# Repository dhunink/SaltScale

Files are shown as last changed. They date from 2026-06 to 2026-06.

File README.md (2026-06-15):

# SaltScale CadQuery

Parametric CadQuery model for a compact round salt-tank scale for a water softener.

Current mechanical direction: `concept_v5_cartridge_scale`.

Target hardware:
- four 50 kg Kiwi/SparkFun-style load sensors
- round platform for a 290 mm diameter brine/salt tank
- printable quadrant segments, each below 200 x 200 x 200 mm
- removable sensor cartridges with support-free retainers
- side-access electronics bay for ESP32-C3, HX711, battery holder, button, and LED

The physically validated sensor-cartridge baseline is:

```text
cad/src/concept_v5_cartridge_scale.py
cad/exports/concept_v5_cartridge/step/concept_v5_cartridge_assembly.step
cad/exports/concept_v5_cartridge/stl/concept_v5_sensor_cartridge.stl
cad/exports/concept_v5_cartridge/stl/concept_v5_sensor_retainer_clip.stl
```

The older v1-v4 CAD and print-test artifacts are retained for traceability, but
they are no longer the active design. Start with:

```text
docs/project_state_summary.md
docs/concept_v5_cartridge_scale.md
docs/concept_v5_system_architecture.md
docs/archive/concept_v4_legacy_index.md
```

## Build in GitHub Codespaces

Open this repository in Codespaces. The devcontainer installs CadQuery and the small export script.

```bash
python cad/export_concept_v5_cartridge.py
```

Generated files appear in:

```text
cad/exports/
```

## Main parameters

Edit `cad/src/concept_v5_cartridge_scale.py`.

## Design intent

The load path must be:

```text
tank -> upper ring -> load puck -> load sensor -> cartridge -> lower base -> floor
```

Cartridge retainers, cable guides, lift-retention features, and alignment walls
must not bypass the sensor under normal weighing load.

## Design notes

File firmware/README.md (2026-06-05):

# SaltScale Firmware

Firmware is intentionally not implemented yet.

The first firmware task is a bench-only hardware bring-up sketch for:

- Seeed Studio XIAO ESP32C3.
- SparkFun HX711.
- SparkFun Load Sensor Combinator.
- Four 50 kg load sensors.

Initial firmware goal:

- Read raw HX711 values.
- Print raw values over USB serial.
- Avoid Wi-Fi.
- Avoid deep sleep.
- Avoid battery handling.
- Avoid calibration logic.
- Avoid MQTT or product behavior.

See:

- `docs/hardware-bringup-v0.md`

Do not start battery optimization, enclosure electronics, or final calibration until the raw four-sensor bridge is proven on the bench.

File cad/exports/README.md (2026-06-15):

# SaltScale CAD Exports

Generated CAD exports are intentionally kept in the repository so builders can inspect and slice the current design without installing CadQuery first.

## Current Baseline

Active architecture: `concept_v5_cartridge_scale`.

Recommended first STEP to inspect:

```text
cad/exports/concept_v5_cartridge/step/concept_v5_cartridge_assembly.step
```

Validated printable cartridge parts:

```text
cad/exports/concept_v5_cartridge/stl/concept_v5_sensor_cartridge.stl
cad/exports/concept_v5_cartridge/stl/concept_v5_sensor_retainer_clip.stl
```

Current validated details:

- Four-sensor cartridge architecture.
- Measured sensor body: about `34.07 mm` wide and `6.84 mm` thick.
- Raised sensor-cartridge locator walls: `7.1 mm` above the cartridge floor.
- Support-free over-wall cartridge retainer.
- Physical test result: sensor fit is snug with only minimal movement.

Still experimental:

- Upper-ring load puck retention.
- The `0.20 mm` hand-tight keyhole test is the best tested puck fit so far:
  it does not fall out when inverted, but it is still removable by hand and is
  not yet considered a captive/hand-tight final solution.
- `0.35 mm` and `0.50 mm` hand-tight keyhole variants are too loose.
- PETG did not flex enough for the intended side-slide insertion; current tests
  only install by pressing the puck in from above.

## Folder Map

### `concept_v5_cartridge/`

Current baseline exports for the removable sensor cartridge concept.

### `active/`

Legacy active design from the previous v4 architecture. It is retained as prior
art until the full v5 ring replaces it.

Legacy architecture: `concept_v4_integrated_joining`.

Recommended first STEP to inspect:

```text
cad/exports/active/step/concept_v4_one_quadrant_assembly.step
```

Active printable STLs:

```text
cad/exports/active/stl/concept_v4_lower_segment_0.stl
cad/exports/active/stl/concept_v4_upper_segment_0.stl
cad/exports/active/stl/concept_v4_support_grate_bar_x.stl
cad/exports/active/stl/concept_v4_support_grate_bar_y.stl
cad/exports/active/stl/concept_v4_lower_pad.stl
cad/exports/active/stl/concept_v4_upper_pad.stl
cad/exports/active/stl/concept_v4_sensor_quarter_turn_clip.stl
cad/exports/active/stl/concept_v4_sensor_placeholder.stl
cad/exports/active/stl/concept_v4_kiwi_sensor_reference_v1.stl
```

Active v4 includes:

- Four-sensor floating upper/lower architecture.
- Integrated M3 segment joining.
- Top-access upper M3 button-head screws.
- Captured standard M3 nuts.
- No heat-set inserts or dowels by default.
- Support grate clearance at `0.4 mm per side`.
- Round Cup upper-carrier locator retired from active geometry; the upper segment is flat in the sensor area.
- Upper integrated M3 lugs are same-plane with the main upper segment body for flat printing.
- Dimensionally representative `kiwi_sensor_reference_v1` in concept_v4 assemblies.
- Real-sensor stack using `6.84 mm` sensor thickness.
- Removable upper pad with `40 mm` body, `36 mm` upper locating lobe, and `12 mm` contact boss; the pad STL is print-oriented for support-free printing.
- Lower pad revised to `36 mm` rounded-square support.
- Sensor locator revised around the measured `34.07 mm` body with `0.2 mm per side` current test clearance.
- Front sensor locator posts now act as pivots for separate quarter-turn retention clips; clips are anti-lift/handling retention only and are not part of the weighing load path.
- Integrated seam locator clearance validated at `0.3 mm per side`.

### `validated/`

Older validation artifacts that represent accepted v4-era decisions. Some of
these decisions still inform v5, but this folder is not the current print list.

Examples:

```text
cad/exports/validated/stl/test_m3_captured_nut_v1.stl
cad/exports/validated/stl/support_grate_fit_0p4mm_per_side.stl
cad/exports/validated/stl/sensor_station_locator_v3.stl
cad/exports/validated/stl/label_readability_coupon_v1.stl
```

### `experimental/`

Useful v4-era experiments that are not the active default.

Examples:

```text
cad/exports/experimental/stl/concept_v4_upper_lug_recess_block_v1.stl
cad/exports/experimental/stl/concept_v4_integrated_mini_seam_test_v1.stl
cad/exports/experimental/stl/concept_v4_upper_pad_12mm_boss_test_v2.stl
cad/exports/experimental/stl/concept_v4_lower_support_test_v1.stl
cad/exports/experimental/stl/concept_v4_real_sensor_locator_test_v2.stl
cad/exports/experimental/stl/concept_v4_sensor_clip_station_coupon_v2.stl
cad/exports/experimental/stl/printed_lower_seam_wedge_coupon_v2.stl
```

### `rejected/`

Rejected or superseded validation concepts kept for traceability.

Examples:

```text
cad/exports/rejected/stl/concept_v4_upper_pad_sensor_relative_test_v1.stl
cad/exports/rejected/stl/concept_v4_upper_pad_carrier_pocket_test_v1.stl
cad/exports/rejected/stl/concept_v4_upper_pad_pocket_chamfer_square_v1.stl
cad/exports/rejected/stl/concept_v4_upper_pad_pocket_side_entry_v1.stl
cad/exports/rejected/stl/concept_v4_upper_pad_pocket_round_cup_v1.stl
cad/exports/rejected/stl/support_grate_fit_0p6mm_per_side.stl
cad/exports/rejected/stl/support_grate_fit_0p8mm_per_side.stl
```

### `archive/`

Historical exports retained for traceability.

This includes:

- `platform_v1` through `platform_v6`.
- `concept_v1`, `concept_v2`, and `concept_v3` exports.
- Old sensor module exports.
- Old test coupons and duplicate migrated exports.

## Build Behavior

Run:

```text
python3 cad/build.py
```

The build writes future exports into:

```text
cad/exports/active/
cad/exports/validated/
cad/exports/experimental/
cad/exports/rejected/
cad/exports/archive/
```

The old `cad/exports/validation/` folder is superseded by the clearer `validated/`, `experimental/`, and `rejected/` folders.

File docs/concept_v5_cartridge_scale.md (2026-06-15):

# Concept v5 Cartridge Scale

Date: 2026-06-13

Updated: 2026-06-15

## Summary

`concept_v5_cartridge_scale` is a clean-sheet SaltScale concept using the same four Kiwi/SparkFun-style 50 kg sensors, but reorganized around replaceable sensor cartridges, removable load pucks, and a dry outer electronics pod.

The intent is to make the next prototype easier to print, easier to service, and less sensitive to accidental preload around the real sensor body.

## Architecture

- Four-sensor floating upper/lower annular scale.
- Four printed lower segments and four printed upper segments.
- One removable sensor cartridge per quadrant.
- One removable load puck per sensor.
- Outer electronics pod for HX711/MCU/battery/connector packaging.
- No upper-to-lower fasteners.
- Overload stops remain lower-only and sit `1.0 mm` below the upper carrier underside.

## Sensor Cartridge

The cartridge is a separate printable tray:

- Sensor body reference: `34.07 mm` wide, `6.84 mm` thick.
- V2 physical-test corrections:
  - Underside protrusions treated as `4.95 mm` diameter, `1.0 mm` high.
  - Protrusion spacing treated as approximately `18.8 mm` center-to-center.
  - Cartridge relief pockets are widened to `7.0 mm` diameter to absorb measurement and print tolerance.
- V3/final-candidate physical-test corrections:
  - Cartridge footprint reduced to `42 x 39 mm`, close to the compact physical test print.
  - Cartridge side rails reduced to `2.0 mm` above the floor so they do not enter the sensor envelope.
  - Low lateral bumpers locate the sensor with `1.25 mm` nominal clearance instead of squeezing it.
  - Two cable-side posts accept a separate keeper clip.
  - The keeper clip sits `0.65 mm` above the measured sensor top, so it captures lift-out without preload.
- V4 lock-frame correction after physical test:
  - Fragile post-mounted keepers removed.
  - Cartridge footprint increased to `52 x 44 mm` to make room for robust boss supports.
  - Low pocket walls constrain horizontal sensor movement with `0.4 mm` nominal clearance.
  - Retainer is now a broad screw/pin-down frame, not two loose arms.
  - Retainer underside sits `0.35 mm` above the outer metal frame top and bottoms on printed bosses, not on the sensor.
  - Boss holes are `2.8 mm` pilot holes in the cartridge; retainer holes are `3.4 mm` clearance holes.
- V5 clamp correction after lock-frame physical test:
  - Horizontal sensor clearance reduced to `0.15 mm`.
  - Retainer now intentionally overlaps the inactive outer frame by `0.12 mm` for light clamp preload.
  - Boss shoulders lowered with the retainer so the clamp force reaches the sensor frame instead of bottoming plastic-on-plastic.
  - Retainer side/rear/front pads avoid the raised measuring bridge, center button, cable, and glue lump.
- V6 support-free screw-clamp correction:
  - Horizontal sensor clearance reduced further to `0.08 mm` per side.
  - Retainer is one connected flat frame, no disconnected clamp bars.
  - Retainer prints flat without support.
  - Mounting is explicit: two M3 clearance holes through the retainer into `2.8 mm` pilot holes in the cartridge bosses.
  - Long side rails and rear rail are materially connected to both screw eyes.
- V7 fit correction after printed screw-clamp test:
  - Locator clearance is now `0.0 mm` in the model to compensate for measured print fit play.
  - Side and rear locator walls are raised by `1.25 mm`, to `4.25 mm` above the cartridge floor.
  - Cable-side stops stay lower so the cartridge remains support-free and the retainer does not collide with them.
  - Retainer rails are shifted slightly inward and narrowed so they clear the raised walls while still pressing on the inactive outer sensor frame.
  - Bosses now include a `4.2 mm` collar through the retainer hole, protruding `1.25 mm` above the sensor-frame top so the clamp indexes on the boss instead of floating on the sensor.
- V8 cap-retainer correction after snug cartridge test:
  - Sensor cartridge dimensions are left unchanged because the sensor fit is now snug.
  - Retainer is widened into a flat, support-free cap with inner clamp rails and outer wall rails.
  - The raised cartridge walls pass through the gap between those rails instead of colliding with the clamp.
  - Retainer screw eyes are enlarged and tied into the outside rails for a stiffer part.
  - Retainer holes are opened to `5.1 mm`; cartridge boss collars now protrude `2.75 mm` above the sensor-frame top and pass through raised retainer rings.
  - Raised retainer rings add screw-area stiffness and make the boss registration more forgiving in print.
- V9 validated cartridge correction after over-wall physical test:
  - Locator wall height is now `7.1 mm` above the cartridge floor.
  - This is the default cartridge geometry, not a separate test variant.
  - The taller side and rear walls make the real sensor sit snugly with only minimal movement.
  - The over-wall retainer/cap remains support-free and registers around the raised walls.
  - This cartridge/retainer direction is accepted as the baseline for the whole concept.
- Cartridge assembly z: `5.0 mm`, with the sensor top at `16.84 mm`.
- Cable/glue side remains open.
- The sensor is carried by two outboard ledges under the flat perimeter frame, not by the earlier three-bar datum layout.
- The retainer frame is outside the active measuring bridge and avoids the cable/glue lump.
- Side rails slide into matching lower-segment receiver rails.

This should make the sensor serviceable without reprinting or disassembling the whole lower ring.

## Load Pucks

Status after 2026-06-15 PETG keyhole tests:

- The `0.20 mm` hand-tight keyhole variant is the best tested puck retention fit.
- The `0.35 mm` and `0.50 mm` variants are too loose.
- The `0.20 mm` puck does not fall out when the assembly is inverted.
- It is still loose enough to remove by hand without meaningful force, so it is not yet a true hand-tight captive mount.
- PETG does not flex enough for the intended side-slide insertion path; the puck can only be installed reliably by pressing it in from above.
- Therefore the puck interface remains an open design item. Do not treat the side-entry keyhole as validated yet.

Two puck styles are exported:

- `concept_v5_bridge_load_puck`: `12 x 24 mm` rounded bridge boss, intended to match the real raised bridge.
- `concept_v5_round_load_puck`: `12 mm` round boss, retained as a conservative baseline.

Both are standalone printable parts so force-contact tests do not require reprinting the upper segment.

In assembly orientation the bridge puck starts on the sensor top at `z = 16.84 mm`, its main body ends at the upper-carrier underside at `z = 25.0 mm`, and the upper locating lobe enters the support-free socket in the upper segment.

## Electronics Pod

The electronics pod is intentionally outside the salt-ring footprint:

- `78 x 42 x 16 mm` outer envelope.
- Hollow printed box with four cable-entry holes toward the scale.
- Two M3-ish lid screw bosses.

This is still a first-pass packaging envelope, not a sealed enclosure design.

## Exports

Generated files:

```text
cad/exports/concept_v5_cartridge/step/concept_v5_cartridge_assembly.step
cad/exports/concept_v5_cartridge/step/concept_v5_lower_segment_0.step
cad/exports/concept_v5_cartridge/step/concept_v5_upper_segment_0.step
cad/exports/concept_v5_cartridge/step/concept_v5_sensor_cartridge.step
cad/exports/concept_v5_cartridge/step/concept_v5_sensor_retainer_clip.step
cad/exports/concept_v5_cartridge/step/concept_v5_bridge_load_puck.step
cad/exports/concept_v5_cartridge/step/concept_v5_round_load_puck.step
cad/exports/concept_v5_cartridge/step/concept_v5_electronics_pod.step
```

Printable STL counterparts are in:

```text
cad/exports/concept_v5_cartridge/stl/
```

## First Physical Test Order

Print first:

```text
cad/exports/concept_v5_cartridge/stl/concept_v5_sensor_cartridge.stl
cad/exports/concept_v5_cartridge/stl/concept_v5_sensor_retainer_clip.stl
cad/exports/concept_v5_cartridge/stl/concept_v5_bridge_load_puck.stl
cad/exports/concept_v5_cartridge/stl/concept_v5_round_load_puck.stl
```

Check:

- Real sensor drops into the cartridge after normal cleanup.
- Cable/glue side remains free.
- Side and rear walls locate the sensor with minimal horizontal play. The `7.1 mm` wall version has been physically validated.
- Retainer drops over both boss collars and lightly clamps the inactive outer frame.
- Retainer rails do not touch the raised measuring bridge, center button, cable, or glue lump.
- Two screws or printed pins through the retainer holes hold the clamp down into the cartridge bosses.
- Bridge puck contacts the intended raised bridge/button area.
- Round puck remains a usable fallback.

Print second:

```text
cad/exports/concept_v5_cartridge/stl/concept_v5_lower_segment_0.stl
cad/exports/concept_v5_cartridge/stl/concept_v5_upper_segment_0.stl
```

Check cartridge slide-in feel, upper/lower clearance, and overload-stop gap before printing all quadrants.

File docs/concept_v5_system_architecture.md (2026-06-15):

# Concept v5 System Architecture

Date: 2026-06-13

Updated: 2026-06-15

## Design Decision

The puck is part of the upper load path and must be lightly captive in the upper ring. It must not be a loose part between the sensor and upper platform.

The capture feature must not become the normal force path. In normal weighing, force should travel:

```text
upper ring -> puck shoulder/contact -> sensor measuring bridge -> sensor cartridge -> lower ring
```

All other geometry is retention, assembly guidance, overload protection, or transport safety.

The sensor cartridge decision is now stronger than the puck decision: the `7.1 mm` raised-wall cartridge with the over-wall retainer is physically validated and should be treated as the concept-v5 baseline. The puck keyhole/captive concept is still experimental.

## Why The Keyhole Concept Is Suspicious

The first keyhole/T-slot coupon made the puck captive, but it also made the capture geometry look like a sliding fit in the load path. That is risky for a weighing design because sliding contact can add:

- lateral force into the sensor,
- friction and hysteresis,
- sensitivity to print tolerance and surface texture,
- overconstraint between the four sensor stations.

For a low-cost printed scale, a little clearance in non-load-bearing retainers is better than a precise sliding interface that accidentally carries load.

## Reference Principles

Common load-cell and weigh-module design guidance tends to converge on these principles:

- Introduce load as close as possible to the intended measuring axis.
- Avoid side loads, torque, bending moments, and force shunts.
- Use a defined load button, ball/cup, rocker, or similar contact when self-alignment matters.
- Let overload stops and transport retainers be separate from the normal measuring load path.
- Avoid overconstraining a floating platform; constrain only the degrees of freedom needed for safety and repeatability.

Useful reference families:

- Load-cell and weigh-module application guides from manufacturers such as HBK/HBM, Flintec, Interface, Rice Lake, Vishay/VPG, and METTLER TOLEDO.
- Kinematic coupling and exact-constraint design literature for the broader principle of avoiding overconstraint.
- OIML R60 and NIST Handbook 44 as standards context for load cells and weighing devices, though they are not product design tutorials.

## Proposed Mechanical Architecture

### Lower Ring

The lower ring is the fixed base.

- Holds four removable sensor cartridges.
- Carries overload stops.
- Carries wire routing and electronics interfaces.
- Segment joints should use printed sliding/wedge/dovetail features where possible, with minimal metal fasteners.
- It must never directly support the upper ring in normal weighing.

### Sensor Cartridge

The cartridge is a serviceable sensor station.

- Sensor is laterally snug in the printed pocket.
- Sensor is held down by the support-free over-wall retainer.
- The validated locator walls are `7.1 mm` above the cartridge floor.
- The 2026-06-15 print test confirmed that this wall height gives the desired snug sensor fit.
- Sensor bridge, button, glue, cable, and active flexing areas remain free.
- Cartridge and retainer are lower-ring components, not part of the upper load path.

### Captive Puck

The puck is retained by the upper ring but mechanically contacts the sensor.

- Puck lower face contacts the sensor bridge area.
- Puck upper shoulder/contact face carries load from the upper ring.
- Captive head/neck should prevent drop-out without becoming the normal force path.
- 2026-06-15 PETG tests showed that `0.20 mm` radial clearance is the best tested head fit; `0.35 mm` and `0.50 mm` are too loose.
- The `0.20 mm` puck stays in place when inverted but can still be removed by hand without meaningful force.
- The intended side-slide insertion path did not work in PETG; PETG gives too little and the puck installs only by top-down pressing.
- Therefore the puck is not yet a validated captive mount. The next concept should avoid relying on elastic side-slide insertion unless a compliant feature is added.

### Upper Ring

The upper ring is the floating load receptor.

- It carries the captive puck cages.
- It transfers load only through the four pucks.
- It has no normal contact with lower ring, cartridge retainers, or overload stops.
- It can include non-contact lateral guards, but those need measurable clearance.

### Upper/Lower Retention

The upper and lower rings need transport/lift retention, but not a rigid connection.

- Use printed safety clips or captive hooks at the perimeter.
- Retention features should have vertical free play in normal use.
- They should engage only when the scale is lifted, inverted, or overloaded.

### Overload Stops

Overload stops are independent lower-ring features.

- Set the free gap around `0.8-1.2 mm` initially.
- Stops should contact the upper ring before the sensor is permanently damaged.
- Stops should not touch during ordinary weighing.

## Next Test Direction

The next puck print should move away from the current rigid side-slide keyhole and test one of these directions:

- top-down insertion with a separate printed keeper or cover,
- a compliant latch/finger that is not in the load path,
- a two-piece upper-ring insert that captures the puck after placement,
- or a captive-but-serviceable puck that is retained by the final upper/lower assembly rather than by a snap/keyhole alone.

Success criteria:

- Puck cannot fall out when the upper ring is inverted.
- Puck cannot be removed without a deliberate service motion.
- Puck can still self-seat slightly on the sensor.
- Upper ring presses the puck via its load shoulder/contact face, not via the keeper.
- Retention can be printed without support and with minimal metal fasteners.
- No underside supports are required for any printed part.

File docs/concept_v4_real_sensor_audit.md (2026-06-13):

# Concept v4 Real Sensor Audit

Date: 2026-06-11

## Scope

This audit reviews the current `concept_v4` assembly after integrating `kiwi_sensor_reference_v1`.

It does not redesign concept_v4 and does not modify CAD. It evaluates the current geometry against the measured Kiwi/SparkFun-style sensor dimensions and the supplied reference photos.

Measured sensor inputs:

- Sensor body width: `34.07 mm`.
- Sensor body thickness: `6.84 mm`.
- Photos show a rounded outer metal frame, central sprung/load plate, central raised load button/bridge, and cable exiting from one side.

## 1. Actual Stack Geometry

Current CAD values:

| Feature | Current value |
| --- | ---: |
| Kiwi reference metal body | `34.07 x 34.07 x 6.84 mm` |
| Kiwi reference total body including cable visual | `58.07 x 34.07 x 6.84 mm` |
| Lower pad | `44.0 x 44.0 x 2.0 mm` |
| Upper pad | `56.0 mm diameter x 3.0 mm` |
| Round cup inner diameter | `56.9 mm` |
| Round cup outer diameter | `64.9 mm` |
| Round cup wall thickness | `4.0 mm` |
| Round cup height | `4.0 mm` |
| Sensor locator cavity, approximate | `39.0 x 39.0 mm` |

Current vertical stack positions:

| Feature | Z range |
| --- | ---: |
| Lower pad | `8.0..10.0 mm` |
| Kiwi reference sensor | `10.0..16.84 mm` |
| Upper pad | `22.0..25.0 mm` |
| Overload stop top | `21.0 mm` |

Important finding:

- The current stack still uses the old `12.0 mm` sensor-placeholder height for upper-pad placement.
- The real Kiwi reference is `6.84 mm` thick.
- Therefore the current assembly has a `5.16 mm` vertical gap between the top of the Kiwi sensor reference and the bottom of the upper pad.

That means the current assembly is not a physically closed weighing stack with the real sensor. This audit reports the issue but does not change the stack height.

## 2. Contact Analysis

### Upper pad to sensor

Current CAD contact:

- No contact.
- The upper pad bottom is at `z = 22.0 mm`.
- The Kiwi sensor top is at `z = 16.84 mm`.
- Gap: `5.16 mm`.

If the vertical stack were corrected without changing pad diameter, the upper pad would be very broad relative to the real sensor:

- Upper pad diameter: `56.0 mm`.
- Sensor body width: `34.07 mm`.
- Pad surplus over sensor width: `21.93 mm` total.

The photos suggest the intended load-sensitive region is the central raised button/bridge area, not the whole outer frame. A `56 mm` round pad is therefore likely too large for controlled loading. It may contact or overhang areas that should not receive the primary upper load.

Assessment:

- Current state: upper pad does not contact the sensor.
- Size: likely oversized.
- Load path confidence: low until upper contact geometry is redesigned and tested.

### Lower pad to sensor

Current CAD contact:

- The lower pad top is at `z = 10.0 mm`.
- The Kiwi sensor bottom starts at `z = 10.0 mm`.
- So the lower pad contacts the underside of the sensor reference.

Size comparison:

- Lower pad: `44.0 x 44.0 mm`.
- Sensor body: `34.07 x 34.07 mm`.
- Lower pad surplus: `9.93 mm` total, about `4.97 mm` per side.

The lower pad is oversized relative to the measured sensor body, but less dramatically than the upper pad. A broad lower support may be acceptable if the sensor is designed to sit on its outer frame. However, the current pad likely supports more of the sensor footprint than necessary.

Assessment:

- Current state: lower pad contacts the sensor.
- Size: somewhat oversized.
- Load path confidence: medium; verify against real sensor underside behavior.

### Does the load enter the intended sensor region?

Currently, no. Because the upper pad does not touch the sensor, the vertical load path is open in the CAD assembly.

After stack-height correction, the current upper pad diameter would likely be too broad to guarantee that load enters only through the intended central sensor region. The photos show a central raised button/bridge and a distinct outer frame. The upper contact should probably be smaller and centered on the load button/bridge region, but that is a future CAD change, not part of this audit.

## 3. Locator Analysis

Current approximate sensor locator cavity:

- CAD cavity target: `39.0 x 39.0 mm`.
- Measured sensor body: `34.07 x 34.07 mm`.
- Total clearance: `4.93 mm`.
- Clearance per side: `2.465 mm`.

This does not reflect the recently validated `0.3 mm per side` seam-locator philosophy. That validation applies to same-layer segment seam locators, not the sensor station. However, the sensor locator is now much looser than expected for a real sensor-shaped locator.

Current sensor locator implications:

- It will not precisely locate the real sensor.
- It may allow noticeable sensor sliding or rotation before load is applied.
- It may still be serviceable and tolerant, but it is not a controlled fit.
- The cable exit side remains directionally useful, but the sensor body clearance is too large for accurate positioning.

Assessment:

- Current state: serviceable but loose.
- Size: oversized.
- Load-path risk: medium, because sensor drift could affect repeatability or pad alignment.

## 4. Overload Stop Analysis

Current nominal geometry:

- Overload stop top: `z = 21.0 mm`.
- Upper pad bottom: `z = 22.0 mm`.
- Nominal unloaded clearance to the current upper pad: `1.0 mm`.

This is the intended overload travel before engagement in the old stack model.

With the real Kiwi sensor reference inserted, the stack is not closed:

- Kiwi sensor top: `z = 16.84 mm`.
- Overload stop top: `z = 21.0 mm`.
- Upper pad bottom: `z = 22.0 mm`.

Because the upper pad is currently floating `5.16 mm` above the sensor, overload-stop behavior is not physically meaningful until the sensor stack height is corrected. In the current assembly, the upper structure would have to move downward far more than intended before the sensor is even contacted.

Assessment:

- Current nominal stop gap: `1.0 mm` to upper pad.
- Real-sensor stack validity: not valid yet.
- Expected overload behavior: must be re-evaluated after upper pad/contact geometry is corrected.

## 5. Recommendations

### Upper pad

Classification: **CHANGE**

Reasons:

- Does not contact the real sensor in the current stack.
- Diameter is likely too large for the intended central load path.
- It may load the outer frame rather than the central load button/bridge if stack height is corrected without resizing.

Recommended next adjustment:

- Rework upper contact geometry around the real sensor height and central raised load region.
- Use the photos to target the central load button/bridge, not the entire outer frame.

### Lower pad

Classification: **REVIEW**

Reasons:

- It contacts the sensor correctly in Z.
- It is about `9.93 mm` wider than the measured sensor body.
- The broad support may be acceptable if it supports the lower outer frame, but this should be confirmed physically.

Recommended next adjustment:

- Check the real sensor underside and decide whether lower support should remain broad or become shaped to the metal frame.

### Round cup

Classification: **REVIEW**

Reasons:

- The cup is correct for the current `56 mm` upper pad.
- If the upper pad changes, the cup will almost certainly need to change with it.
- The cup itself is not the immediate problem; it is downstream of the upper pad diameter.

Recommended next adjustment:

- Do not change the cup independently.
- Revisit after choosing the corrected upper pad diameter/contact shape.

### Sensor locator

Classification: **CHANGE**

Reasons:

- Current cavity is about `39.0 mm` for a `34.07 mm` sensor body.
- Clearance is about `2.465 mm per side`, which is too loose for reliable positioning.
- It is serviceable, but not a precision locator.

Recommended next adjustment:

- Create a real-sensor locator revision using the `34.07 mm` measured body width.
- Keep enough PETG tolerance and cable clearance, but reduce body clearance substantially.
- Preserve outside removal and avoid any upper-to-lower bypass.

### Overload stops

Classification: **REVIEW**

Reasons:

- The intended nominal stop gap is `1.0 mm` to the current upper pad position.
- The current real-sensor stack has a `5.16 mm` vertical gap, so the overload-stop relationship is invalid until the stack is corrected.

Recommended next adjustment:

- Recalculate overload stop height only after upper pad and sensor contact geometry are corrected.
- Keep the overload stop concept, but do not trust the current stop height with the real sensor.

## What Is Already Correct

- The Kiwi sensor reference is now much closer to the real hardware than the old block placeholder.
- Cable exit direction is represented and remains compatible with outside service access.
- Lower pad and sensor currently meet in Z.
- Upper/lower architecture remains mechanically separate.
- No upper-to-lower load bypass has been introduced by the reference sensor model.
- The Round Cup concept remains mechanically clean, but it is tied to an upper pad that now appears too large.

## What Remains Oversized

- Upper pad: strongly oversized relative to the sensor body and likely load region.
- Sensor locator cavity: clearly oversized relative to the measured sensor body.
- Lower pad: moderately oversized, but may still be acceptable depending on sensor underside support.
- Round cup: oversized only because it follows the current oversized upper pad.

## What Should Be Adjusted Next

Next CAD work should focus on a real-hardware sensor station revision, not on the full ring:

1. Correct the vertical stack for the `6.84 mm` sensor thickness.
2. Redesign the upper pad/contact area around the central load region.
3. Tighten the sensor locator around the `34.07 mm` body while preserving outside removal.
4. Re-evaluate the lower pad support footprint.
5. Recalculate overload stop height after the corrected stack is defined.

Do not print a full concept_v4 segment until these real-sensor stack issues are resolved.

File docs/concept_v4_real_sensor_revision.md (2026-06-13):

# Concept v4 Real Sensor Revision

Date: 2026-06-11

## Summary

This revision updates `concept_v4` around the measured Kiwi/SparkFun-style sensor while preserving the existing SaltScale architecture.

Preserved architecture:

- Four-sensor floating upper/lower platform.
- Upper and lower remain mechanically separate.
- Integrated M3 segment joining remains unchanged.
- No heat-set inserts or metal dowels as default.
- No upper-to-lower fasteners, clips, bridges, or locator features.
- Round Cup upper-carrier geometry is retired; the upper segment remains flat in the sensor area.
- Upper pad is now carrier-located by a `36 mm` upper locating lobe and an open-to-inner-edge upper-carrier socket.
- Upper integrated M3 lugs are same-plane with the main upper segment body for flat printing.

Main real-sensor changes:

- Sensor thickness is now treated as `6.84 mm` instead of the old `12.0 mm` placeholder stack.
- The upper pad now reaches the sensor with a smaller central contact boss.
- The lower pad is reduced to a `36 mm` rounded-square support.
- The sensor locator is tightened around the measured `34.07 mm` sensor body.
- Overload stop height is recalculated for the corrected stack.

## Corrected Stack Height

Measured sensor dimensions used:

| Feature | Value |
| --- | ---: |
| Sensor body width | `34.07 mm` |
| Sensor body thickness | `6.84 mm` |

Corrected stack:

| Feature | Z range |
| --- | ---: |
| Lower pad | `8.00..10.00 mm` |
| Kiwi sensor reference | `10.00..16.84 mm` |
| Upper pad total | `16.84..25.00 mm` |
| Upper pad contact boss | `16.84..22.00 mm` |
| Upper pad 40 mm body and inward key | `22.00..25.00 mm` |
| Upper carrier underside | `25.00 mm` |

The old `5.16 mm` vertical gap is removed. The upper pad now contacts the intended upper load-entry region of the Kiwi reference stack.

## Upper Pad Revision

The previous `56 mm` flat upper pad was oversized as a force-contact surface.

The new active upper pad has two functional zones:

| Zone | Geometry | Purpose |
| --- | --- | --- |
| Upper body | `40 mm` round body, `3 mm` thick | Bears against the flat upper carrier underside and remains easy to handle |
| Lower contact boss | `12 mm` round boss, `5.16 mm` tall | Introduces load into the sensor's central raised button/bridge region |

The Round Cup carrier locator was removed from the active upper segment because it created downward cup/rim geometry that compromised flat, support-free printing. The active validation coupon is one standalone upper pad only:

- `40 mm` upper pad body.
- `36 mm` upper locating lobe for carrier-relative positioning.
- `12 mm` round lower contact boss.
- No upper-carrier cup geometry.

Chosen default: **`12 mm` round boss**.

Rationale:

- Smaller and cleaner than the old `56 mm` flat contact.
- Large enough to print reliably in PETG.
- Small enough to avoid intentionally loading the full outer sensor frame from above.
- Good first default before any more specialized bridge-shaped contact is proven.

## Lower Pad Revision

The previous `44 x 44 mm` lower pad was oversized for the measured `34.07 mm` sensor body.

The new active lower pad is:

- `36 x 36 mm` rounded square.
- `2 mm` thick.
- `4 mm` corner radius.

The lower support coupon compares the current lower support direction against alternatives:

- Current-style `44 mm` square reference.
- `36 mm` rounded-square support.
- `36 mm` frame/ring support with central relief.

Chosen default: **`36 mm` rounded-square support**.

Rationale:

- Close to the measured sensor body size while leaving practical tolerance.
- Simpler and less fragile than the frame/ring support.
- More likely to support the real lower frame evenly than a very small pad.
- Still needs physical confirmation with the real sensor underside.

## Sensor Locator Revision

The old locator cavity was about `39 mm`, giving roughly `2.465 mm per side` clearance around the measured sensor body. That was too loose for a real sensor locator.

The new active sensor locator uses:

- Sensor body reference width: `34.07 mm`.
- Default body clearance: `0.4 mm per side`.
- Approximate target cavity: `34.87 mm`.
- Low v3-style broken locator features.
- Open cable side with relief so the sensor can still be removed outward.

Multi-variant locator testing has been retired. The project now uses one practical default.

Chosen default: **`0.4 mm per side`**.

Rationale:

- The real Kiwi sensor is available for direct fit testing.
- Very loose fits are already known to be undesirable.
- `0.4 mm per side` is the active decision point: tight enough to locate, still PETG-realistic.
- Locator features position the sensor only; they must not carry vertical load.

## Overload Stop Revision

The overload stop height has been recalculated for the corrected real-sensor stack.

Current values:

| Feature | Value |
| --- | ---: |
| Upper carrier underside | `25.00 mm` |
| Overload stop top | `24.00 mm` |
| Nominal unloaded clearance | `1.00 mm` |
| Expected overload travel before engagement | `1.00 mm` |

The stops are lower-base-only features. They should not touch the upper carrier during normal unloaded assembly. Under overload, the floating upper structure can travel about `1 mm` before the stops engage.

## Validation Exports

New compact validation prints:

```text
cad/exports/experimental/stl/concept_v4_upper_pad_12mm_boss_test_v2.stl
cad/exports/experimental/stl/concept_v4_lower_support_test_v1.stl
cad/exports/experimental/stl/concept_v4_real_sensor_locator_test_v2.stl
```

Corresponding STEP files are exported in:

```text
cad/exports/experimental/step/
```

Active updated printable parts include:

```text
cad/exports/active/stl/concept_v4_upper_pad.stl
cad/exports/active/stl/concept_v4_lower_pad.stl
cad/exports/active/stl/concept_v4_lower_segment_0.stl
cad/exports/active/stl/concept_v4_upper_segment_0.stl
cad/exports/active/stl/concept_v4_kiwi_sensor_reference_v1.stl
```

Updated assembly STEP files:

```text
cad/exports/active/step/concept_v4_assembly.step
cad/exports/active/step/concept_v4_exploded_assembly.step
cad/exports/active/step/concept_v4_one_quadrant_assembly.step
```

## Recommended Print Order

Print first as one practical plate:

```text
cad/exports/experimental/stl/concept_v4_real_sensor_locator_test_v2.stl
cad/exports/experimental/stl/concept_v4_upper_pad_12mm_boss_test_v2.stl
```

Reason:

- Upper force introduction is the highest-risk real-sensor geometry.
- The `12 mm` round boss is now the active default; this print validates the single chosen pad rather than comparing alternatives.

Print second:

```text
cad/exports/experimental/stl/concept_v4_real_sensor_locator_test_v2.stl
```

Reason:

- The sensor must remain removable but not rattle around.

Print third:

```text
cad/exports/experimental/stl/concept_v4_lower_support_test_v1.stl
```

Reason:

- Lower support is important, but the current `36 mm` rounded-square default is less risky than the upper load-entry surface.

## Inspection Recommendation

Inspect first:

```text
cad/exports/active/step/concept_v4_one_quadrant_assembly.step
```

Check specifically:

- Upper pad boss contacts the central Kiwi load region.
- Upper pad body bears against the flat upper carrier underside while the `36 mm` upper lobe seats in the open-to-inner-edge socket; no Round Cup geometry remains active.
- Lower pad supports the sensor body without obvious cable/glue conflict.
- Sensor locator remains lower-only and does not touch the upper pad or carrier.
- Overload stops remain clear during normal assembly.

## Remaining Risks

- The exact load sensitivity of the central bridge/button must be tested physically.
- The underside support behavior of the real stamped metal sensor is still partly inferred from photos.
- The active `0.4 mm` sensor-locator clearance has already felt loose in one physical test; the separate `0.2 mm` v3 locator coupon is the next validation print.
- Overload stop behavior should be checked after the upper contact boss and locator are validated.
- PETG creep around the contact boss and pads remains untested.

## Sensor Retention Update

The next concept_v4 validation direction uses `0.2 mm` per-side sensor locator clearance and separate quarter-turn clips on the two front round posts. The clips are retention-only: they prevent accidental lift-out during handling, but they must not preload the Kiwi sensor or carry vertical measuring force. The sensor still rests on the lower pad and is loaded by the upper pad's 12 mm boss.

Print `cad/exports/experimental/stl/concept_v4_sensor_clip_station_coupon_v2.stl` with two copies of `cad/exports/active/stl/concept_v4_sensor_quarter_turn_clip.stl` before printing a full lower segment. Coupon v2 uses a larger cropped base so all fixed pillars and stops grow from solid printed geometry.

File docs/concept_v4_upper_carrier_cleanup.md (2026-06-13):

# Concept v4 Upper Carrier Cleanup

Date: 2026-06-11

## Summary

This cleanup resolves the upper-pad / upper-carrier integration issues in `concept_v4`.

The active design now uses:

- A support-free upper segment with no lower protruding upper seam lugs.
- A removable one-piece upper pad.
- A `40 mm` upper pad body.
- A `12 mm` lower contact boss for the Kiwi sensor load-entry region.
- A `36 mm` upper locating lobe on the pad.
- A matching open-to-inner-edge socket/notch in the upper carrier.

The Round Cup remains rejected as active geometry. There is no underside cup, no through-hole boss, no sensor-relative locator, no fragile tabs, and no separate retainer plug in the active design.

## What Was Removed

The cleanup removes the overlapping upper-pad concepts from the active assembly:

- Round Cup underside cup/rim geometry.
- Circular upper-pad land disk geometry.
- The earlier key-only notch that looked like a locator but did not positively engage the carrier.
- The separate upper-pad retainer plug experiment.
- Any floating disk-like construction bodies near the sensor stack.

No sensor-station, lower-pad, lower-base, support-grate, or integrated M3 seam architecture was redesigned.

## Final Retention Method

The upper pad is located by a drop-in open socket:

1. The upper pad has a `36 mm` upper locating lobe above the `40 mm` pad body.
2. The upper carrier has a matching open-to-inner-edge socket at each sensor station.
3. The socket is larger than the lobe by `0.6 mm per side`.
4. A `22 mm` throat connects the socket to the inner edge.

The lobe drops into the socket when the upper carrier is lowered onto the pad. The socket side walls constrain the pad laterally, so the pad cannot drift sideways during normal handling. The narrowed throat prevents the lobe from sliding out through the inner edge. The pad remains removable by lifting the upper carrier and taking the pad out by hand.

This is carrier-relative retention. It does not depend on the sensor for locating and does not create an upper-to-lower bypass.

## Assembly Explanation

Normal assembly order for one sensor stack:

1. Place the lower pad into the lower sensor station.
2. Place the Kiwi sensor on the lower pad with the cable exiting outward.
3. Place the upper pad on the sensor, with the `12 mm` boss facing downward.
4. Align the pad's `36 mm` upper lobe with the upper carrier's open socket.
5. Lower the upper carrier onto the upper pad.
6. Confirm the lobe is seated in the socket and the `40 mm` pad body bears against the flat underside of the upper carrier.

The measurement load path remains:

```text
upper carrier
-> 40 mm upper pad body/shoulder
-> 12 mm lower contact boss
-> Kiwi sensor central load region
-> lower pad
-> lower base
-> floor
```

The locating lobe is not intended as the primary force-contact surface; it is a lateral positioning feature.

## Why It Is Support-Free

Upper segment:

- The upper integrated M3 lugs are same-plane with the main upper segment body.
- There is no material below the main upper body plane.
- The pad locator is an open-to-inner-edge socket, not a blind underside pocket.
- The socket and throat are through-cuts, so they do not create hidden bridges.

Upper pad:

- The active STL is exported in print orientation with the upper locating lobe on the bed.
- The `40 mm` body overhangs the `36 mm` lobe by about `2 mm per side`, which is intended to print as a short support-free PETG shoulder.
- The `12 mm` contact boss prints upward.

## Why It Is Mechanically Robust

The socket avoids thin fragile tabs. The estimated material around the risky areas is:

| Feature | Value |
| --- | ---: |
| Socket diameter | `37.2 mm` |
| Throat width | `22.0 mm` |
| Throat-to-socket shoulder per side | `7.6 mm` |
| Outer radial web beyond socket | `23.4 mm` |

The socket is open to the inner edge, so there is no isolated thin wall at the inside of the ring. The outer radial web remains broad, and the M3 nut pockets are not near the pad socket.

If physical testing shows the pad is too loose, adjust socket clearance first. The load path should remain unchanged.

## Verification

CAD checks after cleanup:

| Check | Result |
| --- | ---: |
| Upper segment material below main body plane | `0.0 mm^3` |
| Upper pad vs upper segment overlap | `0.0 mm^3` |
| Upper/lower segment overlap | `0.0 mm^3` |
| Support grate vs upper segment overlap | `0.0 mm^3` |
| Support grate vs lower segment overlap | `0.0 mm^3` |
| Sensor top / upper pad bottom | `16.84 mm / 16.84 mm` |

Printable envelopes:

| Part | Approximate print envelope |
| --- | ---: |
| Upper segment 0 | `178.99 x 158.11 x 14.00 mm` |
| Upper pad | `40.00 x 40.00 x 11.16 mm` |

## Next Inspection

Inspect these files first:

```text
cad/exports/active/stl/concept_v4_upper_segment_0.stl
cad/exports/active/stl/concept_v4_upper_pad.stl
cad/exports/active/step/concept_v4_one_quadrant_assembly.step
```

Physical validation should confirm:

- The upper segment lies flat in PrusaSlicer.
- The upper pad prints without supports.
- The pad drops into the carrier socket by hand.
- The pad cannot slide out through the inner-edge throat during normal handling.
- The `12 mm` boss still lands on the intended Kiwi sensor load-entry region.

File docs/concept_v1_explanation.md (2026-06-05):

# Concept v1 Explanation

Date: 2026-06-04

## Purpose

`concept_v1` is a clean-sheet mechanical demonstrator for SaltScale. It does not continue from `platform_v6` and does not reuse previous CAD geometry.

The model demonstrates a four-sensor floating annular scale:

- Lower annular base segments sit on the floor.
- Upper annular carrier segments float above the lower base.
- Four load sensors sit between the two structures.
- Local guide rails constrain lateral movement without carrying vertical load.
- Overload stops protect sensors after about 1 mm of travel.
- A segmented centering lip helps place a 290 mm salt container but is part of the floating upper carrier only.

Generated source:

- `cad/src/concept_v1.py`

Generated exports:

- `cad/exports/step/concept_v1.step`
- `cad/exports/stl/concept_v1.stl`

## Load path

Normal load path:

```text
salt container
-> floating upper annular carrier
-> upper contact pad
-> load sensor
-> lower contact pad
-> lower annular base
-> floor
```

The lower base and upper carrier are separate structures. During normal operation, the only intended vertical load transfer between them is through the four sensor stacks.

The local guide rails are lower-base features. They sit beside each sensor station and are open on the outer radial side for service. They should prevent sensor shear and gross lateral motion, but their tops remain below the upper carrier/contact pad path so they are not normal-load supports.

The overload stops are intentional bypasses. They rise from the lower base and stop about 1 mm below the upper contact pad. If the upper carrier deflects too far, the upper pad contacts the stops and protects the sensor. Readings during stop contact should be considered invalid.

## Assembly sequence

Recommended prototype assembly sequence:

1. Print four lower base segments and four upper carrier segments.
2. Join the lower segments into a lower annular base.
3. Place lower contact pads into the four sensor stations.
4. Place one load sensor on each lower contact pad.
5. Place upper contact pads on the sensors.
6. Join the upper carrier segments separately.
7. Lower the upper carrier onto the four upper contact pads.
8. Confirm that guide rails do not touch the upper carrier or upper pads in the unloaded state.
9. Confirm about 1 mm overload-stop clearance.
10. Place the empty salt container, tare, then calibrate with a known mass.

The exported `concept_v1.stl` is a combined assembly visualization, not a final print plate. Production exports should later split fixed base parts, floating top parts, pads, and sensor placeholders into separate STL files.

## Sensor strategy

The recommended sensor strategy is four low-cost bathroom-scale style 50 kg sensors wired as a combined bridge into one HX711.

Why four sensors:

- Four support points give stable support to a round salt container.
- The summed reading is less sensitive to off-center salt distribution than a central PETG transfer structure.
- Commodity sensors are cheap and easy to replace.
- One HX711 can read the combined bridge, keeping electronics and firmware simple.
- Calibration can start with tare plus one known weight.

Why not one central loadcell:

- A good central single-point loadcell costs more.
- It requires exact vendor-specific mounting geometry.
- It asks the printed PETG structure to move all off-center load into one central sensor.
- It makes the first mechanical validation more expensive and less hobby-friendly.

Why not two or three sensors:

- Two sensors need a third support or hinge that risks bypassing the sensors.
- Three sensors are mechanically stable, but common low-cost bathroom-scale bridge wiring is naturally four-sensor.

## Why this concept is better than platform_v6

`platform_v6` should not be used as the basis for future CAD. It mixed useful four-sensor intent with unclear printable/serviceable geometry.

`concept_v1` improves on it in the following ways:

- It starts from a clean upper/lower separation.
- It makes the floating upper carrier explicit.
- It makes the lower floor reference explicit.
- It avoids a fused sensor-module assembly as the core model.
- It removes central-loadcell parameter inheritance.
- It uses an annular carrier instead of a heavy full disk.
- It keeps sensors near the container perimeter where they are mechanically useful.
- It leaves the center open for lower material use, inspection, and later wiring.
- It makes guide features lateral-only in intent.
- It treats overload stops as intentional, measurable bypasses.

The concept is also more honest: it does not pretend to be final. It is a mechanical architecture demonstrator that should be validated by printing one sensor station or one quarter stack before full-platform work.

## CAD dimensions

Assembled model envelope:

- 320.0 x 320.0 x 34.0 mm

Main printable segment envelopes from the current parametric model:

- Lower base segment: about 159.2 x 159.2 x 6.0 mm
- Upper carrier segment: about 153.0 x 153.0 x 12.0 mm

These fit within the Prusa MK4 200 x 200 x 200 mm constraint.

## Critical limitations

- The sensor placeholder is still generic: 38 x 38 x 12 mm.
- The contact pads are represented as simple rectangular pads; real metal pad geometry should be validated.
- No segment seam hardware is finalized.
- No electronics bay is included.
- No cable routing is included.
- No water/salt corrosion protection is included yet.
- The annular top support must be checked against the actual salt container bottom. If the container bottom is too flexible, add removable cross-spokes or a thin support disk only after testing.

## Recommended next validation

Print one lower sensor-station quadrant and one matching upper carrier quadrant. Install one real sensor and pads. Test:

- Sensor insertion/removal.
- Upper carrier seating.
- Guide clearance.
- Overload-stop gap.
- Repeatability under 5 kg, 10 kg, and 20 kg test loads.
- Off-center load response within that quadrant.

Only after that should the design move toward complete segmented exports or electronics packaging.

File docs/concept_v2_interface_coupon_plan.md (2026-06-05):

# Concept v2 Interface Coupon Plan

Date: 2026-06-05

## Summary

`concept_v2_interface_coupons.py` adds small print-first coupons for the critical mechanical interfaces in `concept_v2`.

These coupons do not replace the full platform CAD. They are intended to validate the risky interfaces before printing full lower or upper ring segments.

Generated coupon exports:

| Coupon | Approximate envelope |
| --- | ---: |
| `sensor_station_coupon_v2` | 179.0 x 132.0 x 21.0 mm |
| `upper_lower_stack_coupon_v1` | 195.0 x 157.0 x 21.0 mm |
| `lower_seam_coupon_v1` | 84.0 x 120.0 x 8.0 mm |
| `upper_seam_coupon_v1` | 84.0 x 120.0 x 8.0 mm |
| `support_grate_fit_coupon_v1` | 160.0 x 52.0 x 8.0 mm |
| `centering_lip_coupon_v1` | 31.7 x 74.5 x 14.0 mm |

All coupons fit within the Prusa MK4 200 x 200 x 200 mm print envelope.

## General print notes

- Print in PETG.
- Use the same nozzle, layer height, perimeters, and hole compensation intended for the prototype.
- Print the coupons flat in their exported orientation.
- Multi-body STL files are intentional print kits. Keep the bodies separated on the bed; do not merge them into a single fused part.
- Deburr holes, pockets, guide edges, and pad contact faces before measurement.
- Record slicer material and print time estimates before printing full segments.

## 1. sensor_station_coupon_v2

Export files:

- `cad/exports/stl/sensor_station_coupon_v2.stl`
- `cad/exports/step/sensor_station_coupon_v2.step`

What it tests:

- Current fixed sensor station geometry.
- Dummy 38 x 38 x 12 mm sensor fit.
- Guide rail clearance.
- Lower pad seating on solid base material.
- Upper pad handling.
- Overload stop clearance.
- Open-side service access.

How to print it:

- Print flat in the exported orientation.
- No supports should be required.
- Print the included dummy sensor and pad pieces in the same job or separate them in the slicer if preferred.

Hardware or dummy parts needed:

- Included printed dummy sensor.
- Included printed lower pad.
- Included printed upper pad.
- Calipers.
- Paper strips or feeler gauges.

What to measure:

- Dummy sensor sliding clearance between guide rails.
- Dummy sensor removal path through the open outer side.
- Lower pad flatness and seating.
- Upper pad fit without binding on guides or stops.
- Vertical clearance from upper pad/upper carrier reference to overload stop tops.

Pass/fail criteria:

- Dummy sensor inserts and removes by hand without prying.
- Lower pad sits flat on solid base.
- Upper pad can be placed and removed without scraping guide walls.
- Guide walls start on solid printed base with no unsupported bottom bridges.
- Overload stops are not contacted in the nominal dummy stack.

Likely CAD change if it fails:

- Increase guide clearance.
- Move guide rails or overload stops outward.
- Add a non-trapping pad locator.
- Change overload stop height or make stop clearance adjustable.

## 2. upper_lower_stack_coupon_v1

Export files:

- `cad/exports/stl/upper_lower_stack_coupon_v1.stl`
- `cad/exports/step/upper_lower_stack_coupon_v1.step`

What it tests:

- Local upper-to-lower stack behavior.
- Floating upper carrier patch sitting on upper pad, dummy sensor, lower pad, and lower base.
- Clearance between upper carrier and lower guide/stops.
- Confirmation that no unintended upper-to-lower contact occurs outside the sensor stack.

How to print it:

- Print flat in the exported orientation.
- No supports should be required.
- Assemble the separate pieces after printing: lower station, lower pad, dummy sensor, upper pad, upper carrier patch.

Hardware or dummy parts needed:

- Included printed dummy sensor and pads.
- Included printed upper carrier patch.
- Paper strips or feeler gauges.
- Small household test weights if doing a light compression check.

What to measure:

- Clearance between upper carrier patch and guide walls.
- Clearance between upper carrier patch and overload stops.
- Whether paper strips slide freely around all non-load-path features.
- Whether the upper patch rocks on the dummy stack.

Pass/fail criteria:

- Upper patch contacts only the upper pad in the nominal stack.
- Paper strips show no normal contact at guide rails, stops, or lower-base features.
- Dummy stack remains removable after the upper patch is lifted.
- No upper-to-lower screw, dowel, or printed feature is needed to hold the stack together.

Likely CAD change if it fails:

- Increase vertical clearance around guides.
- Reduce upper carrier patch overhang near station features.
- Adjust pad size or station position.
- Lower overload stops or increase nominal stack height control.

## 3. lower_seam_coupon_v1

Export files:

- `cad/exports/stl/lower_seam_coupon_v1.stl`
- `cad/exports/step/lower_seam_coupon_v1.step`

What it tests:

- Two shortened lower-ring segment edges.
- Top-side M3 heat-set insert pockets.
- 4 mm dowel sockets.
- Separate lower seam bridge plate.
- Lower-to-lower joining without touching the upper structure.

How to print it:

- Print flat with insert pockets facing up.
- No supports should be required.
- Leave the bridge plate separate from the two segment-edge blocks.

Hardware or dummy parts needed:

- M3 heat-set inserts, if available.
- M3 screws matching the insert depth.
- 4 mm metal dowel, drill shank, or printed dowel stand-in.
- Soldering iron for insert installation.
- Calipers.

What to measure:

- Insert pocket diameter and depth after printing.
- Dowel socket diameter and depth after printing.
- Insert installation effort and whether bosses split.
- Bridge plate hole alignment.
- Seam gap and block alignment after installing bridge and dowel.

Pass/fail criteria:

- Inserts install straight without splitting the PETG.
- Screws engage inserts without bottoming out.
- Dowel is a controlled slip fit, not a forced press fit.
- Bridge plate clamps both segment edges without visible bending.
- Joined blocks remain flat on the table.

Likely CAD change if it fails:

- Adjust insert pocket diameter/depth.
- Increase boss diameter.
- Increase dowel socket clearance.
- Increase bridge plate thickness or width.
- Move seam hardware away from edges.

## 4. upper_seam_coupon_v1

Export files:

- `cad/exports/stl/upper_seam_coupon_v1.stl`
- `cad/exports/step/upper_seam_coupon_v1.step`

What it tests:

- Two shortened upper-ring segment underside edges.
- Underside M3 heat-set insert pockets.
- 4 mm dowel sockets.
- Separate upper seam bridge plate.
- Upper-to-upper joining without any lower-base connection.

How to print it:

- Print flat with the underside pocket face upward.
- Treat the upward-facing pocket face as the underside of the real upper carrier.
- No supports should be required.

Hardware or dummy parts needed:

- M3 heat-set inserts, if available.
- M3 screws.
- 4 mm metal dowel, drill shank, or printed dowel stand-in.
- Soldering iron for insert installation.
- Calipers.

What to measure:

- Insert pocket access from the underside face.
- Insert seating depth and straightness.
- Dowel socket fit.
- Bridge plate screw access.
- Whether the bridge plate can be removed and reinstalled repeatedly.

Pass/fail criteria:

- Inserts can be installed from the underside face without damaging the coupon.
- Bridge plate attaches and detaches cleanly.
- Dowel alignment is repeatable.
- The coupon validates an upper-only joint; no lower-base part is needed.

Likely CAD change if it fails:

- Revise underside insert pocket access.
- Change bridge plate screw layout.
- Increase local material around insert pockets.
- Add chamfers or lead-ins to dowel sockets.

## 5. support_grate_fit_coupon_v1

Export files:

- `cad/exports/stl/support_grate_fit_coupon_v1.stl`
- `cad/exports/step/support_grate_fit_coupon_v1.step`

What it tests:

- A small upper-carrier section with a removable support-grate channel.
- A representative support-grate arm tab.
- Whether a top-side removable grate interface can locate cleanly while remaining serviceable.

How to print it:

- Print flat in the exported orientation.
- No supports should be required because the channel is open from the top and one side.
- Insert the grate tab by hand after printing.

Hardware or dummy parts needed:

- Included printed grate tab.
- Calipers.
- Actual salt container, if available.

What to measure:

- Grate tab sliding clearance.
- Whether the tab seats flat in the channel.
- Whether the tab rattles, jams, or rocks.
- Whether the channel would trap salt debris.
- Whether the interface is easy to remove by hand.

Pass/fail criteria:

- Grate tab inserts and removes by hand.
- Grate tab sits flush enough that the container cannot catch on an edge.
- Interface remains upper-only and does not imply any lower-base contact.
- Channel does not create an obvious salt trap that cannot be cleaned.

Likely CAD change if it fails:

- Increase channel clearance.
- Change grate arm width or thickness.
- Add a lead-in chamfer.
- Replace the channel with a simpler loose/removable grate feature.
- Add debris relief before integrating this interface into the full upper carrier.

## 6. centering_lip_coupon_v1

Export files:

- `cad/exports/stl/centering_lip_coupon_v1.stl`
- `cad/exports/step/centering_lip_coupon_v1.step`

What it tests:

- Curved section of the 300 mm centering lip.
- Upper carrier/lip print quality.
- Contact feel against the real salt container wall.
- Whether the lip height and wall thickness are practical in PETG.

How to print it:

- Print flat in the exported orientation.
- No supports should be required.
- Use the same perimeter settings intended for the upper carrier.

Hardware or dummy parts needed:

- Actual salt container, if available.
- Calipers.
- Paper strips for contact checks.

What to measure:

- Lip thickness after printing.
- Lip height after printing.
- Curved inner face quality.
- Clearance against the container wall.
- Whether the lip scuffs, jams, or leaves too much play.

Pass/fail criteria:

- Lip prints cleanly without supports.
- Inner curved face contacts or clears the real container as intended.
- Container can be lifted away without snagging.
- Lip is stiff enough for handling and not sharp enough to scrape the container.

Likely CAD change if it fails:

- Increase inner diameter clearance.
- Reduce lip height.
- Add a chamfer or roundover.
- Increase wall thickness if PETG feels fragile.
- Replace continuous lip with shorter centering tabs.

## Recommended print order

1. `sensor_station_coupon_v2`
2. `upper_lower_stack_coupon_v1`
3. `lower_seam_coupon_v1`
4. `upper_seam_coupon_v1`
5. `support_grate_fit_coupon_v1`
6. `centering_lip_coupon_v1`

First print:

```text
sensor_station_coupon_v2
```

Reason:

The sensor station is still the highest-risk local interface. If dummy sensor fit, guide clearance, pad seating, or overload stop clearance is wrong, full lower segments and full quadrants should not be printed yet.

## Do not validate with full ring segments yet

Do not print full `concept_v2` lower or upper ring segments until these coupons have answered the local interface questions. A full segment print should come only after:

- Dummy sensor insertion/removal passes.
- Upper-to-lower stack clearance passes.
- Seam hardware geometry is plausible.
- Support grate and centering lip assumptions are checked against the real container.

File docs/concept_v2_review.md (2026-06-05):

# Concept v2 Review

Date: 2026-06-04

## Summary

`concept_v2` converts `concept_v1` from an architecture demonstrator into a realistic mechanical prototype candidate.

It keeps the preferred architecture:

- Four Kiwi/SparkFun style 50 kg sensors.
- One floating upper carrier.
- One separate lower floor base.
- Four replaceable sensor stations.
- No upper-to-lower fasteners.
- No electronics packaging yet.

It rejects one optimistic part of `concept_v1`: the fully open annular carrier. A pure annulus is clean and low-material, but it assumes the salt container bottom is stiff enough to span the center opening. That is not safe for a general domestic salt container. `concept_v2` adds a removable upper-only support grate. The grate supports uncertain container bottoms while remaining part of the floating upper structure, so it does not bypass the sensors.

CAD source:

- `cad/src/concept_v2.py`

Requested exports:

- `cad/exports/step/concept_v2_assembly.step`
- `cad/exports/stl/concept_v2_lower_segment_0.stl`
- `cad/exports/stl/concept_v2_upper_segment_0.stl`
- `cad/exports/stl/concept_v2_sensor_station.stl`

## Architecture

Normal load path:

```text
salt container
-> removable upper support grate and/or upper annular carrier
-> upper contact pad
-> 50 kg load sensor
-> lower contact pad
-> lower annular base
-> floor
```

`concept_v2` uses the same four-sensor measurement principle as `concept_v1`, but it adds the mechanical features needed for a real prototype:

- Four lower annular base segments.
- Four floating upper annular carrier segments.
- Four replaceable sensor stacks at 45, 135, 225, and 315 degrees.
- A removable upper support grate for center-bottom support.
- Lower-only seam bridge plates.
- Upper-only seam bridge plates.
- M3 heat-set insert pockets.
- 4 mm dowel sockets for alignment.
- Local overload stops.
- Open-sided sensor guide rails.

## Sensor realism

The model assumes a representative 38 x 38 x 12 mm sensor envelope. That matches the repository's current placeholder for Kiwi/SparkFun style 50 kg sensors, but it is not a vendor-verified final dimension.

Each sensor station includes:

- A lower contact pad.
- A sensor placeholder with an outward cable-exit tab.
- An upper contact pad.
- Tangential guide rails.
- An inner radial stop.
- An open outer side for removal.
- Four local overload stops.

The sensor is not screwed, glued, or trapped in the printed base. It is located laterally by the guide rails and vertically by the contact pad stack. In normal use, the upper carrier compresses the stack. For service, removing the upper carrier segment exposes the upper pad and sensor.

## Segment joining

### Lower ring

The lower ring segments include top-side M3 heat-set insert pockets and 4 mm dowel sockets near the radial seams. Separate lower seam bridge plates sit on the lower base only. These plates join lower-to-lower segments and never touch the upper carrier.

Purpose:

- Keep lower segments aligned on the floor.
- Resist seam spreading during handling.
- Avoid any upper-to-lower load bypass.

### Upper ring

The upper ring segments include underside M3 heat-set insert pockets and 4 mm dowel sockets. Separate upper seam bridge plates attach only to the underside of the floating upper carrier.

Purpose:

- Keep upper carrier segments aligned.
- Make the upper carrier removable as an assembly or by segment.
- Avoid hardware on the top surface where the container sits.
- Avoid any connection to the lower base.

### Dowel strategy

4 mm metal dowels are modeled as sockets, not permanent trapped pins. They should be used for alignment and repeatability, not as the primary structural clamp. M3 fasteners and bridge plates provide the clamp.

## Annular support review

`concept_v1` used an open annular upper carrier. That is attractive because it saves filament and keeps the load path visible.

For `concept_v2`, the open annulus is judged insufficient as the default prototype. The unknown is the salt container bottom. Many domestic containers have molded bottoms, feet, ribs, or flexible central regions. A 20-35 kg salt load can make an unsupported center sag, rock, or settle unevenly.

Decision: add a removable upper-only support grate.

The grate:

- Is part of the floating upper system.
- Is not connected to the lower base.
- Prints flat.
- Fits within the Prusa MK4 envelope.
- Can be removed for inspection or revised after testing.
- Supports the container center without changing the sensor architecture.

This is deliberately conservative. If physical testing proves the container bottom is rigid and only loads the perimeter, the grate can be omitted later.

## Load path review

The primary load path is clear:

- Upper parts carry load to upper pads.
- Upper pads load sensors.
- Sensors load lower pads.
- Lower pads load lower base.

Designed bypasses:

- Local overload stops engage only after approximately 1 mm of upper-pad travel.

Rejected bypasses:

- No M3 screw bridges from upper to lower.
- No dowels from upper to lower.
- No shared wall between upper and lower.
- No electronics bay ribs touching both structures.

The seam bridge plates are same-layer only: lower-to-lower or upper-to-upper.

## Printability

Measured from the current CAD:

- Full assembly envelope: about 320.0 x 320.0 x 39.0 mm.
- `concept_v2_lower_segment_0`: about 159.1 x 159.1 x 21.0 mm.
- `concept_v2_upper_segment_0`: about 153.1 x 153.1 x 14.0 mm.
- `concept_v2_sensor_station`: about 96.0 x 96.0 x 21.0 mm.
- Removable support grate: about 178.0 x 178.0 x 4.0 mm.

All listed parts fit within the Prusa MK4 200 x 200 x 200 mm envelope.

PETG-friendly choices:

- Flat lower and upper segments.
- No intentionally trapped support cavities.
- Thick guide rails.
- Simple vertical insert pockets.
- Simple cylindrical dowel sockets.
- Support grate prints flat.

Known printability caveat:

- The lower segment includes guide rails and overload stops rising from the base. These are support-free when printed flat, but their dimensional accuracy must be checked because they define sensor clearance and overload behavior.

## Why this is better than concept_v1

`concept_v1` proved the architecture. `concept_v2` adds the minimum real-world assembly features:

- Separate upper and lower segment joining.
- Heat-set insert locations.
- Dowel alignment.
- A real serviceable sensor station.
- An explicit answer to the flexible-container-bottom problem.
- A printable sensor-station coupon.

It remains simple. It avoids electronics. It does not chase cosmetic CAD.

## Why this is still not final

`concept_v2` is a prototype candidate, not release CAD.

Still missing:

- Exact purchased sensor dimensions.
- Exact metal contact pad choice.
- Screw lengths and insert part numbers.
- Dowel tolerance validation.
- Wiring strain relief.
- Salt/water protection.
- Full segmented production export set.
- Physical calibration data.

## Recommendation

Proceed to physical validation with `concept_v2_sensor_station.stl` first. Do not print the full four-segment assembly until one station proves sensor fit, pad seating, overload clearance, and repeatability.

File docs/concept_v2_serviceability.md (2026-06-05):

# Concept v2 Serviceability

Date: 2026-06-04

## Serviceability goal

A single failed sensor must be replaceable without reprinting the platform and without disassembling the lower base.

`concept_v2` supports that goal by keeping sensors accessible from above after removing the local floating upper carrier segment. The sensor is guided, not trapped.

## Replaceable parts

Per sensor station:

- 50 kg load sensor.
- Lower contact pad.
- Upper contact pad.
- Sensor wiring/connector, if used.

Shared parts:

- Upper carrier segment.
- Lower base segment.
- Upper seam bridge plates.
- Lower seam bridge plates.
- Removable support grate.

## Normal assembly sequence

1. Print and clean all lower base segments.
2. Install M3 heat-set inserts into the lower segment top-side pockets.
3. Assemble the lower ring using lower seam bridge plates, M3 screws, and 4 mm dowels.
4. Place lower contact pads into the four sensor stations.
5. Place one sensor in each station with its cable exiting outward.
6. Place upper contact pads on the sensors.
7. Print and clean all upper carrier segments.
8. Install M3 heat-set inserts into the upper segment underside pockets.
9. Assemble the upper carrier using underside upper seam bridge plates, M3 screws, and 4 mm dowels.
10. Attach or place the removable upper support grate on the floating upper carrier.
11. Lower the upper carrier assembly onto the four upper pads.
12. Confirm that the upper carrier contacts only the upper pads in normal unloaded condition.
13. Confirm overload stop clearance.
14. Install the salt container and calibrate.

## Single sensor replacement procedure

1. Remove the salt container.
2. Power down the electronics.
3. Remove the removable upper support grate if it blocks access to the target upper segment screws.
4. Loosen or remove the two upper seam bridge plates adjacent to the target upper segment.
5. Lift off the target upper carrier segment.
6. Remove the upper contact pad from the failed sensor.
7. Disconnect the failed sensor wiring.
8. Slide or lift the failed sensor out through the open outer side of the station.
9. Inspect the lower contact pad and pocket for salt debris or wear.
10. Replace the lower contact pad if worn or corroded.
11. Insert the replacement sensor with its cable exiting outward.
12. Reinstall the upper contact pad.
13. Reinstall the upper carrier segment.
14. Reinstall the upper seam bridge plates and dowels.
15. Reinstall the support grate.
16. Reconnect wiring.
17. Power on, tare, and recalibrate.

The lower base ring can remain assembled throughout this procedure.

## Why sensors are not trapped

The station uses:

- Two tangential guide rails.
- One inner radial stop.
- An open outer side.
- Removable upper pad.
- Removable upper carrier.

There is no printed cap over the sensor and no upper-to-lower fastener crossing the station. The sensor is held in place by gravity, lateral guides, and normal compression when the upper carrier is installed.

## Maintenance checks

At each sensor replacement or annual inspection:

- Check that guide rails are not worn or salt-crusted.
- Check that the lower contact pad is flat and clean.
- Check that the upper contact pad is flat and clean.
- Check that the overload stops are not polished or compressed from normal use.
- Check that dowels still slip into sockets without forcing.
- Check that M3 inserts are not loose.
- Check sensor wiring strain relief.

## Failure modes addressed

- Failed sensor: removable after lifting one upper segment.
- Worn contact pad: replaceable without reprinting ring segments.
- Loose upper seam: service upper-only seam plates.
- Loose lower seam: service lower-only seam plates without disturbing sensors.
- Damaged support grate: removable and replaceable as an upper-only part.

## Failure modes not fully addressed yet

- Cable strain relief is not finalized.
- Waterproofing is not designed.
- Salt dust sealing is not designed.
- Connector style is not selected.
- Long-term PETG creep around insert pockets is untested.

## Serviceability recommendation

Use connectors or a small terminal block for each sensor during the prototype phase. Direct soldering is cheaper, but it makes single-sensor replacement much worse and works against the serviceability goal.

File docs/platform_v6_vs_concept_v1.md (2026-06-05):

# Platform v6 vs Concept v1

Date: 2026-06-04

## Summary

`platform_v6` and `concept_v1` both point toward a four-sensor SaltScale, but they are not equivalent designs.

`platform_v6` is an exploratory segmented lower-platform model that embeds `sensor_module_v3` assemblies into each quadrant. It improves over earlier CAD by adding dowel holes and blind M3 pockets, but it does not cleanly model a floating upper carrier, and its exported segment appears to fuse serviceable sensor parts into one printable body.

`concept_v1` is a clean-sheet architecture demonstrator: separate lower annular base, separate floating upper annular carrier, four open sensor stations, lateral guide features, pads, and overload stops. It is less complete as a production printable part set, but the load path and maintenance model are much clearer.

Overall winner: `concept_v1`.

## Category winners

| Category | Winner |
| --- | --- |
| Printability | `concept_v1` |
| Serviceability | `concept_v1` |
| Load path clarity | `concept_v1` |
| Calibration complexity | `concept_v1` |
| Expected accuracy | `concept_v1` |
| Expected PETG creep behavior | `concept_v1` |
| Assembly complexity | `concept_v1` |
| Hardware cost | Tie, slight edge to `concept_v1` |
| Long-term maintainability | `concept_v1` |

## Printability

### platform_v6

Strengths:

- Each segment fits the Prusa MK4 envelope; prior checks measured about 171.8 x 171.8 x 42.0 mm.
- It is exported as four large quadrant segments, which is a familiar print workflow.
- Dowel holes and blind M3 pockets are already represented.

Weaknesses:

- The segment is a fused CAD compound containing the sensor module assembly, including pads and sensor placeholder.
- Internal pocket surfaces in a fused STL may not represent the actual serviceable printed parts.
- Automatic global filleting can fail silently or create hard-to-debug export differences.
- It is not obvious what should actually be printed versus what is assembly visualization.

### concept_v1

Strengths:

- Main segments are smaller: lower segments are about 159.2 x 159.2 x 6.0 mm; upper segments are about 153.0 x 153.0 x 12.0 mm.
- Annular geometry uses less material than a fuller platform.
- Upper and lower structures are naturally printable as separate flat parts.
- The model separates architecture roles even though final print exports still need to be split.

Weaknesses:

- It has more printable bodies once converted into a real part set.
- Seam hardware is not finalized.
- The current STL is an assembly demonstrator, not a final print plate.

Winner: `concept_v1`.

Reason: both fit the printer, but `concept_v1` has simpler, flatter, smaller structural parts and a clearer route to printable part separation.

## Serviceability

### platform_v6

Strengths:

- The intended v6 docs describe removable sensors and pads.
- Sensor stations are located one per segment, which is a good service concept.

Weaknesses:

- The actual `platform_v6_segment()` unions the entire `sensor_module_v3` assembly into each segment.
- A fused STL with placeholder sensor and pads contradicts sensor replacement.
- The model does not clearly define how the upper load-bearing platform is removed or separated.
- A real failed sensor replacement procedure is ambiguous.

### concept_v1

Strengths:

- The upper carrier and lower base are separate by design.
- Sensor stations are open on the outer radial side.
- Sensors, pads, lower base, upper carrier, guide features, and overload stops have distinct roles.
- Service sequence is straightforward: remove container, lift upper carrier, replace pad/sensor, recalibrate.

Weaknesses:

- Final retention features for pads and sensors are not yet designed.
- Repeated disassembly will need durable seam hardware.

Winner: `concept_v1`.

Reason: `platform_v6` talks about serviceability; `concept_v1` actually expresses it in the architecture.

## Load path clarity

### platform_v6

Strengths:

- It uses the `sensor_module_v3` idea, which has a good local pad -> sensor -> pad load path.
- It includes overload-stop concepts and avoids through-depth M3 holes in the lower plate.

Weaknesses:

- It does not clearly model the floating top/load-entry structure.
- Ribs rise high in the model, but their relationship to a future top plate is undefined.
- It still uses central-loadcell-derived parameters for rib clearance.
- The sensor module is inserted as a full assembly, blurring which bodies are real load path parts and which are placeholders.

### concept_v1

Strengths:

- The normal load path is explicit: container -> floating upper carrier -> upper pad -> sensor -> lower pad -> lower base -> floor.
- Upper and lower structures are separated.
- Guide rails are lateral features, not normal-load supports.
- Overload stops are intentional bypasses with a defined clearance target.

Weaknesses:

- The model still needs physical validation of guide and stop clearances.

Winner: `concept_v1`.

Reason: `concept_v1` makes the vertical load path legible at platform scale, not just at the local sensor module.

## Calibration complexity

### platform_v6

Strengths:

- If implemented as a normal four-sensor bridge, electronics could be simple: one HX711 and one summed reading.

Weaknesses:

- Because the upper load path is incomplete/unclear, calibration behavior is hard to predict.
- Accidental load bypass or fused printed contact geometry could produce nonlinear readings.
- Segment-to-segment stiffness variation may matter if load enters through unclear ribs or pads.

### concept_v1

Strengths:

- Four sensors can still be summed into one HX711 reading.
- The floating top architecture reduces ambiguity about what is being calibrated.
- Tare plus one known mass should be enough for first functional fill-level readings.
- Off-center validation is straightforward: place the same weight at several angular positions.

Weaknesses:

- Four cheap sensors still need correct bridge wiring.
- It will not be a precision scale without multi-position validation.

Winner: `concept_v1`.

Reason: same basic electronics, fewer mechanical unknowns.

## Expected accuracy

### platform_v6

Strengths:

- Four sensor placement at quadrant centers is directionally good.
- Local module stops and pads could be accurate if separated and printed correctly.

Weaknesses:

- Current CAD does not define the true container-to-sensor load entry.
- Fused placeholders make the exported geometry poor evidence for real contact behavior.
- The platform may have unmodeled bypasses once a top structure is added.
- Accuracy will be sensitive to how someone interprets and modifies the incomplete model.

### concept_v1

Strengths:

- The top carrier floats explicitly on the four sensor stacks.
- Sensor radius is near the perimeter, which should help with eccentric salt loads.
- The annular upper carrier reduces central-span load-transfer ambiguity.
- The design invites simple off-center testing and correction.

Weaknesses:

- The annular support may not suit every salt container bottom; a flexible container bottom could need cross-spokes or a thin top support.
- Contact pads need metal or validated printed surfaces for stable repeatability.

Winner: `concept_v1`.

Reason: expected accuracy is governed more by load-path control than by CAD detail count. `concept_v1` controls the load path better.

## Expected PETG creep behavior

### platform_v6

Strengths:

- It has a lot of printed material and ribs, so it may be stiff in the short term.
- Sensor modules are locally supported.

Weaknesses:

- More printed material in unclear load-bearing positions can create long-term drift paths.
- Printed pads and fused contact surfaces are suspect under constant 20-35 kg loading.
- If ribs or guide walls accidentally share vertical load, PETG creep could change calibration over time.

### concept_v1

Strengths:

- The intended compressive load path is short and localized through pads and sensors.
- The annular top reduces large central PETG spans.
- It naturally encourages metal contact pads at the sensor interfaces.
- Creep-prone printed features are easier to classify as either structural support, guide, or overload stop.

Weaknesses:

- The upper annular carrier still needs enough thickness and contact area to avoid local sag.
- PETG seams and pad pockets need physical validation.

Winner: `concept_v1`.

Reason: less ambiguous PETG in the measuring path means lower creep risk.

## Assembly complexity

### platform_v6

Strengths:

- Fewer apparent printed segment parts.
- Dowels and M3 pockets are already sketched.

Weaknesses:

- Apparent simplicity is misleading if sensors and pads are fused into the print.
- The real assembly sequence for a working scale is underdefined.
- It is unclear how to install real sensors after printing the segment.
- It is unclear how upper and lower load-bearing structures are assembled without bypassing sensors.

### concept_v1

Strengths:

- More parts, but each part has a clear role.
- Assembly is conceptually simple: lower ring, pads, sensors, upper pads, upper ring.
- Sensor access is not an afterthought.
- Upper-to-lower fasteners are avoided.

Weaknesses:

- Eight main ring segments plus pads and sensors is more handling than four fused segments.
- Final seam hardware still needs design.

Winner: `concept_v1`.

Reason: `concept_v1` has more pieces but less confusion. For hobby assembly, understandable beats nominally fewer parts.

## Hardware cost

### platform_v6

Expected hardware:

- Four low-cost 50 kg sensors.
- HX711.
- ESP32-C3.
- Dowel pins.
- M3 screws.
- Contact pads or washers if implemented serviceably.

### concept_v1

Expected hardware:

- Four low-cost 50 kg sensors.
- HX711.
- ESP32-C3.
- Sensor contact pads or washers.
- Seam hardware for upper ring and lower ring.
- Possible dowels or keys later.

Winner: Tie, slight edge to `concept_v1`.

Reason: sensor/electronics cost is essentially the same. `concept_v1` may use less filament because it is annular, but it may need more ring-joining hardware. Net cost difference is small.

## Long-term maintainability

### platform_v6

Strengths:

- It has more local development history and supporting docs.
- It includes some practical seam/alignment ideas.

Weaknesses:

- It inherits stale central-loadcell parameter assumptions.
- It depends on `sensor_module_v3` as an inserted assembly rather than a clean platform-level design.
- It is easy for future agents to misunderstand what is printable, what is placeholder, and what is validated.
- Fixing it requires untangling prior CAD decisions.

### concept_v1

Strengths:

- Clean source with local parameters for the concept.
- Separate upper/lower architecture is easier to reason about.
- Maintainers can evolve sensor station details without preserving obsolete platform geometry.
- The model is honest about being a concept and not a production print package.

Weaknesses:

- It is newer and has less accumulated testing.
- It needs follow-up work to become a complete printable part set.

Winner: `concept_v1`.

Reason: maintainability starts with clear architecture. `platform_v6` carries too much ambiguity and historical baggage.

## Overall recommendation

Use `concept_v1` as the basis for the next mechanical design phase. Do not continue `platform_v6`.

The best next step is not to polish either full platform. Instead, derive a small physical validation coupon from `concept_v1`: one lower sensor station, one matching upper carrier section, one real sensor, and real contact pads. Validate fit, serviceability, overload clearance, repeatability, and off-center response.

Only after that should the project create production-style split STL exports, seam hardware, electronics mounting, or firmware.

## Critical caution

`concept_v1` wins the architecture comparison, but it is not finished product CAD. It is a cleaner foundation. The current exports demonstrate the mechanical idea; they should not be treated as final printable release files.

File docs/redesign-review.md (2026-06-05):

# SaltScale Redesign Review

Date: 2026-06-04

## Summary

SaltScale should be redesigned as a four-sensor floating annular scale:

- Four low-cost bathroom-scale style 50 kg load sensors.
- One HX711 reading the four sensors as a combined bridge, like a bathroom scale.
- A floating upper annular carrier that supports the salt container.
- A separate lower annular base that sits on the floor.
- Four removable sensor stations between upper and lower structures.
- No electronics bay, battery compartment, firmware assumptions, or central loadcell geometry in the first mechanical concept.

This is not a continuation of `platform_v6`. The previous CAD should be treated as exploratory evidence only. The new design keeps the useful high-level idea of distributed low-cost sensing, but discards the previous geometry, fused module exports, central-loadcell leftovers, and unclear upper/lower plate relationship.

The reason to choose four sensors is not that prior work chose four sensors. It is the best fit for the product goals: low cost, stable support for a large round container, forgiving off-center loading, one-HX711 electronics, and simple two-point calibration.

## Evaluation of current repository concepts

### Central single-point loadcell concepts

The early repository direction used a true central single-point loadcell. That is attractive electrically because one four-wire bridge loadcell connects directly to one HX711. It is also mechanically clean in abstract form: top platform -> loadcell -> lower base.

For SaltScale, it is not the best first open-source architecture:

- A good single-point loadcell for a 290 mm container is more expensive than commodity bathroom-scale sensors.
- The printed structure must deliver all off-center loads into the central loadcell without side loading it.
- A large PETG platform can introduce compliance and creep that changes calibration under eccentric loading.
- Loadcell mounting geometry becomes vendor-specific very early.
- The design becomes less hobby-friendly if exact metal loadcell dimensions, screw torque, or machined contact interfaces matter.

Verdict: discard for the first open-source target. It may be a premium alternate architecture later.

### Four-sensor exploratory concepts

The later repository work moved toward four 50 kg bathroom-scale style sensors. That direction is mechanically and economically stronger for this application:

- The scale naturally supports the container at multiple points.
- The load is shared around the perimeter, reducing demands on any single PETG span.
- The electrical bridge can still be read by one HX711.
- A one-weight calibration is plausible because the sum of four sensors is the useful measurement.
- Cheap replacement sensors are available from hobby suppliers and marketplace vendors.

The problem is not the four-sensor idea. The problem is the previous implementation. `platform_v6` appears to union serviceable sensor parts into one body, does not clearly implement a floating top carrier, and still inherits stale central-loadcell parameter ideas. It is useful as a warning, not as a base.

Verdict: keep the distributed sensing principle, discard the geometry.

### Two-sensor or three-sensor alternatives

Two sensors are tempting because they reduce hardware count, but they create worse mechanical constraints. A two-point support needs a third non-measuring support, flexure, hinge, or sliding constraint. That support either bypasses the sensors or makes readings sensitive to tank placement.

Three sensors provide a stable plane with fewer sensors than four, but common low-cost half-bridge bathroom-scale wiring is naturally four-sensor. Three-sensor wiring either needs different full-bridge load cells, multiple ADC channels, or more calibration complexity.

Verdict: discard for the main design.

## What should be kept

- Keep the 320 mm class outer envelope for a 290 mm container.
- Keep Prusa MK4/PETG segmentation as a hard manufacturing constraint.
- Keep the 300 mm-ish centering clearance idea, but implement it as a non-load-bearing side guide on the floating top carrier.
- Keep the low-cost four-sensor direction.
- Keep the concept of local overload stops with about 1 mm normal clearance.
- Keep the principle that sensors are replaceable and not trapped.
- Keep one HX711 as the default electronics path.
- Keep mechanical validation before electronics or firmware.

## What should be discarded

- Discard `platform_v6` geometry.
- Discard `sensor_module_v3` geometry as a final module shape, even though its load-path lesson is useful.
- Discard all central single-point loadcell assumptions for the default architecture.
- Discard fused STL exports that include placeholder sensors or service parts as one solid.
- Discard any upper-to-lower fastening scheme.
- Discard electronics bays and battery doors until the mechanical scale is physically validated.
- Discard full solid disks unless testing proves the container needs center support.

## Recommended final architecture

Use a four-sensor annular floating platform.

Parts:

- Four printable lower annular base segments.
- Four printable upper annular carrier segments.
- Four sensor stations at 45, 135, 225, and 315 degrees.
- Four low-cost 50 kg load sensors.
- Four lower contact pads and four upper contact pads, preferably metal washers/plates or printed placeholders during validation.
- Four sets of local overload stops.
- Optional M3 seam hardware only within the upper ring or within the lower ring. No hardware should connect upper to lower.

Normal stack:

```text
salt container
-> floating upper annular carrier
-> upper contact pad
-> load sensor
-> lower contact pad
-> lower annular base
-> floor
```

The recommended first CAD concept is an annular ring rather than a full disk. It supports the outer region of the salt container, saves material, reduces print time, and makes the load path visible. A center support can be added later only if a real salt container bottom proves too flexible.

## Mechanical design rationale

The salt container is large, slow-moving, and normally static. It does not need a precision lab scale mechanism. It needs a repeatable, low-cost, robust support that survives utility-closet conditions and gives useful fill-level measurements.

An annular floating top ring is a better first structure than a solid platform:

- It uses less PETG.
- It fits naturally into four quarter segments.
- It keeps sensors close to the perimeter, where container loads are most likely to land.
- It avoids a large central printed span that can creep under 20-35 kg.
- It leaves the center open for inspection and later wiring routes.

The lower ring should be a separate floor reference. It should locate sensor stations and resist lateral motion, but it should never be tied to the upper ring except through sensors and overload stops.

Sensor stations should be open or removable from above/outside. A sensor should not be installed by trapping it between permanent printed features. In the first physical prototype, the sensor should be replaceable with hand tools after the container is removed.

## Load path rationale

The primary load path must pass through the sensors during normal use. Every upper-to-lower feature must be classified:

- Sensor stack: normal load path.
- Guide walls or guide pins: lateral alignment only, with vertical clearance.
- Overload stops: intentional bypass only after about 1 mm of upper-carrier travel.
- Segment screws: join upper-to-upper or lower-to-lower only, never upper-to-lower.
- Centering lip: side guidance only, not vertical support.

Four sensors improve eccentric-load behavior. Salt may settle unevenly, and users may not place the container perfectly. With four support points, the summed bridge output is less sensitive to where the load lands than a two-sensor or central PETG transfer structure.

## Serviceability rationale

Serviceability should be designed around replacement of the cheapest failure-prone parts:

- Load sensors.
- Contact pads.
- Fasteners.
- Battery/electronics later.

The sensor station should allow this sequence:

1. Remove the salt container.
2. Lift or remove the affected upper ring segment.
3. Remove the upper contact pad.
4. Slide or lift out the sensor.
5. Replace the sensor and pad.
6. Reassemble and recalibrate.

No sensor should be bonded permanently into the structure. Adhesive can be used for optional pad retention, but not as the primary service strategy.

## Cost estimate

Prices are volatile, so these are rough June 2026 maker-scale estimates, not a purchasing lock. Supplier spot checks used:

- SparkFun generic 50 kg load sensor: about USD 6.25 each at retail: https://www.sparkfun.com/products/10245
- SparkFun HX711 board: about USD 11.50 at retail: https://www.sparkfun.com/sparkfun-load-cell-amplifier-hx711.html
- Seeed Studio XIAO ESP32-C3: about USD 4.99: https://www.seeedstudio.com/seeed-xiao-esp32c3-p-5431.html
- General PETG filament range: roughly USD 15-40 per kg depending on supplier and quality.

Estimated prototype cost, excluding shipping and batteries:

| Item | Conservative maker retail | Low-cost marketplace path |
| --- | ---: | ---: |
| 4x 50 kg load sensors | USD 25 | USD 6-16 |
| HX711 module | USD 12 | USD 1-4 |
| ESP32-C3 board | USD 5-8 | USD 3-6 |
| PETG, 300-600 g | USD 5-24 | USD 5-15 |
| Fasteners, pads, wire | USD 6-15 | USD 4-10 |
| Total | USD 48-79 | USD 19-47 |

The four-sensor architecture is still cheaper than a quality single-point loadcell design when the mechanical mounting risk and vendor-specific hardware are included.

## Risk analysis

### Highest risks

- Sensor package variation: cheap sensors vary in shape, wiring, and contact geometry. Mitigation: keep the sensor station parametric and validate against the purchased sensor before finalizing.
- PETG creep: long-term load can relax printed contact features. Mitigation: use metal contact pads, broad compression surfaces, and avoid printed flexures as measuring elements.
- Off-center calibration error: four sensors reduce this but do not eliminate it. Mitigation: test with weights at several positions on the container footprint.
- Moisture/corrosion: utility closets and brine tanks are not friendly environments. Mitigation: keep sensors away from liquid paths, add drainage gaps, and use corrosion-resistant pads/fasteners.

### Medium risks

- Wiring four half-bridge sensors incorrectly can produce unstable readings. Mitigation: document the bridge wiring and use a known bathroom-scale wiring pattern.
- The annular top may not support every container bottom shape. Mitigation: validate with the actual container; add removable cross-spokes or a thin top disk only if needed.
- Segment seams can introduce uneven support if assembled poorly. Mitigation: use dowels or simple seam keys within the upper ring and lower ring separately.
- Overload stops can become accidental normal-load bypasses if printed too tall. Mitigation: measure stop gaps and keep them adjustable in CAD.

### Lower risks

- Build volume: four 90-degree annular segments fit comfortably under 200 x 200 x 200 mm.
- Firmware complexity: one HX711 and summed sensor output keeps firmware simple once mechanics are stable.

## Recommendation

Proceed with `concept_v1`: a clean-sheet four-sensor annular floating platform. Build it as a mechanical demonstrator only. The next physical validation should be a single sensor station and one quarter of the annular upper/lower stack, not a complete product print.

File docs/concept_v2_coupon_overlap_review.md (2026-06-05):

# Concept v2 Coupon Overlap Review

Date: 2026-06-05

## Summary

The reported `UPPER PAD` and `SENSOR DUMMY` overlap was caused by the printable coupon layout, not by the `concept_v2` architecture.

The overlap existed in the labeled multi-body print-kit coupon:

- `sensor_station_coupon_v2`

The same layout issue also existed in:

- `upper_lower_stack_coupon_v1`

It did not exist in the actual `concept_v2` assembled load stack.

## What caused the overlap

The coupon exports place separate printable bodies on one print plate. In the previous layout, the `UPPER PAD` body was placed too close to the `SENSOR DUMMY`.

Previous `sensor_station_coupon_v2` layout:

```text
SENSOR DUMMY center: (52, 8)
UPPER PAD center:    (52, 48)
```

The sensor dummy is about `38 x 38 mm`, plus a cable-exit tab. The upper pad is `56 x 56 mm`.

That means:

- Sensor dummy Y range was about `-11..27 mm`.
- Upper pad Y range was about `20..76 mm`.
- The bodies overlapped by about `7 mm` in Y.
- Because both bodies were exported flat on the build plate, their Z ranges also overlapped.

This created real overlapping STL volume in the print-kit export.

## Was concept_v2 itself affected?

No.

In `concept_v2.py`, the real assembly stack is vertical:

```text
lower pad:   z 8..10 mm
sensor:      z 10..22 mm
upper pad:   z 22..25 mm
```

Those parts touch at the intended interfaces but do not overlap in volume.

The unlabeled `concept_v2_sensor_station` export is also not the source of the pad/sensor overlap. It is the station base coupon only. The overlap was in the labeled validation kit that includes the dummy pad and sensor pieces.

## Which body should move

The `UPPER PAD` should move.

Reason:

- The sensor dummy position is useful as a reference for the dummy sensor and cable-exit shape.
- The lower pad already had adequate clearance from the dummy sensor.
- Moving the upper pad is only a print-plate layout change.
- It does not change pad size, sensor dummy size, station geometry, clearances, or load path.
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

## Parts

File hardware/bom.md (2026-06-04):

# SaltScale v1 hardware shortlist

## Frozen direction

- MCU: Seeed Studio XIAO ESP32C3
- ADC: SparkFun Load Cell Amplifier HX711
- Loadcell: true 50 kg single-point loadcell, recommended first target: Henk Maas LA360-C-50kg
- Power: 3x AA lithium cells in side-access holder; final holder still to be selected by physical size and connector
- UI: 1 momentary pushbutton + 1 low-current LED

## Notes

Do not use the cheap SparkFun/Kiwi/TinyTronics 50 kg bathroom-scale load sensor as the primary mechanical target for this round platform. It is a 3-wire half-bridge style sensor normally used in sets, not the clean single-point platform loadcell wanted for SaltScale v1.

The CadQuery model currently assumes placeholder dimensions for the Henk Maas LA360-C-50kg. Verify the datasheet before final print.

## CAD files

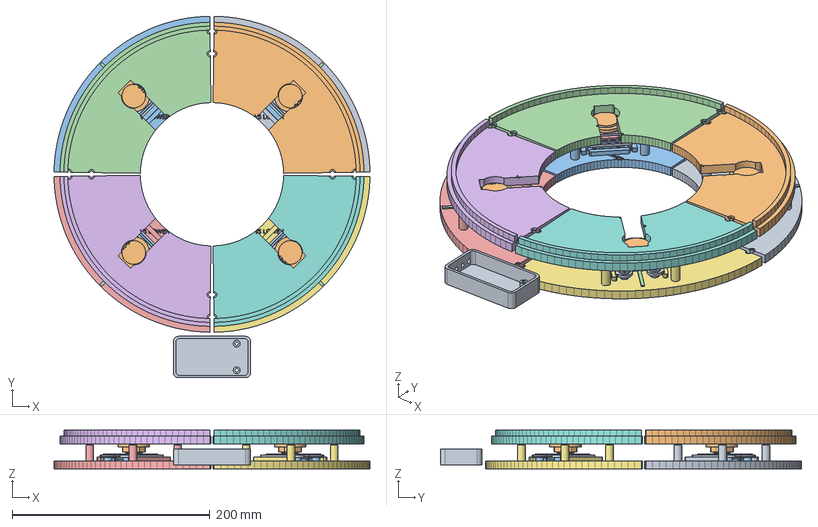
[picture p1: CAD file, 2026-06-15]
cad/exports/concept_v5_cartridge/step/concept_v5_cartridge_assembly.step
320.0 x 366.0 x 39.0 mm
lower_segment_0_part
upper_segment_0_part
sensor_cartridge_0_part
kiwi_sensor_0_part
sensor_retainer_clip_0_part
bridge_load_puck_0_part
lower_segment_1_part
upper_segment_1_part
sensor_cartridge_1_part
kiwi_sensor_1_part
sensor_retainer_clip_1_part
bridge_load_puck_1_part
lower_segment_2_part
upper_segment_2_part
sensor_cartridge_2_part
kiwi_sensor_2_part
sensor_retainer_clip_2_part
bridge_load_puck_2_part
lower_segment_3_part
upper_segment_3_part
sensor_cartridge_3_part
kiwi_sensor_3_part
sensor_retainer_clip_3_part
bridge_load_puck_3_part
dry_outer_electronics_pod_part

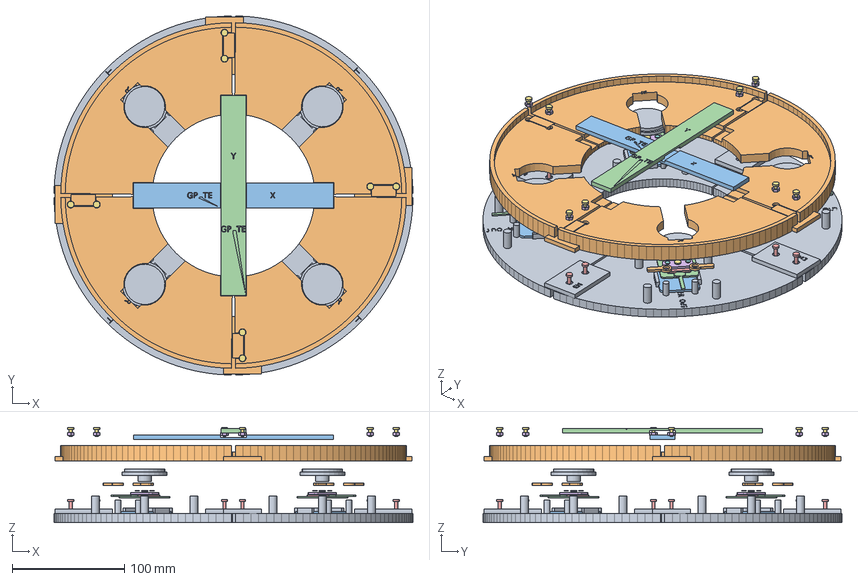
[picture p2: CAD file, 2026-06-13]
cad/exports/active/step/concept_v4_exploded_assembly.step
320.0 x 320.0 x 85.0 mm
lower_segment_0_part
upper_segment_0_raised_part
lower_segment_1_part
upper_segment_1_raised_part
lower_segment_2_part
upper_segment_2_raised_part
lower_segment_3_part
upper_segment_3_raised_part
sensor_0_lower_pad_part
sensor_0_kiwi_reference_v1_part
sensor_0_upper_pad_part
sensor_0_front_clip_top_open_open_raised_part
sensor_0_front_clip_bottom_open_open_raised_part
sensor_1_lower_pad_part
sensor_1_kiwi_reference_v1_part
sensor_1_upper_pad_part
sensor_1_front_clip_top_open_open_raised_part
sensor_1_front_clip_bottom_open_open_raised_part
sensor_2_lower_pad_part
sensor_2_kiwi_reference_v1_part
sensor_2_upper_pad_part
sensor_2_front_clip_top_open_open_raised_part
sensor_2_front_clip_bottom_open_open_raised_part
sensor_3_lower_pad_part
sensor_3_kiwi_reference_v1_part
sensor_3_upper_pad_part
sensor_3_front_clip_top_open_open_raised_part
sensor_3_front_clip_bottom_open_open_raised_part
support_grate_bar_x_raised_part
support_grate_bar_y_raised_part
lower_m3_button_bolt_0_0_raised_part
lower_captured_m3_nut_0_0_raised_part
lower_m3_button_bolt_0_1_raised_part
lower_captured_m3_nut_0_1_raised_part
lower_m3_button_bolt_1_0_raised_part
lower_captured_m3_nut_1_0_raised_part
lower_m3_button_bolt_1_1_raised_part
lower_captured_m3_nut_1_1_raised_part
lower_m3_button_bolt_2_0_raised_part
lower_captured_m3_nut_2_0_raised_part
lower_m3_button_bolt_2_1_raised_part
lower_captured_m3_nut_2_1_raised_part
lower_m3_button_bolt_3_0_raised_part
lower_captured_m3_nut_3_0_raised_part
lower_m3_button_bolt_3_1_raised_part
lower_captured_m3_nut_3_1_raised_part
upper_m3_button_bolt_0_0_raised_part
upper_captured_m3_nut_0_0_raised_part
upper_m3_button_bolt_0_1_raised_part
upper_captured_m3_nut_0_1_raised_part
upper_m3_button_bolt_1_0_raised_part
upper_captured_m3_nut_1_0_raised_part
upper_m3_button_bolt_1_1_raised_part
upper_captured_m3_nut_1_1_raised_part
upper_m3_button_bolt_2_0_raised_part
upper_captured_m3_nut_2_0_raised_part
upper_m3_button_bolt_2_1_raised_part
upper_captured_m3_nut_2_1_raised_part
upper_m3_button_bolt_3_0_raised_part
upper_captured_m3_nut_3_0_raised_part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

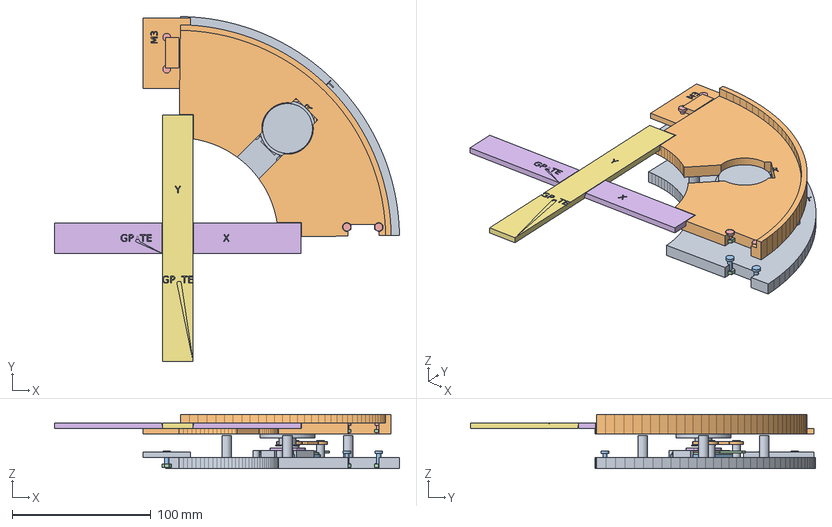
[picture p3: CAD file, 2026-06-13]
cad/exports/active/step/concept_v4_one_quadrant_assembly.step
249.0 x 249.0 x 39.0 mm
lower_segment_0_integrated_lugs_part
upper_segment_0_integrated_lugs_part
sensor_0_lower_pad_part
sensor_0_kiwi_reference_v1_part
sensor_0_upper_pad_part
sensor_0_front_clip_top_closed_part
sensor_0_front_clip_bottom_closed_part
lower_m3_button_bolt_0_0_part
lower_captured_m3_nut_0_0_part
lower_m3_button_bolt_0_1_part
lower_captured_m3_nut_0_1_part
lower_m3_button_bolt_3_0_part
lower_captured_m3_nut_3_0_part
lower_m3_button_bolt_3_1_part
lower_captured_m3_nut_3_1_part
upper_m3_button_bolt_0_0_part
upper_captured_m3_nut_0_0_part
upper_m3_button_bolt_0_1_part
upper_captured_m3_nut_0_1_part
upper_m3_button_bolt_3_0_part
upper_captured_m3_nut_3_0_part
upper_m3_button_bolt_3_1_part
upper_captured_m3_nut_3_1_part
support_grate_bar_x_part
support_grate_bar_y_part

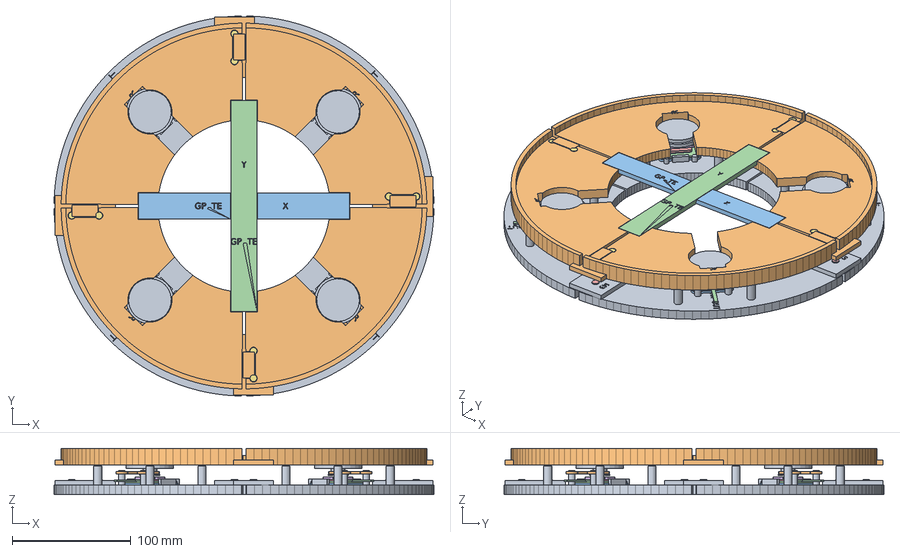
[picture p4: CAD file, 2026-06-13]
cad/exports/active/step/concept_v4_assembly.step
320.0 x 320.0 x 39.0 mm
lower_segment_0_part
lower_segment_1_part
lower_segment_2_part
lower_segment_3_part
upper_segment_0_part
upper_segment_1_part
upper_segment_2_part
upper_segment_3_part
sensor_0_lower_pad_part
sensor_0_kiwi_reference_v1_part
sensor_0_upper_pad_part
sensor_0_front_clip_top_closed_part
sensor_0_front_clip_bottom_closed_part
sensor_1_lower_pad_part
sensor_1_kiwi_reference_v1_part
sensor_1_upper_pad_part
sensor_1_front_clip_top_closed_part
sensor_1_front_clip_bottom_closed_part
sensor_2_lower_pad_part
sensor_2_kiwi_reference_v1_part
sensor_2_upper_pad_part
sensor_2_front_clip_top_closed_part
sensor_2_front_clip_bottom_closed_part
sensor_3_lower_pad_part
sensor_3_kiwi_reference_v1_part
sensor_3_upper_pad_part
sensor_3_front_clip_top_closed_part
sensor_3_front_clip_bottom_closed_part
support_grate_bar_x_part
support_grate_bar_y_part
lower_m3_button_bolt_0_0_part
lower_captured_m3_nut_0_0_part
lower_m3_button_bolt_0_1_part
lower_captured_m3_nut_0_1_part
lower_m3_button_bolt_1_0_part
lower_captured_m3_nut_1_0_part
lower_m3_button_bolt_1_1_part
lower_captured_m3_nut_1_1_part
lower_m3_button_bolt_2_0_part
lower_captured_m3_nut_2_0_part
lower_m3_button_bolt_2_1_part
lower_captured_m3_nut_2_1_part
lower_m3_button_bolt_3_0_part
lower_captured_m3_nut_3_0_part
lower_m3_button_bolt_3_1_part
lower_captured_m3_nut_3_1_part
upper_m3_button_bolt_0_0_part
upper_captured_m3_nut_0_0_part
upper_m3_button_bolt_0_1_part
upper_captured_m3_nut_0_1_part
upper_m3_button_bolt_1_0_part
upper_captured_m3_nut_1_0_part
upper_m3_button_bolt_1_1_part
upper_captured_m3_nut_1_1_part
upper_m3_button_bolt_2_0_part
upper_captured_m3_nut_2_0_part
upper_m3_button_bolt_2_1_part
upper_captured_m3_nut_2_1_part
upper_m3_button_bolt_3_0_part
upper_captured_m3_nut_3_0_part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

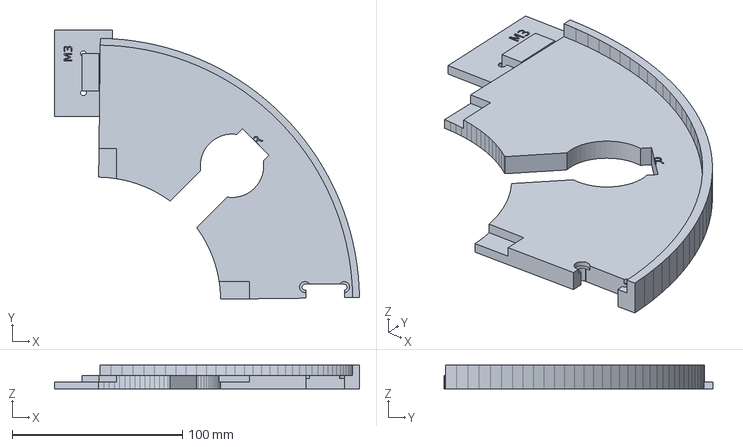
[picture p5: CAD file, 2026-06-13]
cad/exports/active/step/concept_v4_upper_segment_0.step
179.0 x 158.1 x 14.0 mm

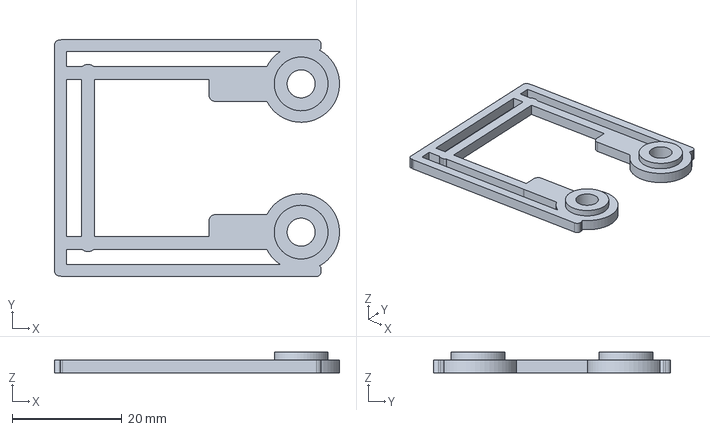
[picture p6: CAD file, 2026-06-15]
cad/exports/concept_v5_cartridge/step/concept_v5_sensor_retainer_clip.step
51.9 x 43.2 x 3.80 mm

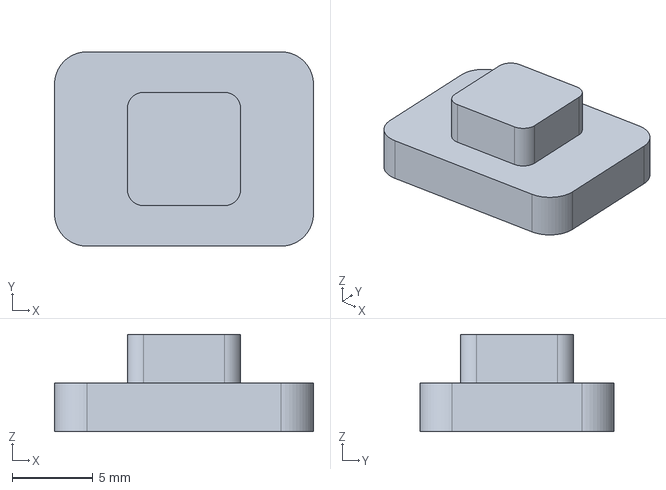
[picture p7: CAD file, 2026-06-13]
cad/exports/rejected/step/concept_v4_upper_pad_retainer_rejected.step
16.0 x 12.0 x 6.00 mm

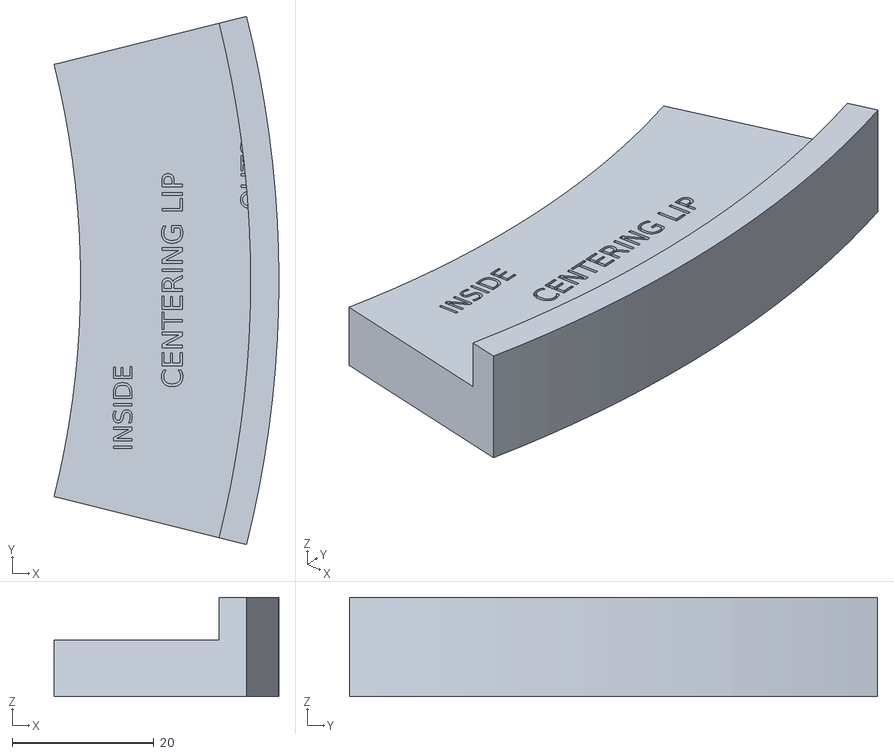
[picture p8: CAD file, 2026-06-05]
cad/exports/validation/stl/centering_lip_coupon_v1.stl
31.7 x 74.5 x 14.0

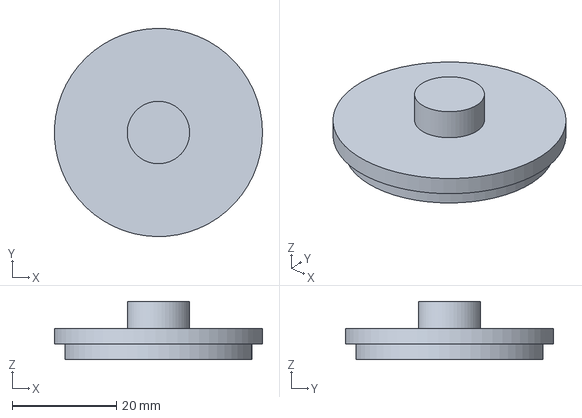
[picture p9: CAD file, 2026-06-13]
cad/exports/active/step/concept_v4_upper_pad.step
40.0 x 40.0 x 11.2 mm

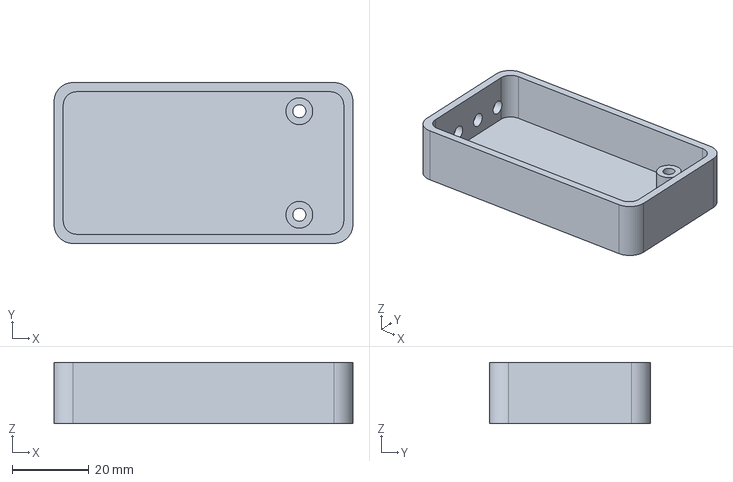
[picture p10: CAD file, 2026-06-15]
cad/exports/concept_v5_cartridge/step/concept_v5_electronics_pod.step
78.0 x 42.0 x 16.0 mm

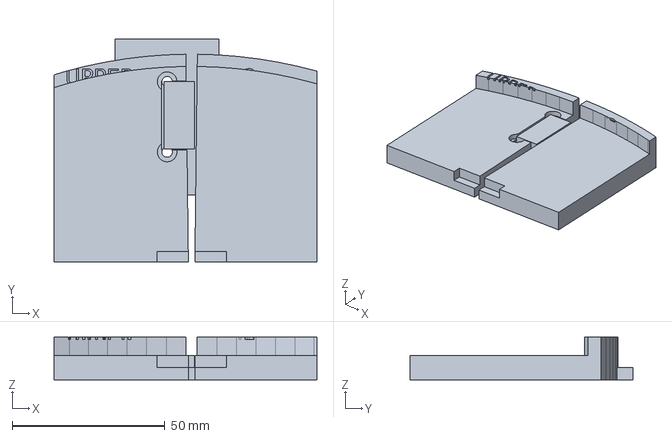
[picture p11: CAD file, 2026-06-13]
cad/exports/experimental/step/concept_v4_upper_integrated_seam_coupon_v1.step
86.0 x 73.0 x 14.0 mm

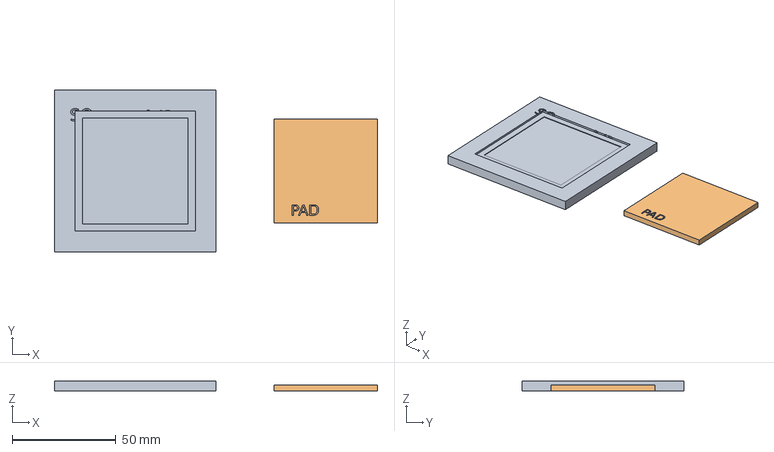
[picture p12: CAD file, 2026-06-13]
cad/exports/rejected/step/concept_v4_upper_pad_pocket_chamfer_square_v1.step
156.0 x 78.0 x 5.00 mm

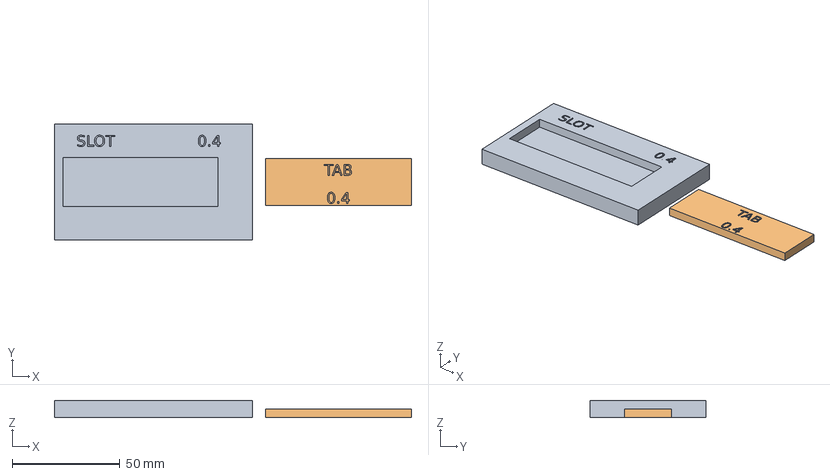
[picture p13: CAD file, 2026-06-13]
cad/exports/validated/step/support_grate_fit_0p4mm_per_side.step
166.0 x 54.0 x 8.00 mm

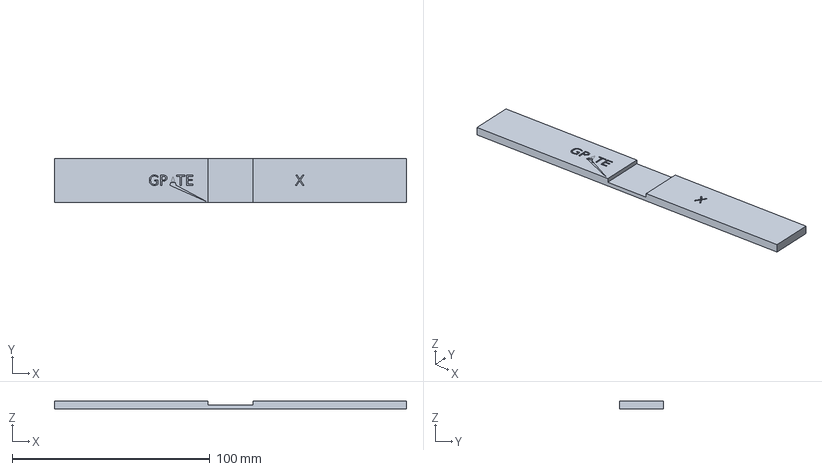
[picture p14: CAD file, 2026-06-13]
cad/exports/active/step/concept_v4_support_grate_bar_x.step
178.0 x 22.0 x 4.00 mm

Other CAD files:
cad/exports/experimental/step/concept_v4_locator_fit_0p4_v1.step
cad/exports/rejected/step/support_grate_fit_0p8mm_per_side.step
cad/exports/concept_v5_cartridge/step/concept_v5_round_load_puck.step
cad/exports/experimental/step/concept_v4_lower_support_test_v1.step
cad/exports/active/step/concept_v4_kiwi_sensor_reference_v1.step
cad/exports/active/step/concept_v4_lower_pad.step
cad/exports/active/step/concept_v4_lower_segment_0.step
cad/exports/active/step/concept_v4_sensor_placeholder.step
cad/exports/active/step/concept_v4_sensor_quarter_turn_clip.step
cad/exports/active/step/concept_v4_support_grate_bar_y.step
cad/exports/active/stl/concept_v4_kiwi_sensor_reference_v1.stl
cad/exports/active/stl/concept_v4_lower_pad.stl
cad/exports/active/stl/concept_v4_lower_segment_0.stl
cad/exports/active/stl/concept_v4_sensor_placeholder.stl
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

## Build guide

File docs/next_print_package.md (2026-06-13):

# Next Print Package

Date: 2026-06-08

## Summary

The current repository is clean enough to print from, but the next print should not be a full `concept_v4` segment yet.

The highest-value pre-Kiwi print package is the small `concept_v4` integrated seam validation set. It tests the riskiest current production assumption: whether the integrated M3 lug, captured nut, button-head recess, and printed locator can be assembled repeatedly in PETG without damage or awkwardness.

Do not print rejected, archived, or superseded concepts.

## Current Export Inventory

The current export tree is organized as:

- `cad/exports/active/`: current `concept_v4` printable parts and assembly STEP files.
- `cad/exports/validated/`: prints that validated accepted decisions.
- `cad/exports/experimental/`: useful experiments, including the current `concept_v4` seam validation coupons.
- `cad/exports/rejected/`: rejected alternatives kept for traceability.
- `cad/exports/archive/`: historical platform, concept, and obsolete coupon exports.

Relevant current active printable STLs:

- `cad/exports/active/stl/concept_v4_lower_segment_0.stl`
- `cad/exports/active/stl/concept_v4_upper_segment_0.stl`
- `cad/exports/active/stl/concept_v4_support_grate_bar_x.stl`
- `cad/exports/active/stl/concept_v4_support_grate_bar_y.stl`
- `cad/exports/active/stl/concept_v4_lower_pad.stl`
- `cad/exports/active/stl/concept_v4_upper_pad.stl`
- `cad/exports/active/stl/concept_v4_sensor_placeholder.stl`

Relevant current validation or experiment STLs:

- `cad/exports/experimental/stl/concept_v4_upper_lug_recess_block_v1.stl`
- `cad/exports/experimental/stl/concept_v4_upper_lug_mating_block_v1.stl`
- `cad/exports/experimental/stl/concept_v4_lower_lug_bolt_block_v1.stl`
- `cad/exports/experimental/stl/concept_v4_lower_lug_nut_block_v1.stl`
- `cad/exports/experimental/stl/concept_v4_locator_fit_0p3_v1.stl`
- `cad/exports/experimental/stl/concept_v4_locator_fit_0p4_v1.stl`
- `cad/exports/experimental/stl/concept_v4_locator_fit_0p5_v1.stl`
- `cad/exports/experimental/stl/concept_v4_integrated_mini_seam_test_v1.stl`
- `cad/exports/experimental/stl/concept_v4_upper_integrated_seam_coupon_v1.stl`
- `cad/exports/experimental/stl/concept_v4_lower_integrated_seam_coupon_v1.stl`
- `cad/exports/validated/stl/concept_v4_upper_pad_pocket_round_cup_v1.stl`
- `cad/exports/validated/stl/support_grate_fit_0p4mm_per_side.stl`
- `cad/exports/validated/stl/test_m3_captured_nut_v1.stl`
- `cad/exports/validated/stl/label_readability_coupon_v1.stl`
- `cad/exports/validated/stl/sensor_station_locator_v3.stl`

Rejected and archived STLs are not part of the next print package.

## Print Now

### `cad/exports/experimental/stl/concept_v4_upper_lug_recess_block_v1.stl`

Purpose: tests the upper seam M3 button-head recess in the integrated lug.

Estimated value: very high. This validates whether the top-access upper seam fastener strategy is physically realistic before printing a full upper segment.

Relevance: current and important.

### `cad/exports/experimental/stl/concept_v4_upper_lug_mating_block_v1.stl`

Purpose: mates with the upper lug recess block and tests the captured nut side of the upper seam.

Estimated value: very high. It confirms the nut pocket and bolt path work as a pair.

Relevance: current and important.

### `cad/exports/experimental/stl/concept_v4_lower_lug_bolt_block_v1.stl`

Purpose: tests the lower seam bolt-head side.

Estimated value: high. Lower seams are less risky than upper seams, but the integrated lug still needs physical checking.

Relevance: current.

### `cad/exports/experimental/stl/concept_v4_lower_lug_nut_block_v1.stl`

Purpose: tests the lower seam captured nut side.

Estimated value: high. Confirms the lower fastener stack still works in the new integrated geometry.

Relevance: current.

### `cad/exports/experimental/stl/concept_v4_locator_fit_0p3_v1.stl`

Purpose: validated printed tongue/socket seam locator clearance.

Estimated value: already validated. `0.3 mm per side` remained easy to assemble and gave the best alignment.

Relevance: current validated locator direction. Use this as the reference result; no tighter variant is currently required.

### `cad/exports/experimental/stl/concept_v4_locator_fit_0p4_v1.stl`

Purpose: comparison locator clearance.

Estimated value: completed. It showed unnecessary play compared with `0.3 mm`.

Relevance: superseded comparison result; do not print again unless diagnosing printer variation.

### `cad/exports/experimental/stl/concept_v4_locator_fit_0p5_v1.stl`

Purpose: comparison locator clearance.

Estimated value: completed. It showed unnecessary play compared with `0.3 mm`.

Relevance: superseded comparison result; do not print again unless diagnosing printer variation.

### `cad/exports/experimental/stl/concept_v4_integrated_mini_seam_test_v1.stl`

Purpose: tests one minimal integrated seam with one M3 fastener stack, one captured nut, one locator, and one reinforced lug root.

Estimated value: very high. This is the closest small print to a real v4 seam assembly.

Relevance: current and important.

### `cad/exports/active/stl/concept_v4_upper_pad.stl`

Purpose: prints the current active removable round upper pressure pad.

Estimated value: medium. It is small and useful for checking surface quality and fit against the already validated Round Cup coupon or a future upper segment.

Relevance: current active part.

## Print Later

### `cad/exports/experimental/stl/concept_v4_upper_integrated_seam_coupon_v1.stl`

Purpose: larger cropped real upper integrated seam coupon.

Estimated value: medium/high after micro coupons pass.

Relevance: current but not first. The micro coupons are the better next print because they are smaller and easier to interpret.

### `cad/exports/experimental/stl/concept_v4_lower_integrated_seam_coupon_v1.stl`

Purpose: larger cropped real lower integrated seam coupon.

Estimated value: medium/high after micro coupons pass.

Relevance: current but not first.

### `cad/exports/active/stl/concept_v4_upper_segment_0.stl`

Purpose: first real active upper quadrant segment.

Estimated value: high after seam micro coupons pass.

Relevance: current active part, but too large for the first post-baseline print.

### `cad/exports/active/stl/concept_v4_support_grate_bar_x.stl`

Purpose: one active removable support grate bar.

Estimated value: medium after upper segment printing starts.

Relevance: current active part.

### `cad/exports/active/stl/concept_v4_support_grate_bar_y.stl`

Purpose: the other active removable support grate bar.

Estimated value: medium after upper segment printing starts.

Relevance: current active part.

### `cad/exports/validated/stl/concept_v4_upper_pad_pocket_round_cup_v1.stl`

Purpose: validates the accepted Round Cup locator concept.

Estimated value: low if already physically accepted, medium if a new printer/material profile needs confirmation.

Relevance: validated reference, not active production geometry.

### `cad/exports/validated/stl/support_grate_fit_0p4mm_per_side.stl`

Purpose: validates the accepted `0.4 mm per side` support grate tab/slot clearance.

Estimated value: low if already printed and accepted.

Relevance: validated reference.

### `cad/exports/validated/stl/label_readability_coupon_v1.stl`

Purpose: validates label readability.

Estimated value: low because the label standard is already accepted.

Relevance: validated reference only.

### `cad/exports/validated/stl/test_m3_captured_nut_v1.stl`

Purpose: validates the captured M3 nut pocket.

Estimated value: low because the pocket is already accepted.

Relevance: validated reference only.

## Wait For Kiwi Hardware

### `cad/exports/active/stl/concept_v4_lower_segment_0.stl`

Purpose: active lower quadrant segment with sensor station and locator features.

Estimated value: high, but only after seam validation and real sensor arrival.

Relevance: current active part. Wait because the lower segment is large and the riskiest part of it is the real sensor fit.

### `cad/exports/active/stl/concept_v4_lower_pad.stl`

Purpose: active lower contact pad.

Estimated value: medium once real sensor contact geometry is known.

Relevance: current active part. Wait for real sensor fit and contact evaluation.

### `cad/exports/active/stl/concept_v4_sensor_placeholder.stl`

Purpose: visual/mechanical dummy for assembly planning.

Estimated value: low once real Kiwi hardware is on the way.

Relevance: active visualization helper, not a substitute for the real sensor.

### `cad/exports/validated/stl/sensor_station_locator_v3.stl`

Purpose: sensor locator validation coupon.

Estimated value: high with the real Kiwi/SparkFun sensor, lower without it.

Relevance: validated direction, but real sensor fit remains unvalidated.

### `cad/exports/validated/stl/test_sensor_locator_v3_fit_v1.stl`

Purpose: practical sensor locator fit test.

Estimated value: high with the real sensor, lower before hardware.

Relevance: validated direction, but best saved for real sensor arrival.

## Not Recommended

Do not print these for the current next session:

- Anything in `cad/exports/rejected/`.
- Anything in `cad/exports/archive/`.
- Printed-only wedge, dovetail, or sliding-key joinery coupons unless explicitly revisiting experimental no-metal joining.
- Old bolted bridge-plate seam coupons unless comparing against the rejected bridge-plate strategy.
- Full active upper or lower segments before the v4 integrated seam micro coupons pass.

## Integrated Seam Validation Status

Concept v4 integrated seam validation still exists.

Current small replacements:

- `cad/exports/experimental/stl/concept_v4_upper_lug_recess_block_v1.stl`
- `cad/exports/experimental/stl/concept_v4_upper_lug_mating_block_v1.stl`
- `cad/exports/experimental/stl/concept_v4_lower_lug_bolt_block_v1.stl`
- `cad/exports/experimental/stl/concept_v4_lower_lug_nut_block_v1.stl`
- `cad/exports/experimental/stl/concept_v4_locator_fit_0p3_v1.stl`
- `cad/exports/experimental/stl/concept_v4_locator_fit_0p4_v1.stl`
- `cad/exports/experimental/stl/concept_v4_locator_fit_0p5_v1.stl`
- `cad/exports/experimental/stl/concept_v4_integrated_mini_seam_test_v1.stl`

Larger cropped seam coupons also exist:

- `cad/exports/experimental/stl/concept_v4_upper_integrated_seam_coupon_v1.stl`
- `cad/exports/experimental/stl/concept_v4_lower_integrated_seam_coupon_v1.stl`

The small micro coupons should be treated as the current replacement test for first physical validation. The larger seam coupons remain useful later if the micro coupons pass.

## One Print Plate For Tonight

If printing one plate tonight, use this set:

```text
cad/exports/experimental/stl/concept_v4_upper_lug_recess_block_v1.stl
cad/exports/experimental/stl/concept_v4_upper_lug_mating_block_v1.stl
cad/exports/experimental/stl/concept_v4_lower_lug_bolt_block_v1.stl
cad/exports/experimental/stl/concept_v4_lower_lug_nut_block_v1.stl
cad/exports/experimental/stl/concept_v4_locator_fit_0p3_v1.stl
cad/exports/experimental/stl/concept_v4_integrated_mini_seam_test_v1.stl
cad/exports/active/stl/concept_v4_upper_pad.stl
```

Why this plate:

- It tests the integrated seam without printing a full segment.
- It checks both upper and lower M3 fastener stacks.
- It uses the now-validated `0.3 mm per side` seam locator clearance.
- It tests the mini real seam interaction between locator and fastener.
- It adds the active upper pad because it is small and useful.

Required hardware:

- M3 button-head screws matching the v4 assumption.
- Standard M3 hex nuts.
- Small screwdriver.
- Optional calipers for measuring fit and wear.

## What To Record

For each printed seam part:

- Does the nut press in lightly?
- Does the nut rotate during tightening?
- Does the nut fall out during handling?
- Does the M3 screw pass cleanly?
- Does the button head seat flush or below the intended surface?
- Does the locator assemble by hand?
- Does the validated `0.3 mm per side` locator still feel controlled in the integrated mini seam?
- Does the integrated mini seam clamp without rocking?
- Does the seam survive five assemble/disassemble cycles?
- Are labels readable enough to help assembly?

## Biggest Remaining Risk

The biggest pre-Kiwi risk is the integrated v4 seam.

Reason:

- It is new in concept v4.
- It replaces the earlier bridge-plate approach.
- It affects every upper and lower segment seam.
- If it is hard to assemble, weak, or poorly aligned, full segment prints would waste much more filament.

The biggest post-Kiwi risk is real sensor fit and load contact behavior in the sensor station.

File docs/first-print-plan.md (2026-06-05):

# First Print Plan — SaltScale v6 (PETG)

This short plan recommends the minimum prints and checks before committing to full-platform prints. It assumes PETG on a Prusa MK4 (200×200×200 build volume).

1) Which part to print first
- Print one complete `platform_v6_segment_0` (one quarter segment) including its integrated `sensor_module_v3` pocket. Also print a spare `sensor_module_v3_sensor_placeholder.stl`, `sensor_module_v3_upper_pad.stl`, and `sensor_module_v3_lower_pad.stl` separately for fit tests.

2) Expected print time (approximate)
- `sensor_module_v3` small parts (placeholder, upper/lower pads): 1–3 hours combined.
- One full segment (`platform_v6_segment_0`): 6–12 hours depending on layer height and infill.
- Full 4-segment platform (for planning): ~24–48 hours total (sum of segments).

3) Expected PETG usage (approximate)
- `sensor_module_v3` small parts: 15–40 g.
- One full segment: 80–160 g.
- Full platform (4 segments): 320–640 g.

4) Recommended orientation
- Segment: flat on the build plate with the lower plate face down (native orientation in CAD). This keeps the sensor pocket vertical and preserves dimensional accuracy for dowel holes and blind pockets.
- Sensor placeholder / pads: print upright (flat faces horizontal) so mating faces are printed smooth and dimensional.

5) Expected support requirements
- Segment: minimal global supports if printed flat; small supports may be needed for top-plate boss underside if geometry creates overhangs. Use sparse, breakaway supports for pocket interiors if your slicer requires them.
- Sensor upper pad and lower pad: normally support-free when printed flat.

6) Most likely print failures
- Warping/edge lift on large thin plates (PETG benefits from an enclosure and brim).
- Pocket bridging sag or poor surface finish inside the sensor pocket (affects fit).
- Undersized/oversized dowel holes and blind pocket tolerances causing tight/loose fits.

7) Most likely assembly failures
- Dowel mismatch (holes too tight or too loose) — dowel boss failure under press-fit.
- M3 screw length/clearance mistakes — screws bottoming out or head colliding with features.
- Upper pad binding or being too loose in the pocket (affects load transmission and repeatability).

8) What to physically test before printing the full platform
- Print a small test coupon set: `sensor_module_v3_sensor_placeholder.stl`, `sensor_module_v3_lower_pad.stl`, `sensor_module_v3_upper_pad.stl`, and one cropped section of the segment that includes a dowel boss and blind M3 pocket (a ~60×60×10 mm test block).
- Check clearances: sensor pocket fit, dowel hole fit with chosen dowel, M3 screw length and fit in blind pocket, and upper_pad seating/removal force.
- Print orientation test: try one segment with and without brim/enclosure to confirm no warping.

Practical slicer settings (starting point for PETG)
- Nozzle temp: 240–250 °C. Bed: 80–90 °C. Enclosure recommended when available.
- Layer height: 0.2–0.28 mm for segments (0.2 mm for sensor-fit parts if tighter tolerances needed).
- Infill: 20–30% for segments; 50–100% (or solid) for small pads if desired.
- Perimeter walls: 3–4 perimeters for strength near dowel bosses and pocket walls.
- Brim: 8–12 mm for segments to mitigate warping.

Final note
- Start conservative: validate one populated segment and test coupons, adjust clearances and fastener lengths, then print remaining segments. This minimizes wasted PETG and time while ensuring fit and assembly reliability.

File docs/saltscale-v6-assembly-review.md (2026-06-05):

# SaltScale v6 — Assembly Review

This document describes how all parts of SaltScale v6 fit together, the exploded arrangement, a cross-section through one sensor module, the recommended assembly order, and notes on trapped parts or impossible sequences.

See the exploded/annotated diagram: [docs/saltscale-v6-exploded-assembly.svg](docs/saltscale-v6-exploded-assembly.svg)

Parts (names map to CAD/exports):
- `platform_v6_segment_0..3` — four printable quarter segments (each contains lower plate geometry and one `sensor_module_v3` assembly).
- `sensor_module_v3` (module parts inside each segment):
  - `module_base` — module base pocket integrated into the segment lower plate.
  - `lower_pad` — lower reaction pad (z = 6..8 mm).
  - `sensor_placeholder` — sensor body placeholder (z = 8..20 mm).
  - `upper_pad` — removable upper contact pad (z = 20..24 mm).
  - `module_stops` — distinct cylindrical overload stops (top at z = 19 mm).
- Joining/locating hardware (not modelled as separate parts):
  - metal dowel pins (4 mm recommended; holes are 4.2 mm clearance in CAD)
  - M3 screws into blind pockets near rim

Exploded view (summary)
- The platform is assembled from the four quarter segments. Each segment already contains a complete `sensor_module_v3` assembly placed at its quadrant center (45°, 135°, 225°, 315°).
- When exploded, the sequence shows (top → bottom): upper platform/top plate (per segment), `upper_pad` (module), `sensor_placeholder` (or real sensor), `lower_pad`, module base integrated into the segment lower plate, and finally the assembled full platform skirt/perimeter when all segments are joined.

Cross-section through one sensor module (Z heights, all mm, top-of-base = z 6.0):
- Upper plate boss / upper platform: contacts `upper_pad` at z = 20..24.
- `upper_pad`: 20..24 mm — transmits load to the sensor.
- `sensor_placeholder` (sensor): 8..20 mm — sensing element flexes in this range.
- `lower_pad`: 6..8 mm — reaction pad that transfers load into the segment lower plate.
- Segment lower plate / ribs: z = 0..6 mm — carries load outward to perimeter.
- Module stops top at z = 19.0 mm — provide 1 mm clearance to `upper_pad` underside (protective limit).

Assembly order (recommended, by step):
1. Place one segment flat on the work surface (segment 0). The `sensor_module_v3` parts intended to be removable are already modelled as separate bodies in the segment; ensure `lower_pad` and module base are present in the segment.
2. Insert the real sensor (or `sensor_placeholder` test part) into the pocket from above so it seats on the `lower_pad` (sensor should be removable upward).
3. Place the `upper_pad` onto the sensor from above (upper pad sits into the pocket and is removable). Do not compress beyond the 1 mm gap to the module stops.
4. Repeat steps 1–3 for the other three segments.
5. Bring two adjacent segments together and insert alignment dowels through matching holes near the rim.
6. Fit the remaining segments using dowels to align all seams.
7. Install M3 screws into the blind pockets near the rim to secure the seam (screw depth is limited to lower plate area — they do not create top→bottom though-holes consistent with v6 design).
8. Optionally install metal dowels permanently (press-fit) or add caps over M3 screws.

Per-part details

- `Upper platform / top plate` (per segment top wedge)
  - What it does: provides the user-facing surface and top bosses that contact module upper pads.
  - What it touches: `upper_pad` when assembled; ribs and top plate material elsewhere.
  - Carries load? Yes — during normal operation load transfers from top plate boss → upper_pad → sensor.
  - Alignment only? No.

- `Upper_pad` (module part)
  - What it does: distributes contact pressure into the sensor and provides defined contact geometry.
  - What it touches: top plate boss (above) and sensor placeholder (below); may contact module stops under overload.
  - Carries load? Yes (primary vertical load path when within travel range).
  - Alignment only? No, but it is removable for service.

- `Sensor_placeholder` / sensor (module part)
  - What it does: the sensing element inside the module; flexes under load to produce readable strain.
  - What it touches: `upper_pad` (top) and `lower_pad` (bottom).
  - Carries load? Yes (primary sensing element).
  - Alignment only? No.

- `Lower_pad` (module part)
  - What it does: reaction surface that transmits sensor output into the segment lower plate.
  - What it touches: sensor bottom and segment lower plate.
  - Carries load? Yes.
  - Alignment only? No.

- `Module_base` (module base integrated into segment lower plate)
  - What it does: houses pocket, guide walls, and stops; provides lateral guidance and overload stop support.
  - What it touches: `lower_pad`, sensor (when installed), module stops (if engaged), surrounding ribs.
  - Carries load? Yes (receives load from lower_pad and spreads to lower plate).
  - Alignment only? Partly: guide walls help locate the sensor, but module base also carries load.

- `Dowel pins` (hardware, not modelled)
  - What they do: provide accurate alignment between segments under assembly and load.
  - What they touch: reinforced dowel bosses in each segment.
  - Carry load? Primarily alignment; if sized/pressed they may carry some shear between segments but not intended to be primary vertical load path.
  - Alignment only? Primarily yes.

- `M3 screws` (into blind pockets)
  - What they do: clamp segments together and hold seams closed.
  - What they touch: lower-plate blind pockets and local boss material; do not pass into top plate region.
  - Carry load? They clamp; not part of sensor load path and intentionally do not form a top→bottom stiffener across sensor zones.
  - Alignment only? No — they secure the seam.

Assembly sequencing hazards
- Impossible or trapped components:
  - No trapped `upper_pad`/`sensor_placeholder` parts: sensors and pads are designed to be removable from above before segments are joined; therefore no part is trapped if assembled in recommended order.
  - If segments are joined before sensors/upper pads are installed, you will not be able to insert sensors from above into a fully assembled platform — therefore sensors must be installed into each segment prior to final seam joining.

- Parts that cannot be installed after another part:
  - Sensors and `upper_pad` must be installed into their segment pockets before adjoining that segment to neighbors; installing them after full assembly may be impossible without disassembly.

Checks to perform before final assembly
- Print and validate one segment with `sensor_module_v3` placeholder to check pocket clearance and dowel fit.
- Verify dowel diameter and fit (4.2 mm hole; choose dowel size accordingly, e.g., 4.0 mm dowel).
- Verify M3 screw length and head clearance so screws do not bottom out or deform the lower plate excessively.

Conclusion
- The v6 design supports a clear, serviceable assembly sequence: build and populate each segment individually (sensor + upper_pad), then join segments with dowels and blind M3 screws. No trapped parts if the recommended order is followed. Sensor force paths remain preserved and protected by module stops and platform-level overload pads.

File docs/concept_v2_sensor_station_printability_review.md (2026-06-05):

# Concept v2 Sensor Station Printability Review

Date: 2026-06-05

## Summary

PrusaSlicer reported unsupported bridge lines at the bottom of the `concept_v2_sensor_station` guide walls.

The guide walls were not fully floating bodies, but the model did create small unsupported wall-bottom spans. The cause was a shallow lower-pad locator cut applied after the guide walls were unioned into the base. That cut removed the top 1 mm of base material under parts of the guide-wall footprints.

Fix applied:

- Moved guide rails and the inner stop outward so they sit outside the lower-pad footprint.
- Removed the lower-pad locator cut from both `sensor_station_coupon()` and `lower_segment()`.
- Kept the lower contact pad on solid base material.
- Re-exported `cad/exports/stl/concept_v2_sensor_station.stl`.

## Investigation

Relevant CAD source:

- `cad/src/concept_v2.py`
- `_sensor_station_lower_features()`
- `lower_segment()`
- `sensor_station_coupon()`

Original geometry sequence:

1. Create base plate.
2. Union guide rails, inner stop, and overload stops at `z = lower_thickness_mm`.
3. Cut a shallow lower-pad locator pocket from `z = 7..8 mm`.

The guide walls also began at `z = 8 mm`, exactly at the top of the base plate. That is correct only if the base is still solid underneath the wall footprint.

## What created the unsupported spans

The shallow locator cut was larger than the clear area inside the guide walls.

Before the fix:

- Lower-pad locator cut size: `45.2 x 45.2 x 1.0 mm`.
- Locator half-width: `22.6 mm`.
- Guide rail inner faces were inside that envelope.
- The cut was applied after guide-wall union.

Result:

- The guide walls still started at `z = 8 mm`.
- But part of the base directly under the first guide-wall layer had been cut down to `z = 7 mm`.
- PrusaSlicer saw the first wall layer crossing over a shallow void and marked bridge lines.

This was a slicer artifact caused by real CAD geometry, not a PrusaSlicer false positive.

## Were guide walls floating?

Not as whole bodies.

The walls were unioned into the station body and nominally started at the base top. However, because the later pocket cut removed support below part of the footprint, some bottom wall lines became locally unsupported.

After the fix:

- Guide walls still start at the top of the base plate.
- No locator cut removes material under them.
- They sit on continuous solid printed geometry.

## Did a pocket cut remove support below the walls?

Yes.

The lower-pad locator pocket cut was the direct cause. It overlapped the wall footprints because it was sized around the larger lower contact pad, while the guide-wall spacing had originally been based on the smaller sensor placeholder.

A second issue came from the same cut: the lower contact pad was modeled at the top of the base while the locator pocket removed material below it. That meant the pad was not clearly supported by solid base material in the assembly model.

After the fix:

- The locator cut is no longer applied.
- The lower contact pad rests on solid base material.
- Guide walls provide lateral location without cutting a recess below the pad.

## Were bodies not fully unioned?

No.

The guide walls were unioned into the station body. The issue was not missing boolean union. The issue was boolean order and footprint overlap:

```text
base + guide walls -> cut locator pocket
```

The cut happened after the walls existed, so it could remove material under the wall bottoms.

## CAD fix

Changes in `cad/src/concept_v2.py`:

- Replaced the old guide-wall spacing based on sensor span with spacing based on the lower-pad locator envelope.
- Added an explicit `0.8 mm` clearance beyond the former locator footprint.
- Moved the inner radial stop outward by the same rule.
- Moved overload stops outward so they remain distinct and do not merge into the guide rails.
- Removed the lower-pad locator cut in `lower_segment()`.
- Removed the lower-pad locator cut in `sensor_station_coupon()`.

Current geometry check:

- Former locator half-width: `22.6 mm`.
- Guide rail inner face: `23.4 mm` from station center.
- Inner stop outer face: `23.4 mm` from station center on the inward side.
- Clearance beyond former pocket footprint: `0.8 mm`.

Because the locator cut is no longer applied, this clearance is conservative rather than merely exact.

## Serviceability impact

Serviceability is preserved.

The sensor station remains:

- Open on the outer side.
- Accessible after removing the upper carrier.
- Free of upper-to-lower fasteners.
- Free of a printed sensor cap.

The lower contact pad is no longer recessed, but it remains removable. Lateral location is provided by the surrounding guide geometry instead of a shallow pocket.

## Force path impact

The force path is improved.

Before:

```text
lower contact pad -> partly over shallow locator recess -> base
```

After:

```text
lower contact pad -> solid base top -> lower base
```

The normal load path remains:

```text
upper carrier -> upper pad -> sensor -> lower pad -> lower base
```

No upper-to-lower bypass was introduced.

## Export and build status

Updated export:

- `cad/exports/stl/concept_v2_sensor_station.stl`

Build/checks run:

- `python -m py_compile cad/src/concept_v2.py`
- Targeted CadQuery export for `concept_v2_sensor_station.stl`
- `python cad/build.py`

The existing `cad/build.py` completed successfully. It does not currently export `concept_v2`; the updated v2 sensor station STL was exported separately from `concept_v2.py`.

## Recommendation

Re-slice the updated `concept_v2_sensor_station.stl` in PrusaSlicer.

Expected result:

- No unsupported bridge lines at the bottom of the guide walls.
- Guide walls should start on solid base geometry.
- Lower contact pad should be treated as sitting on solid support in the physical prototype.

If PrusaSlicer still reports bridging, inspect for slicer settings around thin walls/perimeters rather than the old locator-pocket issue.

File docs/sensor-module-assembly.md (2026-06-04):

# Sensor Module v2 — Assembly & Force Path

This document explains the parts produced by `sensor_module_v2` and exactly where loads travel and where constraints occur.

Generated files
- `cad/exports/stl/sensor_module_base.stl` — base fixture (pocketed plate and guide walls, with overload stops).
- `cad/exports/stl/sensor_module_lower_pad.stl` — lower reaction pad (solid boss the sensor sits on).
- `cad/exports/stl/sensor_module_upper_pad.stl` — removable upper contact pad that presses on the sensor.
- `cad/exports/stl/sensor_module_sensor_placeholder.stl` — sensor placeholder body (38×38×12) for fit checks.
- `cad/exports/step/sensor_module_v2_assembly.step` — full assembly compound (base + lower pad + sensor placeholder + upper pad).

Exact locations and roles

- Where force enters:
  - The user/applied load presses onto the `upper_pad` (the top face of `sensor_module_upper_pad.stl`). This is the primary external contact.

- Where force leaves (reaction path):
  - The load transmits through the `upper_pad` into the sensor placeholder (or real sensor) and then into the `lower_pad` (the solid boss exported as `sensor_module_lower_pad.stl`). From the lower pad the load is carried into the `base` plate and into the test rig or fixture.

- Where lateral guidance occurs:
  - Lateral guidance is provided by the guide walls on the `base` (in `sensor_module_base.stl`). These surround the pocket and prevent lateral/shear motion of the sensor and upper pad relative to the base.
  - The sensor placeholder itself is dimensioned with a small clearance; guide walls and pocket faces react any sideways loads before they reach the sensing element.

- Where the overload stop engages:
  - Overload stops are short posts located around the pocket on the top of the `base`. When the `upper_pad` is pressed beyond the intended travel, these posts physically contact the underside of the `upper_pad` and limit further compression — protecting the sensor from excessive compression or mechanical damage.

Updated wall-height rule (v3)
- Guide walls in `sensor_module_v3` end at or below z = 19.0 mm (base top is z = 6.0 mm). This guarantees the guide walls cannot make vertical contact with the `upper_pad` (which has its underside at z = 20.0 mm) and therefore cannot bypass the sensor by carrying vertical load.

Exact overload stop behavior (v3)
- Overload stops are distinct cylindrical posts in `sensor_module_v3_base.stl` and reach up to z = 19.0 mm. They create a 1.0 mm clearance below the `upper_pad` underside (z = 20.0 mm). When the `upper_pad` is depressed more than 1.0 mm relative to the base, the pad contacts these stops and further compression is prevented.

Design notes
- The `lower_pad` is a purposefully separate body so you can print or machine a hardened pad (washer/metal plate) and assemble it into the base to reduce wear and improve repeatability.
- The `upper_pad` is removable so you can iterate on contact-face materials (PTFE, metal washer, printed pad) and try different clearances.
- The `sensor_placeholder` is provided so you can validate fit and verify that the pocket, guide walls, and boss align correctly before installing real sensors.

Recommended next steps
- Print `sensor_module_sensor_placeholder.stl` and `sensor_module_base.stl` with the planned wall/clearance settings to verify fit on your Prusa MK4.
- Try lower-pad variants (metal washer glued to `sensor_module_lower_pad`) to test wear and repeatability.

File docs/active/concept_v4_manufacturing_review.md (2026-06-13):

# Concept v4 Manufacturing Review

Date: 2026-06-07

## Scope

This is a manufacturability and assembly review of `concept_v4_integrated_joining`. It does not redesign the architecture and does not modify CAD.

Reviewed source/export context:

- `cad/src/concept_v4_integrated_joining.py`
- `docs/integrated-m3-joining-review.md`
- active concept v4 STEP/STL exports

Validated assumptions preserved:

- Four-sensor floating architecture.
- Upper ring and lower ring remain mechanically separate.
- M3 bolts and standard captured M3 nuts are acceptable.
- No heat-set inserts.
- No metal dowels.
- Support-grate clearance remains `0.4 mm per side`.
- Sensor locator v3 direction remains active.

## Executive Summary

The integrated M3 idea is promising. The first manufacturing review found three seam details that had to be fixed before treating `concept_v4` as a credible baseline: upper bolt-head clearance, non-fastener alignment, and PETG lug-root stress.

Those fixes have now been applied in CAD. The current `concept_v4` uses top-access recessed M3 button-head screws for the upper seams, underside captured nuts, same-layer printed tongue/socket locators separate from the M3 bolts, broader flat lug-root shoulders, and the accepted Round Cup upper-pad locator.

`concept_v4` still needs physical seam-coupon validation before a full platform print.

## Key CAD Facts

Current concept v4 dimensions from CAD:

| Feature | Value |
| --- | ---: |
| Lower segment envelope after seam refinement | about `185.0 x 159.1 x 21.0 mm` |
| Upper segment envelope after seam refinement | about `179.0 x 158.1 x 18.0 mm` |
| Lower segment base | `z = 0..8 mm` |
| Lower sensor/locator features | up to about `z = 21 mm` |
| Lower integrated lugs | `z = 8..12 mm` |
| Upper segment body | `z = 25..39 mm` |
| Upper integrated lugs | `z = 21..25 mm` |
| Integrated lug size | `24 x 30 x 4 mm` |
| Seam bolt radii | `122 mm`, `145 mm` |
| M3 clearance hole | `3.4 mm` |
| Captured nut pocket | `5.9 mm` across flats |
| Captured nut retaining lip | `5.35 mm` across flats |

## 2026-06-07 Fastener Rework

The prior underside-access upper fastener direction has been replaced. The current full `concept_v4` assembly STEP exports show:

- Lower seam: button-head screw above, shaft downward, captured nut below.
- Upper seam: button-head screw above in a top-side recess, shaft downward, captured nut below in the underside lug.
- Nut visuals include center holes so bolt shafts do not occupy the same volume as solid nut placeholders.

The upper button-head assumption remains:

- Head diameter: `5.7 mm`.
- Head height: `1.8 mm`.
- Counterbore diameter: `6.4 mm`.
- Counterbore depth: `2.0 mm`.

With this assumption, the upper button head occupies `z = 31.2..33.0 mm`, flush/recessed from the upper carrier top surface. The upper captured nut sits in the underside lug at about `z = 21.85..24.25 mm`. Boolean checks show the upper fastener visuals have `0.0 mm^3` overlap with the lower base/features and support grate bars.

## 2026-06-07 Upper Pad Locator Decision

The Round Cup carrier-relative upper-pad locator has been accepted and integrated into active `concept_v4`.

Removed from active CAD:

- Small underside locator tabs.
- Through-hole boss/socket upper pad locator.
- Sensor-relative upper pad locator.

Current active dimensions:

- Round upper pad diameter: `56.0 mm`.
- Cup clearance: `0.45 mm per side`.
- Upper pad height: `3.0 mm`.

Why this is simpler:

- One broad circular cup replaces several competing locator concepts.
- No through-hole is required in the upper carrier.
- No sensor-relative features depend on the exact Kiwi sensor body.
- The pad remains removable by hand.
- The pad lower face remains plain for sensor contact.
- No fastener, clip, or upper-to-lower feature is added.

Checks after integration:

- Upper segment vs round upper pad: `0.0 mm^3` overlap.
- Upper segment vs sensor placeholder: `0.0 mm^3` overlap.
- Full upper carrier vs full lower base: `0.0 mm^3` overlap.
- Support grate bars vs upper/lower: `0.0 mm^3` overlap.

Remaining validation need: physically print the active upper segment and upper pad to confirm the Round Cup fit is removable by hand and not too loose.

## Issues

### 1. Upper bolt heads may protrude below the floating upper carrier

Severity: **Critical**

Location:

- `cad/src/concept_v4_integrated_joining.py`
- `upper_segment()`
- `_lug_body(outgoing_seam, p.upper_z_mm - LUG_HEIGHT_MM, ...)`
- Upper integrated lugs at `z = 21..25 mm`

Finding:

The current upper seam logic implies bolts install from below through the integrated underside lug into captured nuts in the neighboring upper segment. There is no modeled counterbore or recess for bolt heads. A normal M3 socket-head or pan-head bolt would protrude below `z = 21 mm`.

This is dangerous because `z = 21 mm` is also the lower end of the floating upper hardware zone. Any protruding bolt head could become the lowest part of the upper carrier. It may touch lower locator features, overload stops, debris, or the lower base before the intended sensor stack does. That would create an accidental load bypass or assembly interference.

Recommended fix:

- Add an underside counterbore/recess to every upper integrated lug so the selected M3 bolt head sits flush with, or slightly above, the bottom of the upper lug.
- Define the intended bolt type, for example M3 socket-head cap screw or M3 button-head screw, and size the counterbore accordingly.
- Preserve at least the current upper/lower clearance after the bolt head is installed.
- Re-run boolean/clearance checks with bolt-head visual solids included.

Alternative fix:

- Change the upper seam to top-access bolts with captured nuts in the underside lug, but only if the bolt heads can be recessed on the top surface without interfering with the support grate or salt container. This may improve serviceability but needs a separate CAD pass.

### 2. Upper seam fasteners are not serviceable in installed orientation

Severity: **Medium**

Location:

- Upper integrated lugs on underside of upper segments.
- Upper bolts implied to insert from below.

Finding:

The current upper seam fastener orientation is consistent with the previous underside bridge strategy: mechanically simple, but not accessible while the upper carrier is installed on the sensor stack. To tighten or remove upper seam bolts, the salt container and support grate must be removed, then the upper carrier assembly must be lifted off and flipped or accessed from below on the bench.

This is serviceable, but it should be documented as the intended procedure. It does not support easy in-place removal of one upper segment.

Recommended fix:

- If keeping underside upper bolts, explicitly document the service sequence: remove container, remove support grate, lift upper carrier assembly, flip/access underside, remove upper seam bolts.
- If easier in-place service becomes important, investigate top-access upper fasteners with recessed heads.
- Do not solve this by adding any upper-to-lower fastener, spacer, or support.

### 3. Lower seam bolts are blocked after the upper carrier is installed

Severity: **Medium**

Location:

- Lower integrated lugs at `z = 8..12 mm`.
- Lower bolts implied to insert from above.
- Upper carrier sits above the lower ring during normal operation.

Finding:

Lower seam bolts are easy to install during lower-ring assembly. Once the upper carrier and sensor stack are installed, the lower seam bolts are not conveniently accessible from above.

This is acceptable for normal service because a sensor replacement should not require lower-ring disassembly. But if a lower segment ever needs replacement, the upper assembly must be removed first.

Recommended fix:

- Keep lower bolt heads above and lower captured nuts below; this is still the best orientation for lower ring assembly.
- Document that lower-ring service requires removing the upper carrier first.
- Do not move lower bolt heads below unless there is a strong reason; underside bolt access would be worse once the scale is on the floor.

### 4. No bolt-head counterbores or seating features are modeled

Severity: **High for upper, Minor for lower**

Location:

- `_lug_body()` creates M3 clearance holes through plain rectangular lugs.
- No counterbore, countersink, washer seat, or flat head-seat geometry is present.

Finding:

M3 bolt heads will protrude from the lug surfaces. On the lower ring, this is probably acceptable because the lower bolt heads are on top of lower lugs at about `z = 12 mm`, well below the floating upper carrier. On the upper ring, protruding underside bolt heads are not acceptable without a clearance check.

Flat seating is also not defined. FDM top surfaces are usable, but a proper head seat improves repeatability and reduces local crushing.

Recommended fix:

- Add upper-lug underside counterbores as a required fix.
- Add lower-lug shallow counterbores or washer seats as an optional improvement.
- Choose one standard bolt head style for the default BOM before finalizing recess dimensions.
- Avoid countersunk screws unless there is a strong reason; countersinks can split printed plastic and introduce wedging forces.

### 5. Bolts are currently doing too much alignment work

Severity: **High**

Location:

- Integrated seam between neighboring upper or lower segments.
- M3 clearance holes: `3.4 mm`.
- No separate locator features in concept v4 seam geometry.

Finding:

The integrated seam currently relies on bolt holes/lugs for both clamping and positional alignment. That is not ideal. M3 clearance holes need play so builders can insert screws. That same play allows seam shift, ring ovality, and inconsistent support-grate receiver alignment.

Fasteners should clamp. Separate printed features should locate.

Recommended fix:

Add dedicated same-layer alignment geometry separate from the M3 fasteners. Good candidates:

- A shallow tongue-and-groove along each radial seam.
- A printed rectangular shear key and matching pocket.
- Two small tapered printed locator bosses with matching sockets.
- A stepped lap edge that constrains tangential shift while bolts only clamp.

Design rules for locators:

- Lower locators connect only lower-to-lower.
- Upper locators connect only upper-to-upper.
- No locator may bridge upper to lower.
- Locator clearance is now validated at `0.3 mm per side` for the concept v4 tongue/socket seam locator.
- Locators should not be so tight that segment assembly requires hammering.

### 6. Integrated lug roots may be PETG stress concentrators

Severity: **Medium**

Location:

- `_lug_body()`
- Rectangular integrated lugs, about `24 x 30 x 4 mm`, joined to annular segment edge.

Finding:

The lugs are printed flat, which is good. The load from seam tightening is mostly in-plane, which is also good for FDM. But the current lugs appear as simple rectangular pads with sharp transitions into the segment. Repeated tightening, overtightening, or twisting during assembly may concentrate stress at the lug root.

Recommended fix:

- Add generous fillets or rounded root transitions where lugs meet the ring segment.
- Add broad triangular or curved gusset-like shoulders in the XY plane where practical.
- Keep lugs thick enough for bolt-head/nut seating after counterbores are added.
- Add a physical lug coupon before committing to full v4 printing.

### 7. Integrated lugs increase replacement cost if damaged

Severity: **Medium**

Location:

- All integrated seam lugs.

Finding:

Bridge plates were extra parts, but they were also sacrificial and replaceable. In v4, if a lug cracks, is over-tightened, or prints poorly, the full upper or lower segment may need reprinting.

Recommended fix:

- Keep the integrated approach because it reduces assembly burden, but validate lug durability before treating v4 as default.
- Consider making the lug area more robust than the minimum needed.
- Specify torque guidance in assembly docs, for example snug by hand, do not crush PETG.

### 8. Nut insertion sequence must be documented clearly

Severity: **Minor**

Location:

- Lower captured nuts: underside of receiving seam.
- Upper captured nuts: top side of receiving seam.

Finding:

The captured nut dimensions are already physically validated. The issue is assembly order, not geometry. Lower nuts must be pressed into the underside before the lower ring is placed on the floor. Upper nuts press in from the top side, but support grate parts may need to be removed for inspection or access.

Recommended fix:

- Document nut insertion before ring assembly.
- Show lower nut orientation and upper nut orientation in an exploded view.
- Add `NUT` or `M3` engraved labels only on non-contact surfaces if there is enough room.

### 9. Support grate must be removed before upper service

Severity: **Minor**

Location:

- Split support grate bars imported from concept v3.
- Upper support-grate receiver remains upper-only.

Finding:

The support grate does not appear to create a load-path issue, but it spans upper regions and will obstruct handling the upper carrier. Any upper seam or sensor service sequence should start by removing the salt container and support grate bars.

Recommended fix:

- Document support grate removal as the first mechanical service step after removing the salt container.
- Keep the grate removable by hand.
- Do not add grate fasteners until the full upper-carrier fit is physically tested.

### 10. Fastener length is undefined

Severity: **Minor**

Location:

- Integrated M3 lug stack: 4 mm lug plus segment thickness/nut pocket region.

Finding:

The model defines clearances and nut pockets but not screw length or head style. Builders need a standard length that engages the nut reliably without bottoming out or protruding into a forbidden area.

Recommended fix:

- After counterbore choice, define a default screw length in the docs and BOM.
- Likely candidates are M3x12 or M3x14, but this should be confirmed from the final stack depth and selected head style.
- Include a note that bolts should not protrude into support-grate receivers or below the upper lug plane.

## Fastener Orientation Recommendation

### Lower ring

Recommended orientation:

```text
bolt head above -> integrated lower lug -> neighboring lower segment -> captured nut below
```

Reason:

- Easiest lower-ring assembly on the bench.
- Avoids needing access below a floor-supported scale.
- Lower bolt head protrusion is unlikely to affect the measurement stack if it remains below the floating upper structure.

Recommended refinement:

- Optional shallow head seat/counterbore.
- Required clear assembly note that lower nuts are inserted before final placement.

### Upper ring

Current implied orientation:

```text
bolt head below -> integrated upper underside lug -> neighboring upper segment -> captured nut above
```

This is mechanically consistent but needs a required underside counterbore so bolt heads do not protrude below the upper carrier.

Best near-term recommendation:

- Keep this orientation for now because it preserves a clean upper surface for the support grate and salt container.
- Add flush underside counterbores.
- Document that upper seam service requires lifting/removing the upper carrier assembly.

Possible future improvement:

- Top-access upper bolts with recessed heads, only if they can avoid support-grate and container interference.

## Serviceability Review

### Can one segment be removed later?

Conditionally yes. A segment can be removed if both seam connections around it are accessible and all bolts are removed. However, because v4 uses integrated lap lugs, the removal direction may be more constrained than with loose bridge plates. This should be validated with a two-segment seam coupon before printing a full ring.

### Can one sensor be replaced later?

Yes in principle. The sensor replacement sequence remains:

1. Remove salt container.
2. Remove support grate bars.
3. Lift upper carrier assembly or remove the local upper segment if fasteners are accessible.
4. Remove upper pad.
5. Remove/replace sensor from the outside.
6. Reassemble and recalibrate.

The current upper fastener orientation means lifting the upper carrier assembly is the realistic service path.

### Does support grate interfere with service?

Yes, but acceptably. It must be removed before upper carrier service. It remains upper-only and does not create a load bypass.

## Printability Review

Strengths:

- Integrated lugs print flat.
- No support generation should be needed for the main lug shape.
- The segments still fit the Prusa MK4/MK4S/Core One bed.
- The captured nut geometry has already been validated in a coupon.

Risks:

- Lug roots may curl or lift if placed near bed edges.
- Sharp lug transitions may crack if overtightened.
- Counterbores, once added, may reduce lug thickness if not sized carefully.
- Upper underside lugs and bolt heads need careful slicer inspection because they are near the intentional upper/lower clearance boundary.

Recommended validation before full v4 print:

1. Print a two-segment lower integrated-lug seam coupon.
2. Print a two-segment upper integrated-lug seam coupon with bolt-head recess.
3. Test assembly, tightening, removal, and repeated cycles.
4. Check whether segments align without relying on bolt shanks.
5. Add locator geometry if seam shift is visible.

## Overall Recommendation

Do not modify the architecture, but do refine the integrated seam before treating `concept_v4` as the new baseline.

Required before full-platform v4 printing:

1. Add upper bolt-head recesses or choose a safer upper fastener orientation.
2. Add dedicated same-layer alignment features separate from M3 bolts.
3. Add PETG-friendly lug root radii/shoulders.
4. Validate with lower and upper integrated seam coupons.

`concept_v4` remains a promising assembly-simplification candidate, but the current fastener/head/alignment details need another CAD pass.

## 2026-06-07 CAD Fix Status

Applied in `cad/src/concept_v4_integrated_joining.py`:

- Selected M3 button-head screws as the default integrated-seam fastener assumption.
- Added underside counterbores to upper integrated lugs.
- Modeled simple M3 button-head visual solids in assembly STEP exports.
- Added same-layer printed tongue/socket seam locators separate from M3 holes.
- Offset receiving M3 holes/nut pockets into the receiving segment to remove same-layer seam overlap.
- Added broad flat XY lug-root shoulders for PETG-friendly reinforcement.
- Added cropped real-geometry lower and upper integrated seam coupons.

Current fastener assumption:

- M3 button-head screw.
- Modeled head diameter: `5.7 mm`.
- Modeled head height: `1.8 mm`.
- Upper counterbore diameter: `6.4 mm`.
- Upper counterbore depth: `2.0 mm`.

Current locator geometry:

- Printed tongue/socket at the same seam layer.
- Validated `0.3 mm per side` PETG-friendly clearance.
- Bolts clamp; locators align.
- `0.4 mm` and `0.5 mm` were physically tested and showed unnecessary play; no tighter variant is currently required.

Verification checks after the CAD pass:

- Lower segment 0 vs lower segment 1: `0.0 mm^3` overlap.
- Upper segment 0 vs upper segment 1: `0.0 mm^3` overlap.
- Upper segment 0 vs lower segment 0: `0.0 mm^3` overlap.
- Support grate bar X vs upper segment 0: `0.0 mm^3` overlap.
- Support grate bar Y vs upper segment 0: `0.0 mm^3` overlap.
- Support grate bar X vs lower segment 0: `0.0 mm^3` overlap.

Generated validation coupons:

```text
cad/exports/experimental/stl/concept_v4_lower_integrated_seam_coupon_v1.stl
cad/exports/experimental/stl/concept_v4_upper_integrated_seam_coupon_v1.stl
```

Updated recommendation:

Print the upper integrated seam coupon first. It tests the most critical fix: recessed underside upper bolt-head clearance. Do not print full v4 ring segments until both seam coupons pass fit, tightening, removal, and repeated assembly tests.

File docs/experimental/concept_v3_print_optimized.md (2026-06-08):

# Concept v3 Print-Optimized Candidate

Date: 2026-06-06

## Summary

`concept_v3_print_optimized` is a print-efficiency candidate derived from the active `concept_v2` architecture. It is not a redesign of the measurement principle. It keeps the four-sensor floating upper/lower architecture and changes only the printable decomposition where that appears likely to reduce print plates.

The main changes are:

- 8 upper ring sectors instead of 4.
- 8 lower ring sectors instead of 4.
- Four alternating lower sectors include sensor stations.
- Four alternating upper sectors include sensor contact lands.
- The support grate is split into two half-lap bars instead of one cross-shaped part.

## What Stayed The Same

- Four load sensors.
- Floating upper carrier over lower base.
- Upper and lower remain mechanically separate.
- No upper-to-lower fasteners or bridges.
- Captured M3 nuts plus printed bridge plates remain the default segment joining method.
- Support-grate tab/slot clearance remains `0.4 mm per side`.
- v3-style low sensor locator remains the sensor-station direction.
- Engraved labels remain the default.
- Sensors remain serviceable from the outside after upper parts are lifted or removed.

## Printable Parts

Active concept v3 STLs:

- `cad/exports/active/stl/concept_v3_lower_sensor_segment_0.stl`
- `cad/exports/active/stl/concept_v3_lower_plain_segment_1.stl`
- `cad/exports/active/stl/concept_v3_upper_sensor_segment_0.stl`
- `cad/exports/active/stl/concept_v3_upper_plain_segment_1.stl`
- `cad/exports/active/stl/concept_v3_support_grate_bar_x.stl`
- `cad/exports/active/stl/concept_v3_support_grate_bar_y.stl`
- `cad/exports/active/stl/concept_v3_lower_bridge_plate.stl`
- `cad/exports/active/stl/concept_v3_upper_bridge_plate.stl`
- `cad/exports/active/stl/concept_v3_lower_pad.stl`
- `cad/exports/active/stl/concept_v3_upper_pad.stl`
- `cad/exports/active/stl/concept_v3_sensor_placeholder.stl`

Repeat counts for a full mechanical prototype:

- 4x lower sensor segments.
- 4x lower plain segments.
- 4x upper sensor segments.
- 4x upper plain segments.
- 8x lower bridge plates.
- 8x upper bridge plates.
- 4x lower pads.
- 4x upper pads.
- 4x sensors or placeholders.
- 1x support grate bar X.
- 1x support grate bar Y.

## Approximate Part Dimensions

Measured from CAD bounding boxes:

| Part | Approximate envelope |
| --- | ---: |
| Lower sensor segment | 108 x 113 x 21 mm |
| Lower plain segment | 111 x 108 x 8 mm |
| Upper sensor segment | 102 x 107 x 14 mm |
| Upper plain segment | 107 x 102 x 14 mm |
| Support grate bar X | 178 x 22 x 4 mm |
| Support grate bar Y | 22 x 178 x 4 mm |
| Bridge plates | 64 x 30 x 4 mm |

## Expected Plate Count

`concept_v2` likely needs about 9 practical large-part plates: four lower, four upper, and one support grate.

`concept_v3` should be closer to about 6 practical plates if the slicer can place two to three sectors per bed and nest the support-grate bars and small parts into remaining space. This depends on brim settings, PETG spacing, and user comfort with multi-part plates.

## Assembly Logic

The full ring alternates segment types:

```text
lower sensor, lower plain, lower sensor, lower plain, ...
upper sensor, upper plain, upper sensor, upper plain, ...
```

Each sensor lower segment has the low-profile sensor locator. Each matching upper sensor segment has the upper contact land. Plain segments are structural ring continuation pieces.

The support grate uses two bars with a center half-lap. Both bars are upper-only. They must never contact the lower base.

## Assembly Order

1. Print sensor and plain lower segments.
2. Press captured M3 nuts into lower segments from the underside.
3. Assemble the lower ring with lower-only bridge plates and M3 bolts.
4. Place lower pads, sensors, and upper pads in the four sensor stations.
5. Print sensor and plain upper segments.
6. Press captured M3 nuts into upper segments from the top side.
7. Assemble the upper ring separately with underside upper-only bridge plates and M3 bolts.
8. Install the two support-grate bars into the upper-only receivers.
9. Lower the upper ring assembly onto the four upper pads.
10. Confirm that upper and lower parts touch only through the sensor stacks in normal unloaded assembly.

## Verification Checks Already Done In CAD

Quick boolean checks on the initial v3 CAD showed:

- Support grate bar X vs upper sensor segment: `0.0 mm^3` overlap.
- Support grate bar Y vs upper sensor segment: `0.0 mm^3` overlap.
- Support grate bar X vs lower sensor segment: `0.0 mm^3` overlap.
- Upper sensor segment vs lower sensor segment: `0.0 mm^3` overlap.
- Support grate bar X vs bar Y half-lap: `0.0 mm^3` overlap.

## Risks

- More seams and fasteners than concept_v2.
- More parts to sort and orient.
- Smaller segments may be less self-aligning during assembly.
- Split support grate needs physical validation.
- Bridge plate behavior at eight seams is not yet physically validated as a full ring.

## Recommendation

Inspect this candidate before printing:

```text
cad/exports/active/step/concept_v3_one_section_assembly.step
```

If it looks coherent, inspect these STLs in PrusaSlicer:

```text
cad/exports/active/stl/concept_v3_lower_sensor_segment_0.stl
cad/exports/active/stl/concept_v3_upper_sensor_segment_0.stl
cad/exports/active/stl/concept_v3_support_grate_bar_x.stl
```

Do not retire `concept_v2` until one v3 sensor section and one v3 seam pair are physically checked.

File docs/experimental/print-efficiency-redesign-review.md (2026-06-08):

# Print-Efficiency Redesign Review

Date: 2026-06-06

## Summary

The current `concept_v2` architecture is mechanically much cleaner than the earlier platform work, but it is not print-efficient. The main issue is not that any one part is too large; it is that the four lower quadrants and four upper quadrants are each too large to pair reliably on a 250 x 210 mm Prusa MK4/MK4S/Core One bed. The support grate is also a separate 178 x 178 mm print unless it is split.

The best print-efficiency candidate is an eight-segment ring with four alternating sensor segments and four plain filler segments, plus a split two-bar support grate. This keeps the validated four-sensor floating architecture and the same upper/lower separation, but makes the largest repeated parts roughly 108 x 113 mm instead of roughly 159 x 159 mm.

Recommendation: keep `concept_v2` as the current mechanically validated baseline, and create `concept_v3_print_optimized` as a print-efficiency candidate for inspection and future physical validation. `concept_v3` is not a release replacement until its extra seams, split support grate, and smaller upper/lower sectors are physically tested.

## Constraints Preserved

All evaluated strategies keep these rules unless noted otherwise:

- Four load sensors.
- Floating upper carrier over lower base.
- Upper and lower remain mechanically separate.
- No upper-to-lower fasteners, bridges, dowels, clips, walls, or spacers.
- Captured M3 nuts plus printed bridge plates remain the default seam strategy.
- Support-grate clearance remains `0.4 mm per side`.
- Engraved label standard remains `7-8 mm` text height and `0.8 mm` depth where space allows.
- Sensor remains serviceable from the outside after lifting/removing upper parts.

## Current Part Envelope Reference

Measured from current CAD bounding boxes:

| Part | Approximate envelope |
| --- | ---: |
| `concept_v2_lower_segment_0` | 159 x 159 x 21 mm |
| `concept_v2_upper_segment_0` | 153 x 153 x 14 mm |
| `concept_v2_support_grate` | 178 x 178 x 4 mm |
| Bridge plates | 64 x 32 x 4 mm |
| Lower pad | 44 x 44 x 2 mm |
| Upper pad | 56 x 56 x 3 mm |
| Sensor placeholder | 54 x 38 x 12 mm |

A 250 x 210 mm bed cannot comfortably take two current lower segments or two current upper segments. The small parts can be nested with larger sheets, but they do not solve the main plate count.

## Strategy 1: Current Concept v2

Description:

- 4 lower quadrants.
- 4 upper quadrants.
- 1 one-piece cross support grate.
- Small bridge plates, pads, and sensor placeholders.

Estimated print plates:

- About 9 practical plates: 4 lower, 4 upper, 1 support grate.
- Small pads and bridge plates can be nested into unused areas.

Largest part dimensions:

- Lower segment: about 159 x 159 mm.
- Upper segment: about 153 x 153 mm.
- Support grate: about 178 x 178 mm.

Expected print complexity:

- Low. Large, flat PETG-friendly parts.
- Few unique segment types.

Assembly complexity:

- Medium. Four seams per layer.
- Default full build uses 4 lower bridge plates and 4 upper bridge plates.

Fasteners:

- About 16 M3 bolts/nuts for the lower ring and 16 for the upper ring if each seam bridge uses four bolts.

Serviceability impact:

- Good. One large upper quadrant corresponds to one sensor region.

Load-path risk:

- Low. This is the clearest current architecture.

Beginner friendliness:

- Good mechanically, weaker on print commitment because it asks for many long sheets.

Verdict:

- Best mechanical baseline. Not the best build-accessibility path.

## Strategy 2: Smaller 8-Segment Ring

Description:

- 8 lower sectors.
- 8 upper sectors.
- Four alternating sectors include sensor station/contact land geometry.
- Four alternating sectors are plain ring sectors.
- Same captured M3 nut and bridge-plate seam strategy.

Estimated print plates:

- About 6 practical plates for the major ring parts if users can place two to three sectors per sheet.
- The estimate depends heavily on slicer spacing, brim settings, and whether the user prints sensor/plain sectors together.

Largest part dimensions:

- Lower sensor segment candidate: about 108 x 113 x 21 mm.
- Lower plain segment candidate: about 111 x 108 x 8 mm.
- Upper sensor segment candidate: about 102 x 107 x 14 mm.
- Upper plain segment candidate: about 107 x 102 x 14 mm.

Expected print complexity:

- Low to medium. Parts are smaller and less warp-prone, but there are more of them.

Assembly complexity:

- Higher than v2. Eight seams per layer instead of four.

Fasteners:

- Potentially doubles seam fasteners compared with v2 if the same four-bolt bridge is used at every seam.

Serviceability impact:

- Mixed. Smaller upper sectors are easier to handle, but there are more seams to loosen if a section needs removal.

Load-path risk:

- Low if upper/lower seams remain same-layer only.
- Slightly higher practical risk because more seams create more places for assembly mistakes.

Beginner friendliness:

- Better for printing, worse for assembly.

Verdict:

- Promising enough to model as `concept_v3_print_optimized`.

## Strategy 3: Hybrid Lower 4 / Upper 8

Description:

- Keep four lower sensor-bearing segments.
- Split the upper carrier into eight smaller sectors.
- Split or nest support grate parts.

Estimated print plates:

- About 7 practical plates: 4 lower plus around 2-3 upper/support plates.

Largest part dimensions:

- Lower remains about 159 x 159 mm.
- Upper becomes about 102 x 107 mm per sector.

Expected print complexity:

- Medium-low.

Assembly complexity:

- Medium-high because upper and lower seam patterns differ.

Fasteners:

- Lower stays about the same as v2; upper doubles.

Serviceability impact:

- Potentially good, because upper service pieces are smaller.
- Documentation burden increases because lower and upper segment counts differ.

Load-path risk:

- Low if documented well, but mismatch between upper/lower seams could confuse builders.

Beginner friendliness:

- Moderate. It saves plates without fully doubling lower seams, but the asymmetry is harder to explain.

Verdict:

- Useful fallback if eight lower segments prove too annoying, but not the cleanest default story.

## Strategy 4: More Rectangular/Cropped Four-Segment Shape

Description:

- Keep four segments but crop away nonessential corner material or alter the annular sector boundary to make parts pack better.

Estimated print plates:

- Likely still 8-9 plates.
- Cropping may reduce material and time, but probably will not allow two major sectors per 250 x 210 mm bed.

Largest part dimensions:

- Could reduce local material, but the outer diameter and 90-degree sector still drive a roughly 150-160 mm footprint.

Expected print complexity:

- Medium. More complex outlines and possibly less intuitive support.

Assembly complexity:

- Similar to v2.

Fasteners:

- Similar to v2.

Serviceability impact:

- Similar to v2 if sensor stations stay intact.

Load-path risk:

- Medium if cropping removes stiffness or makes upper carrier support less predictable.

Beginner friendliness:

- Mixed. Fewer grams, not necessarily fewer plates.

Verdict:

- Not enough benefit for the risk.

## Strategy 5: Split Support Grate Only

Description:

- Keep the current four-segment upper/lower rings.
- Split the one-piece support grate into two interlocking bars or four removable arms that can nest with other plates.

Estimated print plates:

- About 8 instead of 9 if the grate pieces fit on lower/upper segment sheets.

Largest part dimensions:

- Ring segments unchanged.
- Support grate bars can be about 178 x 22 mm.

Expected print complexity:

- Low.

Assembly complexity:

- Slightly higher because the grate is now multiple parts.

Fasteners:

- No additional fasteners required if the grate remains captured by gravity/container load.

Serviceability impact:

- Good if bars remain removable by hand.

Load-path risk:

- Low, as long as grate remains upper-only.

Beginner friendliness:

- Good, but the plate-count improvement is modest.

Verdict:

- Worth combining with the eight-segment strategy. Alone, it is helpful but not transformative.

## Recommendation

Create `concept_v3_print_optimized` as a candidate, not a replacement.

Recommended v3 strategy:

- 8 lower sectors: 4 sensor sectors, 4 plain sectors.
- 8 upper sectors: 4 sensor/contact-land sectors, 4 plain sectors.
- Same captured M3 nut pockets and printed bridge plates.
- Same four sensor stacks.
- Split two-bar half-lap support grate.

Expected benefit:

- Current concept_v2 practical major-part print count: about 9 plates.
- Concept v3 practical major-part print count: about 6 plates, assuming two to three small sectors can be placed per sheet and grate bars are nested with other parts.

Main cost:

- Twice as many upper/lower seams.
- More M3 hardware.
- More opportunities for assembly error.

This is a good trade to evaluate because the most common maker failure mode may be abandoning the project before finishing eight large plates. Smaller parts lower that psychological and practical barrier, especially for PETG warping risk and partial reprints.

## New Risks Introduced By Concept v3

- Eight seams per ring may reduce ring stiffness unless bridge plates work well at full scale.
- Fastener count may feel tedious.
- Alternating sensor/plain segment types must be labeled clearly.
- The split support grate half-lap needs physical validation.
- Smaller upper sectors may distribute load less smoothly unless the support grate is installed correctly.
- Builders must not accidentally mix upper/lower bridge plates or create any upper-to-lower connection.

## What To Inspect First

Inspect first:

```text
cad/exports/active/step/concept_v3_one_section_assembly.step
```

Then inspect:

```text
cad/exports/active/step/concept_v3_assembly.step
```

First printable STL to inspect in PrusaSlicer:

```text
cad/exports/active/stl/concept_v3_lower_sensor_segment_0.stl
```

Second printable STL to inspect:

```text
cad/exports/active/stl/concept_v3_upper_sensor_segment_0.stl
```

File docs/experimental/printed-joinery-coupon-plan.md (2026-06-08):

# Printed Joinery Coupon Plan

Date: 2026-06-05

## Summary

This document is now historical for default strategy selection.

The current default segment joining strategy is documented in `docs/segment-joining-strategy.md`: M3 bolts, standard M3 nuts, and printed bridge plates. Printed-only joints remain experimental validation coupons.

SaltScale should not require metal dowels or heat-set inserts for the default open-source assembly. Earlier work explored whether the default path could be fully printed, low-cost, removable, and hobby-friendly.

This plan defines printed-only seam coupons for `concept_v2`. They do not modify the full platform geometry. They are small validation prints for upper-to-upper and lower-to-lower segment joining only.

Current coupon targets:

- `printed_lower_seam_sliding_key_coupon_v1`
- `printed_upper_seam_sliding_key_coupon_v1`
- `printed_lower_seam_true_dovetail_coupon_v1`
- `printed_upper_seam_true_dovetail_coupon_v1`
- `printed_lower_seam_wedge_coupon_v2`
- `printed_upper_seam_wedge_coupon_v2`

Archived/misleading names:

- `printed_lower_seam_dovetail_coupon_v1`
- `printed_upper_seam_dovetail_coupon_v1`

Those v1 dovetail exports were reclassified because the printed geometry behaved more like a straight sliding key than a true mechanically captured dovetail.

Each current coupon is a print-flat kit containing:

- Two segment-edge blocks.
- One separate removable printed key.
- Short engraved labels: `LOWER`, `UPPER`, `KEY`, `OUT`, `IN`, `SLIDE`, `DOVE`, or `WEDGE`.

## Why no-metal joinery was explored

Printed-only joinery was explored because it:

- Reduces hardware cost.
- Avoids heat-set insert tools.
- Avoids 4 mm dowel sourcing.
- Avoids corrosion-prone alignment hardware near salt.
- Makes the design easier to reproduce from only filament and common hand tools.
- Could keep M3 inserts and metal dowels as optional upgrades rather than default requirements.

The printed joinery remains same-layer only. It must never connect the floating upper carrier to the lower base.

After wedge analysis, printed-only joinery is no longer recommended as the default. The wedge key mainly prevents separation after manual seam closure; it does not actively pull the seam closed. These coupons remain useful experiments.

## Strategy 1: sliding key

Files:

- `cad/exports/validation/stl/printed_lower_seam_sliding_key_coupon_v1.stl`
- `cad/exports/validation/step/printed_lower_seam_sliding_key_coupon_v1.step`
- `cad/exports/validation/stl/printed_upper_seam_sliding_key_coupon_v1.stl`
- `cad/exports/validation/step/printed_upper_seam_sliding_key_coupon_v1.step`

What it tests:

- A straight printed key sliding into a top-open slot across the seam.
- Simple printed alignment and basic seam separation resistance.
- Removability with minimum geometry and no hardware.

Important limitation:

- This is not a dovetail.
- It is not mechanically captured against vertical pull-out.
- It is useful as a simple printed key, but it should not be treated as the strongest no-metal option.

Expected fit:

- Easiest to print and clean.
- Should slide by hand after light deburring.
- May have more rattle or lift than the dovetail or wedge.

Pass criteria:

- Key inserts fully by hand.
- Key removes by hand.
- Blocks do not separate under light hand pulling while the key is seated.
- No key or slot cracking after five insert/remove cycles.

## Strategy 2: true dovetail

Files:

- `cad/exports/validation/stl/printed_lower_seam_true_dovetail_coupon_v1.stl`
- `cad/exports/validation/step/printed_lower_seam_true_dovetail_coupon_v1.step`
- `cad/exports/validation/stl/printed_upper_seam_true_dovetail_coupon_v1.stl`
- `cad/exports/validation/step/printed_upper_seam_true_dovetail_coupon_v1.step`

What it tests:

- A trapezoidal/dovetail key sliding into a matching undercut slot.
- Mechanical capture against seam pull-out perpendicular to the seam.
- Whether PETG can print the shallow dovetail lips cleanly without supports.
- Whether the captured key remains removable.

Expected fit:

- Strongest mechanical capture if the print is accurate.
- More tolerance-sensitive than sliding key or wedge.
- May need careful elephant-foot cleanup before insertion.

Pass criteria:

- Key starts from the end and slides fully into the dovetail slot.
- Blocks resist seam separation better than the sliding key.
- Key can still be removed without damaging the lips.
- Dovetail lips do not crack or delaminate.

Fail criteria:

- Key cannot start after normal cleanup.
- Key jams partway through.
- Dovetail lips split.
- Print variation makes the fit unreliable.

## Strategy 3: wedge key v2

Files:

- `cad/exports/validation/stl/printed_lower_seam_wedge_coupon_v2.stl`
- `cad/exports/validation/step/printed_lower_seam_wedge_coupon_v2.step`
- `cad/exports/validation/stl/printed_upper_seam_wedge_coupon_v2.stl`
- `cad/exports/validation/step/printed_upper_seam_wedge_coupon_v2.step`

What it tests:

- A tapered printed key in a matching tapered top-open pocket.
- Progressive self-tightening as the wedge is pushed from `OUT` toward `IN`.
- A more forgiving printed-only seam than the true dovetail.
- Removability with light hand-tool assistance.

Expected fit:

- Easier to start than the true dovetail.
- More clamping action than the sliding key.
- Likely best beginner-friendly no-metal option if it seats repeatably.

Pass criteria:

- Wedge starts easily.
- Wedge seats with thumb pressure or light tool pressure.
- Blocks resist light to moderate seam pulling.
- Wedge can be removed without damaging the pocket.
- No visible wear problem after five insert/remove cycles.

Fail criteria:

- Wedge bottoms out while the seam remains loose.
- Wedge requires hammering.
- Wedge chews up the pocket.
- Blocks separate easily while the wedge is installed.

## Strategy considered but not generated: tongue-and-groove only

A tongue-and-groove-only seam was considered, but it mainly improves alignment, not retention. It may be combined with one of the generated strategies later, but by itself it is not enough for the default seam connection.

## Recommended printed-only experiment

If testing printed-only joinery anyway, print first:

```text
cad/exports/validation/stl/printed_lower_seam_wedge_coupon_v2.stl
```

Reason:

- It is the most beginner-friendly no-metal candidate.
- It should be less tolerance-sensitive than the true dovetail.
- It may reduce play better than the simple sliding key.
- The lower seam is the simpler same-layer first test.

For the current default segment-joining strategy, print this instead:

```text
cad/exports/validation/stl/bolted_lower_seam_coupon_v1.stl
```

Print second:

```text
cad/exports/validation/stl/printed_lower_seam_true_dovetail_coupon_v1.stl
```

Reason:

- It tests the strongest mechanically captured no-metal option.
- It is worth validating after the easier wedge fit is understood.

Print third only if needed:

```text
cad/exports/validation/stl/printed_lower_seam_sliding_key_coupon_v1.stl
```

Reason:

- It is simple and may still be useful, but it is not mechanically locked like a dovetail and should not be the preferred default unless the other designs fail.

## What to measure

For each coupon:

- Whether the key starts by hand.
- Whether the key seats fully.
- Whether the seam closes flush.
- How much force is needed to remove the key.
- Whether visible wear appears after five insert/remove cycles.
- Whether the blocks separate under hand pulling.
- Whether labels remain readable after printing.

## Design recommendation after testing

Experimental printed-only candidate if it passes:

- Wedge key v2.

Stronger optional printed-only candidate:

- True dovetail.

Simplest printed-only fallback:

- Sliding key.

Use M3 bolts, standard M3 nuts, and printed bridge plates as the current default. Keep heat-set inserts as optional. Keep metal dowels out of the default unless future testing proves they are necessary.

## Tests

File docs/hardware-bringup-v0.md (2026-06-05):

# Hardware Bring-Up v0

Date: 2026-06-05

## Summary

This is the first electronics validation workflow for SaltScale after the first hardware order.

The goal is not to build product firmware. The goal is only to prove that four load sensors, the SparkFun Load Sensor Combinator, the SparkFun HX711, and the Seeed Studio XIAO ESP32C3 can produce sensible raw readings over USB serial.

Important source-of-truth note: `hardware/loadcell-spec.md` and the redesign documents describe the current four-sensor architecture. `hardware/bom.md` still contains older single-point-loadcell assumptions and should not guide this bring-up.

## Expected hardware

- 5x 50 kg Kiwi/SparkFun-style load sensors.
- SparkFun Load Sensor Combinator.
- SparkFun HX711 load cell amplifier.
- Seeed Studio XIAO ESP32C3.
- USB-C data cable.
- Connector cables or temporary jumper wiring.
- Optional button and LED, not used yet.

Use four sensors for the first bridge. Keep the fifth sensor as a spare and dimensional reference.

## 1. Bench setup overview

Build the first electronics stack on the bench, separate from the printed platform:

```text
4x load sensors
-> SparkFun Load Sensor Combinator
-> SparkFun HX711
-> XIAO ESP32C3
-> computer over USB-C
-> serial monitor
```

Do the first test with sensors loose on the bench or lightly held in a simple test fixture. Do not install the electronics into an enclosure, scale body, or utility-closet location yet.

Recommended bench conditions:

- Clean, dry table.
- USB power only.
- Short sensor wires where practical.
- No battery connected.
- No salt container on the sensors.
- No button or LED connected.
- One wiring change at a time.

## 2. Wiring plan

### Four load sensors to combinator

Wire four 50 kg load sensors into the SparkFun Load Sensor Combinator according to the combinator board labels and SparkFun wiring guide.

Conceptually:

- One sensor per combinator corner/input.
- Keep sensor orientation consistent.
- Route all four sensors the same way if possible.
- Leave the fifth sensor unconnected as a spare.

Before powering anything:

- Check that no bare wire strands bridge adjacent pads.
- Check that each sensor has strain relief during bench handling.
- Label sensors `S1`, `S2`, `S3`, and `S4` with tape.
- Record which physical sensor is connected to each combinator input.

### Combinator to HX711

Wire the combinator bridge output to the HX711 input.

Use the board labels rather than wire color assumptions. Typical bridge labels are:

```text
Combinator E+  -> HX711 E+
Combinator E-  -> HX711 E-
Combinator S+  -> HX711 A+
Combinator S-  -> HX711 A-
```

Use HX711 channel A for the first test. Do not use channel B yet.

### HX711 to XIAO ESP32C3

Power the HX711 from the XIAO so signal levels match the microcontroller:

```text
HX711 VCC -> XIAO 3V3
HX711 GND -> XIAO GND
HX711 DT  -> XIAO digital input pin
HX711 SCK -> XIAO digital output pin
```

Suggested first firmware pin mapping:

```text
HX711 DT  -> XIAO D2
HX711 SCK -> XIAO D3
```

This mapping is only a bring-up default. Verify the XIAO ESP32C3 pinout before soldering or making a permanent harness.

### XIAO to computer over USB-C

Connect the XIAO ESP32C3 to the computer with a USB-C data cable.

Confirm the board appears as a serial device before connecting the sensor bridge. Charge-only USB-C cables are a common failure mode.

## 3. Power and safety warnings

Do not use battery power yet.

First bring-up rules:

- Power the XIAO from USB-C only.
- Power the HX711 from the XIAO `3V3` pin.
- Do not connect a battery.
- Do not connect a charger module.
- Do not connect the optional button.
- Do not connect the optional LED.
- Do not connect Wi-Fi or network services in firmware.
- Disconnect USB before rewiring the sensor bridge.

If any board becomes hot, unplug USB immediately and inspect wiring.

## 4. First test firmware goal

The first firmware should do only this:

- Initialize the HX711.
- Read raw HX711 values.
- Print raw values over USB serial.
- Optionally print a simple running average.

Explicitly do not include:

- Wi-Fi.
- Deep sleep.
- Battery measurement.
- MQTT.
- Calibration factor.
- Tare persistence.
- Salt percentage calculation.
- Button handling.
- LED status behavior.

Good first output is boring:

```text
raw: 8421310
raw: 8421288
raw: 8421362
```

The absolute number does not matter yet. Direction, stability, and sensor contribution matter.

## 5. Test procedure

### Step 1: visual inspection

Before USB power:

1. Confirm all four sensors are connected to the combinator.
2. Confirm combinator bridge output goes to HX711 channel A.
3. Confirm HX711 power is from XIAO `3V3` and `GND`.
4. Confirm HX711 `DT` and `SCK` go to the selected XIAO digital pins.
5. Confirm no optional button, LED, battery, or charger is connected.

### Step 2: no-load serial reading

1. Connect the XIAO to the computer over USB-C.
2. Open the serial monitor.
3. Confirm raw values appear.
4. Leave the bench untouched for 30-60 seconds.
5. Watch whether the values are roughly stable.

Expected result:

- Values should update continuously.
- Small noise is normal.
- Large jumps without touching anything indicate wiring, power, or mechanical instability.

### Step 3: press each sensor by hand

Press each sensor gently, one at a time:

1. Press `S1`, release, observe raw value change.
2. Press `S2`, release, observe raw value change.
3. Press `S3`, release, observe raw value change.
4. Press `S4`, release, observe raw value change.

Expected result:

- Every sensor should affect the reading.
- Similar presses should produce the same sign of change.
- The magnitude does not need to match perfectly during hand tests.

### Step 4: check sign and direction

Choose one direction as positive for the first notes. For example:

```text
pressing down should increase raw value
```

If pressing down decreases raw value, that is not automatically a failure. The sign can be corrected later in firmware or by swapping signal polarity, but all four sensors should agree.

### Step 5: combined contribution check

Press two or more sensors at the same time.

Expected result:

- Combined pressing should create a larger change than pressing one sensor alone.
- If one sensor has no effect, troubleshoot before moving on.

### Step 6: document results

Record:

- Sensor labels and combinator inputs.
- HX711-to-XIAO pin mapping.
- No-load raw range.
- Direction of each sensor response.
- Any sensor that behaves differently.
- Photos of the wiring.

## 6. Troubleshooting

### No serial output

Likely causes:

- USB-C cable is charge-only.
- Wrong serial port selected.
- Board not flashed.
- Serial baud rate mismatch.
- XIAO not powered.

Checks:

- Try another USB-C data cable.
- Confirm the XIAO appears as a serial device.
- Upload a minimal serial test before involving HX711 code.

### Serial output appears, but no HX711 signal

Likely causes:

- HX711 `DT` or `SCK` pins swapped or mapped incorrectly.
- HX711 not powered.
- No common ground.
- Firmware pin definitions do not match wiring.

Checks:

- Measure HX711 `VCC` to `GND`.
- Confirm `DT` and `SCK` wiring against firmware.
- Confirm the HX711 board is connected to XIAO `GND`.

### Raw value stuck at one number

Likely causes:

- HX711 not ready.
- `DT` line stuck.
- Wrong GPIO selected.
- Broken jumper.

Checks:

- Try different XIAO GPIO pins.
- Re-seat jumpers.
- Inspect solder joints.

### Inverted signal

Likely causes:

- Bridge signal polarity is reversed.
- Sensor orientation differs from the assumed direction.

Checks:

- If all four sensors respond with the same inverted direction, note it and continue.
- If only one sensor is inverted, inspect that sensor's combinator input wiring and orientation.

Do not solve sign direction with calibration logic yet. First make all four sensors contribute consistently.

### Noisy signal

Likely causes:

- Loose bench wiring.
- Long unshielded sensor wires.
- Moving wires during measurement.
- USB power noise.
- Mechanically unstable sensors.

Checks:

- Keep wires still.
- Shorten temporary wiring where practical.
- Keep sensor wires away from USB and power wires.
- Use a simple average in the serial printout for readability.
- Test with the sensors resting on a firm surface.

### One sensor not contributing

Likely causes:

- Open sensor wire.
- Bad connector.
- Wrong combinator pad.
- Sensor damaged.
- Sensor connected with reversed or missing lead.

Checks:

- Move the suspect sensor to another combinator input.
- Move a known-good sensor to the suspect input.
- Inspect connector continuity.
- Use the fifth sensor as a substitute if needed.

Do not proceed to platform integration until all four active sensors affect the raw reading.

## 7. Pass criteria for bring-up v0

Bring-up v0 passes when:

- XIAO is powered over USB-C.
- HX711 is powered from XIAO `3V3`.
- Raw readings print over serial.
- No-load readings are reasonably stable on the bench.
- Pressing each of the four sensors changes the raw value.
- All four sensors have the same sign convention.
- Combined sensor presses produce a larger response than a single press.
- Wiring and pin mapping are documented.

## 8. What not to do yet

Do not do these during bring-up v0:

- No battery power.
- No battery optimization.
- No deep sleep.
- No enclosure electronics.
- No electronics mounting in the printed platform.
- No MQTT.
- No Wi-Fi.
- No final calibration.
- No salt-container fill estimate.
- No button or LED integration.
- No long-term unattended testing.

Only after raw readings are trustworthy should the project move to calibration, low-power firmware, enclosure planning, or platform-integrated electronics.

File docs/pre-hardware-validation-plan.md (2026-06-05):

# Pre-Hardware Validation Plan

Date: 2026-06-05

## Summary

No load sensors have been purchased yet. Before buying them, SaltScale can still reduce meaningful risk by validating geometry, printability, installation constraints, and service motions.

The highest-impact pre-hardware work is not electronics and not full-platform printing. It is:

1. Measure the real salt container and installation space.
2. Print non-sensor fit coupons for the critical clearances.
3. Validate seam hardware geometry with cheap generic M3 inserts/screws/dowels or printed stand-ins.
4. Validate upper support/grate contact with the real container.

Important boundary:

Pre-hardware validation cannot prove sensor accuracy, bridge wiring, calibration stability, or true load-cell contact behavior. It can prevent buying sensors for a geometry that is obviously wrong.

## Ranked uncertainties

## 1. Real salt container bottom and support pattern

Impact: Highest.

Why it matters:

`concept_v2` added a removable upper support grate because the container bottom is unknown. If the container bottom only contacts a narrow rim, the grate may be unnecessary. If the bottom is flexible or has molded ribs/feet, the grate may be essential or may need a different shape. This affects the whole upper carrier before sensor hardware matters.

How to test without buying sensors:

- Measure the actual container bottom diameter, foot/rib pattern, and flat contact areas.
- Place the empty container on a flat table with paper strips under likely contact zones.
- Add safe ballast if available, such as water jugs or bagged salt, and repeat the paper-strip/contact test.
- Print the support grate only, or make a cardboard/MDF/foam-board mockup of the grate footprint, and check whether it improves stability.

Required method:

- Measurement.
- Low-cost mockup.
- Optional print: support grate.

Cost and effort:

- Cost: USD 0-2 for paper/cardboard mockup; about USD 1-3 filament if printing the grate.
- Effort: 30-90 minutes for measurement and contact mapping; 2-4 hours print time if printing the grate.

What becomes validated:

- Whether the annular carrier alone is plausible.
- Whether the support grate is needed.
- Whether the support grate should be cross-shaped, disk-like, wider, narrower, or removable.
- Whether the 300 mm centering lip clearance is reasonable for the actual container.

Decision gate:

- If the container rocks or sags without center support, keep the grate or redesign it before buying sensors.
- If the container bottom does not contact the modeled grate, revise the upper support geometry before buying sensors.

## 2. Installation envelope and service access

Impact: Very high.

Why it matters:

The platform is meant for a utility closet or meter cupboard. If the 320 mm footprint, 39 mm height, container removal path, or sensor service direction does not fit the real installation, sensor selection is premature.

How to test without buying sensors:

- Cut a 320 mm diameter paper/cardboard footprint.
- Place it in the intended installation location.
- Add a 39 mm height spacer or stack of cardboard to represent platform height.
- Test whether the salt container can be lifted out safely.
- Check whether a user can access the outer sensor station side for service.

Required method:

- Measurement.
- Cardboard/foam-board mockup.

Cost and effort:

- Cost: USD 0-5.
- Effort: 30-60 minutes.

What becomes validated:

- Platform footprint.
- Platform height tolerance.
- Clearance around walls, pipes, and cabinet edges.
- Whether the container can be removed for service.
- Whether outward sensor cable/service access is realistic.

Decision gate:

- If the container cannot be removed, the current serviceability concept fails and must be redesigned before buying sensors.
- If the 320 mm ring does not fit, reduce envelope or change architecture before buying sensors.

## 3. Sensor-station placeholder fit and service motion

Impact: Very high.

Why it matters:

Even without a real sensor, the station can be checked with a 38 x 38 x 12 mm dummy block. This tests whether the CAD’s assumed envelope is printable, removable, and serviceable. It does not prove the real sensor will fit, but it proves the design can accept the current placeholder cleanly.

How to test without buying sensors:

- Print `concept_v2_sensor_station.stl`.
- Print or make a 38 x 38 x 12 mm dummy block from scrap plastic, wood, acrylic, or stacked cardboard.
- Print or make the upper and lower pad stand-ins.
- Insert and remove the dummy block through the open outer side.
- Check guide clearances using paper strips or feeler gauges.
- Check that the upper pad can be placed and removed without binding.

Required method:

- Print.
- Measurement.

Cost and effort:

- Cost: about USD 1-3 filament.
- Effort: 4-7 hours print time; 30-60 minutes inspection.

What becomes validated:

- The station prints without supports.
- Guide rails are printable and robust.
- The current 0.7 mm placeholder clearance is plausible.
- Sensor service motion is physically possible.
- The open outer side is usable.
- Pad handling is realistic.

Decision gate:

- If the dummy block binds, increase clearance or change guide geometry before buying sensors.
- If the block can fall out too easily, add a non-trapping retention feature before buying sensors.

## 4. Overload stop and pad-stack Z tolerance

Impact: High.

Why it matters:

The overload stop target is about 1 mm clearance. Real printed Z tolerance, pad thickness, and placeholder height can consume that margin. If the stops touch during normal unloaded assembly, the scale will bypass sensors.

How to test without buying sensors:

- Use the printed sensor station.
- Use a 12 mm dummy sensor block.
- Use pad stand-ins matching the modeled lower and upper pad thickness.
- Measure the gap from upper pad underside to overload stop tops.
- Repeat with intentionally varied dummy thicknesses, such as 11.5 mm, 12.0 mm, and 12.5 mm.

Required method:

- Print.
- Measurement.

Cost and effort:

- Cost: USD 0-3 after the sensor-station print.
- Effort: 30-60 minutes.

What becomes validated:

- Whether 1 mm stop clearance survives real print tolerances.
- Whether pad thickness needs adjustment.
- Whether overload stops need to be lower, adjustable, or separate.

Decision gate:

- If measured clearance is under about 0.5 mm with nominal dummy parts, revise before buying sensors.
- If clearance is over about 1.5-2.0 mm, sensor protection may be weak and should be reconsidered.

## 5. Seam hardware geometry

Impact: High.

Why it matters:

`concept_v2` relies on upper-only and lower-only seam bridge plates, M3 heat-set inserts, and 4 mm dowel sockets. If these are hard to install, split PETG, or misalign, the segmented architecture becomes unpleasant even if the sensor idea is good.

How to test without buying sensors:

- Print a small seam coupon or one lower segment corner region.
- If generic M3 inserts, M3 screws, and 4 mm dowels are already available, test them.
- If not, use printed or drill-bit stand-ins for dowel sizing and measure the pockets.
- Heat-set one insert and inspect for splitting, pullout, and tilt.
- Screw on a bridge plate and check whether it clamps without bending.

Required method:

- Print.
- Measurement.
- Optional cheap generic hardware, not sensor-specific hardware.

Cost and effort:

- Cost: USD 1-5 filament for a coupon; USD 5-15 if buying generic inserts/screws/dowels.
- Effort: 2-5 hours including print and installation checks.

What becomes validated:

- Insert pocket diameter/depth.
- Heat-set installation access.
- Dowel socket fit.
- Seam bridge plate screw access.
- Whether upper-only/lower-only joining is practical.

Decision gate:

- If inserts split bosses, enlarge bosses or change insert dimensions.
- If dowels are too tight after printing, increase socket diameter before buying sensors.

## 6. Upper carrier to lower base non-contact

Impact: High.

Why it matters:

The design depends on no upper-to-lower load bypass except overload stops. This can be checked with dummy blocks before sensors exist.

How to test without buying sensors:

- Print one lower segment and one upper segment, or use partial coupons if created.
- Use dummy blocks and pads to represent the sensor stack.
- Assemble the local stack.
- Use paper strips around guide rails, stops, and nearby base features to confirm no unintended contact.
- Add a small load and check whether contact occurs anywhere except the pad stack or intended overload stops.

Required method:

- Print.
- Measurement.
- Simple load test with household weights.

Cost and effort:

- Cost: about USD 4-8 filament for one quadrant-scale test if using full segment prints.
- Effort: 14-24 hours print time; 1-2 hours inspection.

What becomes validated:

- Local upper/lower spacing.
- Guide rail vertical clearance.
- Upper pad alignment.
- Whether the serviceable stack height is plausible.

Decision gate:

- If paper strips show normal contact outside the dummy sensor stack, revise geometry before buying sensors.

## 7. PETG warping and flatness of large segments

Impact: Medium-high.

Why it matters:

Sensor readings will be sensitive to uneven seating. Large flat PETG segments can warp, and a warped lower or upper ring can create preload differences.

How to test without buying sensors:

- Print one lower segment.
- Print one upper segment.
- Place each on a known flat surface.
- Check rocking, corner lift, and seam flatness.
- Measure flatness with feeler gauges or paper strips.

Required method:

- Print.
- Measurement.

Cost and effort:

- Cost: about USD 4-8 filament combined.
- Effort: 13-22 hours print time; 30-60 minutes inspection.

What becomes validated:

- PETG settings for large annular segments.
- Need for brim/enclosure.
- Whether segment thickness is adequate.
- Whether seam features distort during cooling.

Decision gate:

- If segments warp enough to rock, tune print settings or revise geometry before buying sensors.

## 8. Contact pad material and shape options, without sensors

Impact: Medium.

Why it matters:

The real sensor will need repeatable contact surfaces. Printed PETG pads may creep. Metal pads are preferred, but their size and handling can be evaluated before buying sensors.

How to test without buying sensors:

- Prepare candidate pad stand-ins: printed PETG, washers, small metal plates, acrylic squares.
- Place them in the printed station with dummy blocks.
- Check seating, rocking, handling, and removal.
- Leave a weighted dummy stack overnight and inspect visible denting in printed pads.

Required method:

- Print or simple fabrication.
- Measurement.

Cost and effort:

- Cost: USD 0-10 depending on scrap material.
- Effort: 1-2 hours plus optional overnight compression test.

What becomes validated:

- Pad size handling.
- Whether metal pads fit the station.
- Whether printed pads are obviously unsuitable.
- Whether pad retention is needed.

Decision gate:

- If pads slide or rotate easily, add a shallow non-trapping locator before buying sensors.

## 9. Salt/debris exposure paths

Impact: Medium.

Why it matters:

Salt dust and damp debris can fall into the sensor station, increase friction, corrode pads, or bridge guide clearances.

How to test without buying sensors:

- Inspect printed station and segment geometry.
- Sprinkle table salt or similar dry granules near the ring and observe where debris collects.
- Vacuum/brush the station and inspect whether debris is easy to remove.

Required method:

- Print.
- Observation.

Cost and effort:

- Cost: negligible after station print.
- Effort: 15-30 minutes.

What becomes validated:

- Whether pocket geometry traps debris.
- Whether cleaning access is adequate.
- Whether drain/relief gaps are needed before release.

Decision gate:

- If salt collects around guides or pad seats, add debris relief before buying sensors.

## 10. CAD/export and slicer workflow

Impact: Medium.

Why it matters:

Bad exports or awkward slicer orientation can waste time before hardware arrives.

How to test without buying sensors:

- Open/slice `concept_v2_sensor_station.stl`, `concept_v2_lower_segment_0.stl`, and `concept_v2_upper_segment_0.stl`.
- Check orientation, support requirements, estimated time, and wall behavior around pockets.
- Confirm units are correct.

Required method:

- Slicer review.
- Optional print preview screenshots or notes.

Cost and effort:

- Cost: USD 0.
- Effort: 30-60 minutes.

What becomes validated:

- Export sanity.
- Support-free assumptions.
- Actual slicer material estimates.
- Whether part naming and workflow are understandable.

Decision gate:

- If slicer requires supports inside functional pockets, revise geometry before buying sensors.

## What cannot be answered before buying sensors

These remain blocked until at least one real sensor is purchased:

- Actual sensor body fit.
- Actual cable exit location.
- Correct contact faces.
- Safe load region.
- Electrical wiring behavior.
- HX711 noise and stability.
- Calibration repeatability.
- Off-center measurement error.
- Long-term sensor drift.
- Sensor corrosion resistance.

## Recommended pre-hardware sequence

1. Measure installation space and salt container.
2. Map the salt container bottom contact pattern.
3. Slice the current v2 exports and check support/time assumptions.
4. Print `concept_v2_sensor_station.stl`.
5. Make a 38 x 38 x 12 mm dummy sensor block.
6. Test dummy insertion/removal, pad seating, and overload stop gap.
7. Test candidate pad materials with the dummy block.
8. Print or mock the support grate and test it against the real container bottom.
9. Print a small seam hardware coupon or one seam region if generic hardware is already available.
10. Only then purchase one sensor for real fit/load/electrical testing.

## Recommendation

Before buying any load sensors, the single highest-value validation is:

```text
Measure the real salt container bottom and installation envelope, then print the sensor station with a dummy 38 x 38 x 12 mm block.
```

If only one physical print is allowed before hardware purchase, print:

```text
concept_v2_sensor_station.stl
```

Do not buy all four sensors until one real sensor has later passed fit, service, load, and repeatability tests in the station.

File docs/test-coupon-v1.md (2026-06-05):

# Test Coupon v1 — Print & Measurement Guide

Purpose
- Validate the riskiest mechanical details before printing a full platform segment: pocket fit, pad fit, overload-stop clearance, dowel fit, and M3 blind pocket behavior.

Coupon dimensions
- Overall coupon XY: 140 × 140 mm.
- Base thickness: 6 mm (matches module base top reference).
- Sensor pocket: uses the `sensor_module_v3` pocket (38 × 38 × 12 mm) and is placed centered on the coupon.

Recommended print orientation
- Lay the coupon flat on the build plate with the coupon lower face down (same orientation used in CAD). This preserves pocket verticality and hole tolerances.

What this coupon validates
- Sensor placeholder fit in pocket (insert/remove force, lateral play).
- Lower pad seating and contact height.
- Upper pad seating and clearance to module stops (verify ~1.0 mm gap before stop contact).
- Module overload stop position and clearance.
- Dowel hole fit (4.2 mm clearance) and boss strength for press-fit or slip-fit dowels.
- M3 blind pocket depth and screw fit.

Measurements to make after printing
- Pocket internal XY dimensions at several depths (top/mid/bottom) — compare to nominal 38 mm and verify clearance.
- Vertical clearance: measure underside of upper pad seating to module stop top (should be ≈1.0 mm gap).
- Dowel hole ID (mm) and roundness — confirm fit with your chosen dowel (e.g., 4.0 mm).
- M3 pocket depth and diameter — verify screw engagement and that screw head clears surrounding features.

Print settings (starting point)
- Material: PETG
- Nozzle: 0.4 mm, temp 240–250 °C; bed 80–90 °C
- Layer height: 0.2 mm for coupon; 0.15–0.2 mm for pads if higher accuracy needed
- Perimeters: 3–4; infill 20–30%
- Brim: 8–12 mm recommended

Procedure
1. Slice and print `test_coupon_v1.stl` and the three part STLs (`upper_pad`, `lower_pad`, `sensor_placeholder`).
2. After cooling, remove brim and clean any stringing.
3. Try inserting `sensor_placeholder` into the pocket; note insertion/removal force and lateral play.
4. Seat `lower_pad` and then `sensor_placeholder` and `upper_pad` in sequence; measure the gap to module stops.
5. Test dowel fit and M3 screw insertion.

Decision gates
- If pocket clearance is too tight (>0.1–0.2 mm interference), increase pocket clearance in CAD (e.g., to 0.6 mm) and repeat coupon print.
- If dowel boss or hole is too loose/tight, adjust boss geometry or dowel diameter.
- If M3 pocket depth is incorrect, update pocket depth in `platform_v6.py` and re-export.

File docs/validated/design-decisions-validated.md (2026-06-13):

# Validated Design Decisions

Date: 2026-06-06

## Purpose

This record captures SaltScale design decisions that are now based on physical validation prints, not only CAD assumptions.

These decisions should be treated as frozen defaults for future `concept_v2` CAD work unless a later, larger print produces a clear conflicting result.

## Captured M3 Nut Pocket

Physical result:

- M3 nut requires light press-fit insertion.
- Nut does not rotate.
- Nut does not fall out.
- M3 bolt fit is correct.

Decision:

- Freeze current captured M3 nut pocket dimensions.
- Do not enlarge the captured nut pocket unless future larger seam or quadrant prints show assembly issues.
- Use captured standard M3 nuts as the default no-heat-set segment-joining direction.

Current accepted dimensions are documented in `docs/bolted-captured-nut-coupon-plan.md`.

## Label Standard

Physical result:

- `7-8 mm` text is clearly readable.
- `0.8 mm` engraved depth is sufficient.
- Smaller text becomes difficult to read.
- Larger labels are preferred.

Decision:

- Standard label height: `7-8 mm`.
- Standard engraved depth: `0.8 mm`.
- Use short labels whenever possible.

Preferred label words:

- `IN`
- `OUT`
- `PAD`
- `STOP`
- `SENSOR`
- `NUT`
- `M3`
- `KEY`

Avoid long labels on validation or functional parts unless the part has enough non-contact area.

## Engraved vs Raised Text

Physical result:

- Labels must not interfere with mechanical interfaces.
- Many SaltScale parts stack, slide, clamp, or contact each other.

Decision:

- Engraved text is the default for all functional parts.
- Raised text is not allowed on functional contact surfaces.
- Raised text may only be used on presentation or demo parts where it cannot affect assembly or load paths.

Functional parts include:

- sensor stations
- upper pads
- lower pads
- support grate interfaces
- bridge plates
- seam hardware
- upper carrier segments
- lower base segments

## Support-Grate Tab/Slot Clearance

Physical result:

- `0.4`, `0.6`, and `0.8 mm` per side variants all remained removable.
- None of the tested variants fell out.
- All tested variants still allowed visible/playable movement.
- `0.4 mm per side` had the least play and is the best tested option.

Decision:

- Use `0.4 mm per side` as the current default support-grate tab/slot clearance.
- Do not make the support-grate interface looser by default.
- If the full upper-carrier implementation still feels too loose, create and test a `0.2 mm per side` variant before changing the active design.
- Future work may explore self-centering or tapered support-grate locator geometry, but that is an improvement path, not a reason to loosen the current default.

## Concept v4 Seam Locator Clearance

Physical result:

- `0.5 mm per side` showed unnecessary play.
- `0.4 mm per side` still showed unnecessary play.
- `0.3 mm per side` remained easy to assemble.
- `0.3 mm per side` provided the best alignment of the tested variants.
- Locators are positioning features only.
- M3 fasteners provide clamping.

Decision:

- Use `0.3 mm per side` as the active `concept_v4` seam locator clearance.
- Do not create a tighter locator variant unless a future full-size segment print shows measurable play.
- Keep M3 bolts responsible for clamping.
- Keep printed locators responsible only for segment positioning.

## Future CAD Rule

For all future CAD work:

- Use engraved text by default.
- Use `7-8 mm` text height.
- Use `0.8 mm` engraving depth.
- Avoid long labels.
- Do not re-test label geometry unless a future print reveals a problem.

## Superseded Guidance

Earlier documents may mention smaller labels, shallow engraving, heat-set insert-first seams, or dowel-focused seam tests. Those notes are historical unless they are explicitly repeated in this document or in newer `concept_v2` strategy docs.

Specifically:

- `docs/test-coupon-v1.md` is historical platform-v6-era coupon guidance.
- `docs/coupon-label-reference.md` documents an earlier label pass and should not override the label standard above.
- `docs/label-readability-coupon.md` remains useful as the test description, but the validated decision is now this document.

## Next Validation Step

After freezing these small-interface decisions, proceed to larger same-geometry checks:

1. Lower captured-nut bolted seam coupon.
2. Upper captured-nut bolted seam coupon.
3. One realistic quadrant stack with lower segment, upper segment, support grate using `0.4 mm per side` clearance, sensor stack, and same-layer seam hardware.

## Applied To Full Concept v2

The validated captured M3 nut pocket, default bolted bridge-plate seam strategy, engraved label standard, and v3-style sensor locator direction have been applied to `cad/src/concept_v2.py`.

Support-grate clearance is now frozen at `0.4 mm per side` as the current default. Full upper-carrier integration still needs a larger-part fit check.

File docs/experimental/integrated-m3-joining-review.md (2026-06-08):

# Integrated M3 Joining Review

Date: 2026-06-06

## Summary

Integrated M3 joining is a better default direction than separate printed bridge plates. The bridge-plate approach is mechanically understandable, but it creates too many extra printed parts, too many bolts, and too many assembly steps.

The recommended candidate is a four-segment integrated-lug strategy: four lower segments, four upper segments, integrated same-layer lap lugs, and captured M3 nuts printed into the neighboring segment. This keeps the simple one-sensor-per-quadrant mental model while removing separate bridge plates entirely.

A new CAD candidate was created:

```text
cad/src/concept_v4_integrated_joining.py
```

`concept_v4` is not a release replacement yet. It needs physical validation of the integrated lugs before retiring `concept_v2` or `concept_v3`.

## Integrated Joint Concept

Each segment has two seam roles:

- One seam edge has integrated lap lugs with M3 clearance holes.
- The opposite seam edge has captured M3 nut pockets.

Assembly uses:

```text
M3 bolt -> integrated lug on segment A -> clearance hole/nut pocket in segment B -> captured standard M3 nut
```

There are no separate printed bridge plates. The connection is still same-layer only:

- lower segment to lower segment
- upper segment to upper segment

No fastener, lug, nut pocket, or printed feature connects upper to lower.

## Option 1: Four-Segment Integrated Joining

Description:

- 4 lower segments.
- 4 upper segments.
- Each seam uses integrated lugs and captured M3 nuts.
- 2 M3 bolts per seam per layer.
- Split two-bar support grate retained from the print-efficiency work.

Approximate largest part dimensions from the v4 CAD candidate:

| Part | Approximate envelope |
| --- | ---: |
| Lower segment with integrated lug | 175 x 167 x 21 mm |
| Upper segment with integrated lug | 169 x 164 x 18 mm |
| Support grate bar | 178 x 22 x 4 mm |

Printed parts for a full mechanical prototype, excluding real sensors:

- 4 lower segments.
- 4 upper segments.
- 2 support grate bars.
- 4 lower pads.
- 4 upper pads.
- Optional 4 printed sensor placeholders for dry assembly.

M3 hardware:

- Lower ring: 4 seams x 2 bolts = 8 M3 bolts and 8 M3 nuts.
- Upper ring: 4 seams x 2 bolts = 8 M3 bolts and 8 M3 nuts.
- Total: 16 M3 bolts and 16 standard M3 nuts.

Estimated print plates:

- About 8 major segment plates plus nested small parts.
- The split grate bars and pads can likely be nested with other plates.

Assembly complexity:

- Low to medium.
- No bridge plates to sort, orient, or hold.
- Fewer bolts than concept_v2 or concept_v3.

Serviceability:

- Good. One upper quadrant still maps to one sensor region.
- Upper carrier may still need to be lifted for underside upper-lug bolt access, similar to concept_v2 upper bridge service.

Warping risk:

- Similar to concept_v2, slightly higher local risk at integrated lugs because they extend beyond the annular sector.
- Still PETG-friendly and within the Prusa MK4 bed.

Load-path bypass risk:

- Low if lugs remain same-layer only.
- CAD checks found zero overlap between upper and lower segments in the sampled quadrant.

Open-source maker fit:

- Strong. It uses common M3 bolts/nuts, no heat-set inserts, no dowels, and fewer parts.

Verdict:

- Best current default candidate if the integrated lugs physically validate.

## Option 2: Eight-Segment Integrated Joining

Description:

- 8 lower segments.
- 8 upper segments.
- Integrated lugs replace bridge plates.

Printed parts:

- 8 lower segments.
- 8 upper segments.
- 2 support grate bars.
- Pads and optional placeholders.

M3 hardware:

- Lower ring: 8 seams x 2 bolts = 16 M3 bolts and 16 M3 nuts.
- Upper ring: 8 seams x 2 bolts = 16 M3 bolts and 16 M3 nuts.
- Total: 32 M3 bolts and 32 standard M3 nuts.

Estimated print plates:

- About 6 major plates if parts are packed efficiently.

Assembly complexity:

- Medium to high. Smaller parts are easier to print, but there are twice as many seams.

Serviceability:

- Mixed. Smaller upper parts are easier to handle, but there are more fasteners and more segment boundaries.

Warping risk:

- Lower than four-segment large parts because each segment is smaller.

Load-path bypass risk:

- Low by principle, but more seams create more chances for builder error.

Open-source maker fit:

- Good for printers, less good for assembly patience.

Verdict:

- Useful if print bed efficiency is the only goal, but less beginner-friendly than four integrated segments.

## Option 3: Hybrid Segmentation

Description:

- Lower 4 / upper 8, or lower 8 / upper 4.
- Integrated M3 lugs on each layer separately.

Printed parts:

- Between four-segment and eight-segment strategies.

M3 hardware:

- Between 24 and 32 total M3 bolt/nut pairs depending on which layer has eight seams.

Estimated print plates:

- About 7 major plates.

Assembly complexity:

- Medium-high because upper and lower segmentation differ.

Serviceability:

- Potentially good if only the upper is split into 8 pieces, but documentation becomes harder.

Warping risk:

- Better than full four-segment if the larger-risk layer is split.

Load-path bypass risk:

- Low if same-layer rules are obeyed.
- Documentation risk is higher because builders must understand different upper/lower seam patterns.

Open-source maker fit:

- Mixed. It saves some printing pain but adds mental overhead.

Verdict:

- Not the best default. Consider later only if v4 four-segment lugs print poorly.

## Comparison Table

| Strategy | Printed parts excluding real sensors | M3 bolt/nut pairs | Estimated plates | Assembly complexity | Beginner fit |
| --- | ---: | ---: | ---: | --- | --- |
| concept_v2 bridge plates | about 25 plus optional placeholders | 32 | about 9 | Medium | Good but many parts |
| concept_v3 bridge plates | about 42 plus optional placeholders | 64 | about 6 | High | Print-friendly, assembly-heavy |
| 4-segment integrated | about 18 plus optional placeholders | 16 | about 8 | Low-medium | Best balance |
| 8-segment integrated | about 26 plus optional placeholders | 32 | about 6 | Medium-high | Good printability, more assembly |
| Hybrid integrated | about 22 plus optional placeholders | 24-32 | about 7 | Medium-high | Mixed |

## Recommendation

Use four-segment integrated M3 joining as the next candidate to inspect and validate. It does not minimize print plates as aggressively as concept_v3, but it removes the bigger practical burden: loose bridge plates and excessive M3 hardware.

This is the most beginner-friendly path because builders get:

- one lower part per quadrant
- one upper part per quadrant
- no bridge plates
- no dowels
- no heat-set inserts
- standard M3 bolts and nuts
- fewer fasteners

## Concept v4 CAD Candidate

Created:

```text
cad/src/concept_v4_integrated_joining.py
```

Active exports:

```text
cad/exports/active/step/concept_v4_assembly.step
cad/exports/active/step/concept_v4_exploded_assembly.step
cad/exports/active/step/concept_v4_one_quadrant_assembly.step
cad/exports/active/stl/concept_v4_lower_segment_0.stl
cad/exports/active/stl/concept_v4_upper_segment_0.stl
cad/exports/active/stl/concept_v4_support_grate_bar_x.stl
cad/exports/active/stl/concept_v4_support_grate_bar_y.stl
cad/exports/active/stl/concept_v4_lower_pad.stl
cad/exports/active/stl/concept_v4_upper_pad.stl
cad/exports/active/stl/concept_v4_sensor_placeholder.stl
```

## CAD Checks Performed

Initial sampled boolean overlap checks showed:

- Upper segment 0 vs lower segment 0: `0.0 mm^3` overlap.
- Support grate bar X vs upper segment 0: `0.0 mm^3` overlap.
- Support grate bar Y vs upper segment 0: `0.0 mm^3` overlap.
- Support grate bar X vs lower segment 0: `0.0 mm^3` overlap.
- Upper segment 0 integrated lug vs neighboring lower segment 1: `0.0 mm^3` overlap.

## New Risks

- Integrated lugs are part of large ring segments, so a damaged lug may require reprinting the segment instead of only a bridge plate.
- Lugs may be more vulnerable to PETG layer-edge damage during repeated assembly.
- Bolt access and screwdriver angle need physical validation.
- Seam alignment no longer has a separate bridge plate that can be replaced or modified independently.
- The larger lugged segments are slightly bigger than concept_v2 segments, though still within the Prusa MK4 bed.
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

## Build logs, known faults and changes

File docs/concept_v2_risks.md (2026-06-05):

# Concept v2 Risks

Date: 2026-06-04

## What is still uncertain

### Sensor dimensions

The CAD assumes a 38 x 38 x 12 mm sensor placeholder. Real Kiwi/SparkFun style 50 kg sensors may differ in body size, contact face, cable exit, and safe loading region.

Impact:

- Pocket clearance may be wrong.
- Guide rails may touch the sensor body.
- Contact pads may not align with the intended sensing region.

### Sensor loading behavior

Cheap bathroom-scale sensors are not always documented well. The exact intended compression/contact faces need to be confirmed with the purchased part.

Impact:

- Pads may load the wrong part of the sensor.
- Readings may be nonlinear.
- Sensors may be vulnerable to side loading.

### Contact pad material

The CAD shows generic pads. Printed PETG pads may creep or wear under continuous load.

Impact:

- Calibration drift.
- Poor repeatability after removing/reinstalling the salt container.

Preferred prototype direction:

- Test printed pads only as fit placeholders.
- Use metal washers or small metal plates for real measurement tests.

### Annular support and removable grate

`concept_v2` adds a removable upper support grate because the salt container bottom is unknown. The actual container may not need it, or it may need a different support pattern.

Impact:

- Without the grate, the container bottom may sag.
- With the grate, load may concentrate through the central support pattern if the bottom is uneven.

### Seam hardware

M3 insert pockets and 4 mm dowel sockets are modeled, but no exact insert, screw length, washer, or dowel tolerance is selected.

Impact:

- Inserts may be loose or split PETG.
- Dowel sockets may be too tight or too loose.
- Seam bridge plates may need different thickness or screw access.

### Overload stop clearance

The target is approximately 1 mm clearance before stop contact. Real printed Z tolerances, pad thickness, and sensor height variation can easily consume that margin.

Impact:

- Stops may touch during normal use and bypass sensors.
- Stops may sit too low and fail to protect sensors.

### Salt and moisture exposure

The CAD does not yet include drainage, sealing, or corrosion protection.

Impact:

- Sensor corrosion.
- Pad corrosion.
- Salt debris in pockets.
- Increased friction and sensor side loading.

## What should be physically tested first

Test `concept_v2_sensor_station.stl` before printing any full ring segments.

First test set:

1. Print `concept_v2_sensor_station.stl`.
2. Print or prepare lower and upper contact pads.
3. Install one real 50 kg sensor.
4. Check insertion/removal from the open outer side.
5. Check guide clearance with feeler gauges or paper strips.
6. Measure upper pad to overload stop clearance.
7. Apply 5 kg, 10 kg, and 20 kg loads.
8. Remove and reinstall the sensor three times.
9. Repeat measurements after reinstalling.

Second test set:

1. Print `concept_v2_lower_segment_0.stl`.
2. Print `concept_v2_upper_segment_0.stl`.
3. Check that the upper segment seats on the upper pad and not on guide rails/stops.
4. Confirm no upper-to-lower accidental contact.
5. Test one assembled quadrant with a known weight.

Third test set:

1. Print the removable support grate.
2. Place the actual salt container on the upper carrier/grate.
3. Check whether the container bottom contacts ring, grate, or both.
4. Repeat with partial and full salt load if safe.

## Assumptions that remain

- Four sensors wired into one HX711 bridge are acceptable for the required fill-level accuracy.
- A 320 mm outer footprint is acceptable in the installation location.
- The salt container can be removed for service.
- PETG is acceptable for long-term utility-closet loading if metal pads are used.
- The user can install heat-set inserts accurately.
- A 4 mm dowel slip fit is achievable after tuning print holes.
- The support grate is acceptable even if it adds one extra upper part.

## Go/no-go criteria for continuing

Continue to full-ring prototype only if:

- Sensor can be inserted and removed without force.
- Upper pad does not bind in the guide rails.
- Overload stops do not touch during normal load tests.
- Repeated sensor removal/reinstall changes readings only within acceptable prototype tolerance.
- One quadrant test shows stable readings over at least several hours under load.
- The real salt container bottom is supported without rocking.

Stop and revise if:

- Sensor pocket requires prying to remove the sensor.
- Stops touch under ordinary loading.
- PETG pad surfaces visibly dent or polish after short testing.
- Dowel insertion cracks seam bosses.
- The support grate carries load unevenly or causes rocking.
- Salt debris can fall directly into sensor contact areas.

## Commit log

2026-06-04 Restructure repository for CAD firmware and docs
2026-06-04 Add loadcell specification v1
    [bottom_segment_0.step, bottom_segment_0.stl, bottom_segment_1.step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]
2026-06-04 Add validated sensor module v3
    [bottom_segment_0.step, bottom_segment_0.stl, bottom_segment_1.step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]
2026-06-04 Add CAD iterations and load sensor design notes
2026-06-04 Add printable segmented platform v6
2026-06-05 Fix printable concept v2 coupon layouts
2026-06-05 addded several new CAD exports, added concept_v1 and concept_v2 CAD models, added test_coupon_v1 CAD model, added several new documents, and made some modifications to the build script and .gitignore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
    [bottom_segment_0.step, bottom_segment_0.stl, bottom_segment_0__from_flat.step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]
2026-06-08 Concept v4 baseline: integrated seams, round cup locator and repository cleanup
    [bolted_lower_seam_captured_nut_coupon_v1.step, bolted_lower_seam_captured_nut_coupon_v1.stl, bolted_lower_seam_coupon_v1.step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]
2026-06-13 Update concept v4 sensor station validation
    [bolted_lower_seam_captured_nut_coupon_v1.step, bolted_lower_seam_coupon_v1.step, bolted_lower_seam_coupon_v2.step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]
2026-06-15 Validate concept v5 sensor cartridge
    [concept_v5_bridge_load_puck.step, concept_v5_bridge_load_puck.stl, concept_v5_cartridge_assembly.step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]
